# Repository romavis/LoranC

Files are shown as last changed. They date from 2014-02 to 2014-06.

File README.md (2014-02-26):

LORAN C (USSR "Chayka") receiver project
----

####Initial idea of project:
To build Loran-C navigational receiver with digital signal processing.  
Loran-C is (was?) a ground-based longwave navigational system working on frequency of 100 KHz, that was heavely used both by civilians and military prior to wide GPS adoption.

Receiver should also be able to lock onto signal of USSR "Chayka" system, similar to Loran-C, due to my location (nearest transmitter chain is "Chayka" GRI 8000)

####Licensed under:



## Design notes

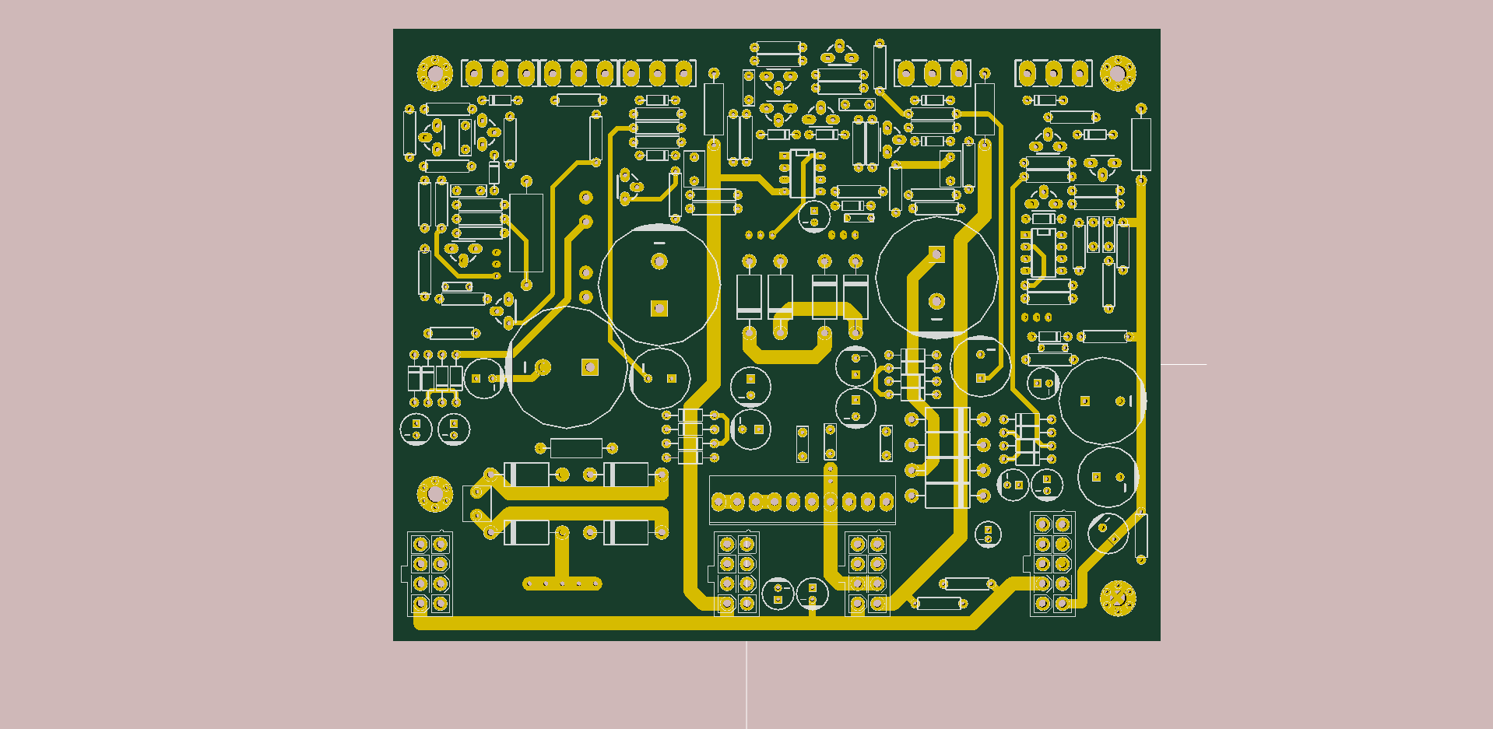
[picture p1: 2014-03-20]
hardware/power_supply/pcb_plots/power_supply_front.png

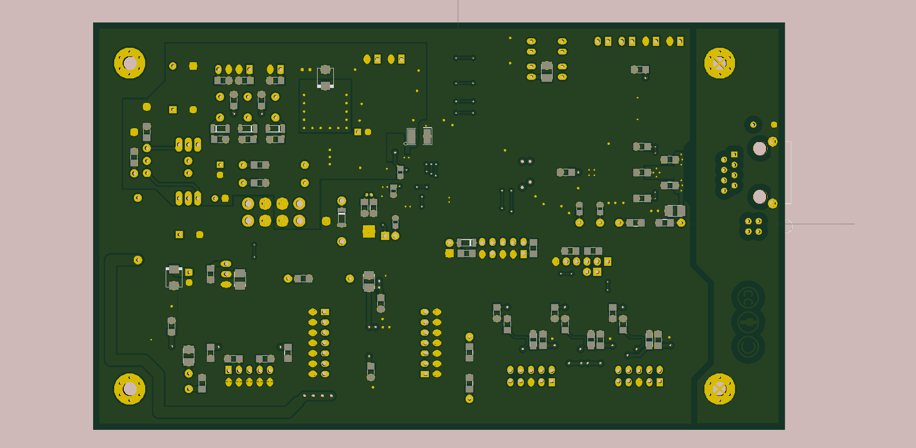
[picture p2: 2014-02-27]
hardware/proc_board/pcb_plots/loran_c_proc_board_back.png

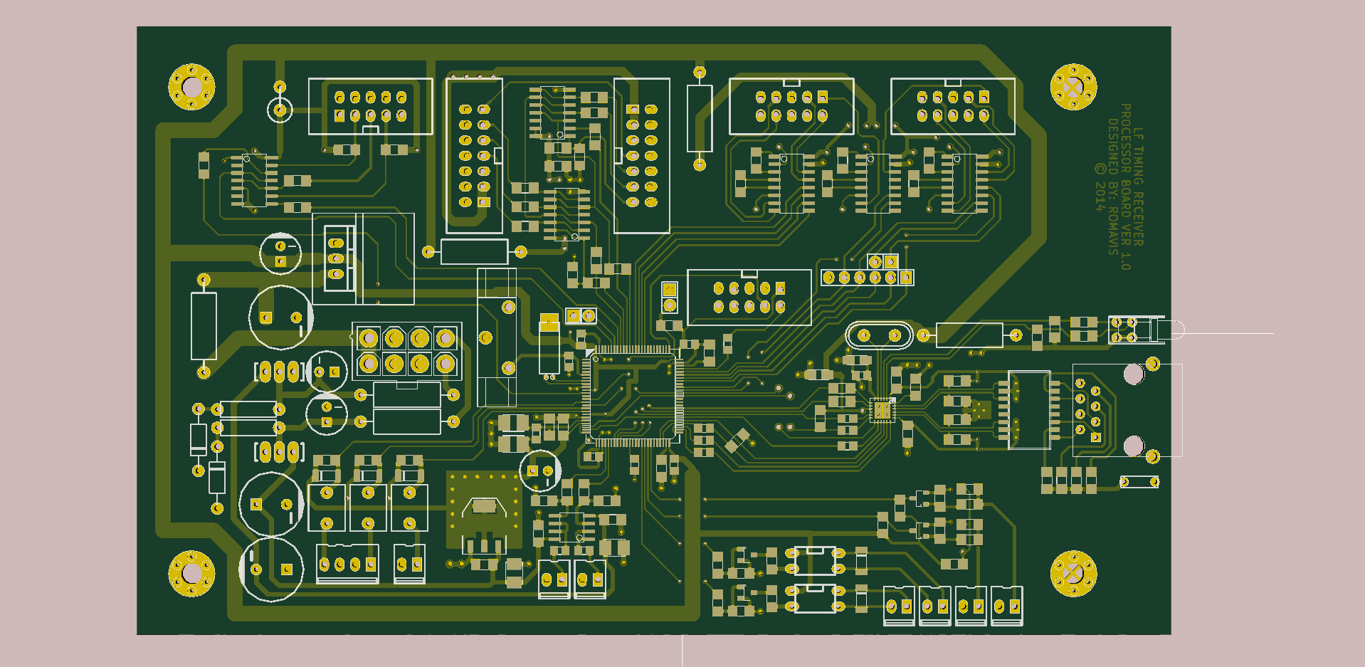
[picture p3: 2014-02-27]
hardware/proc_board/pcb_plots/loran_c_proc_board_front.png

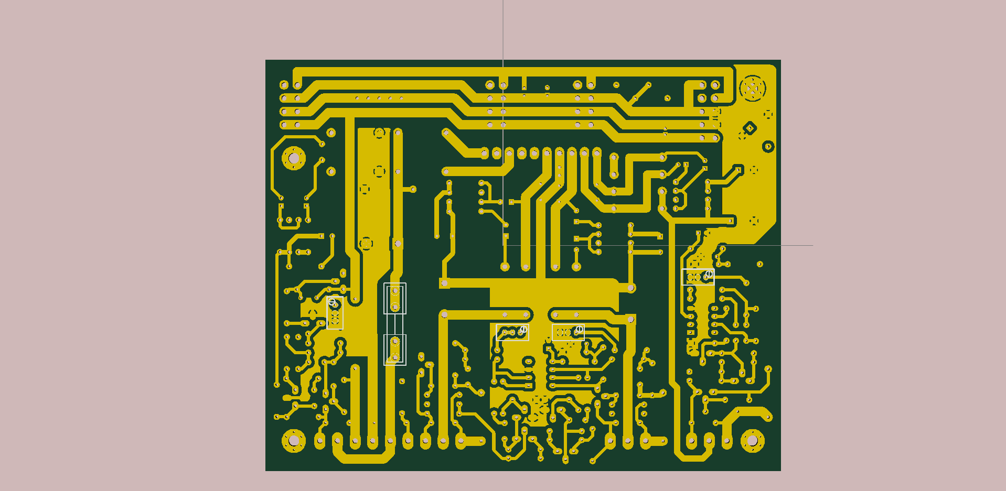
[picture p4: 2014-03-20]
hardware/power_supply/pcb_plots/power_supply_bottom.png

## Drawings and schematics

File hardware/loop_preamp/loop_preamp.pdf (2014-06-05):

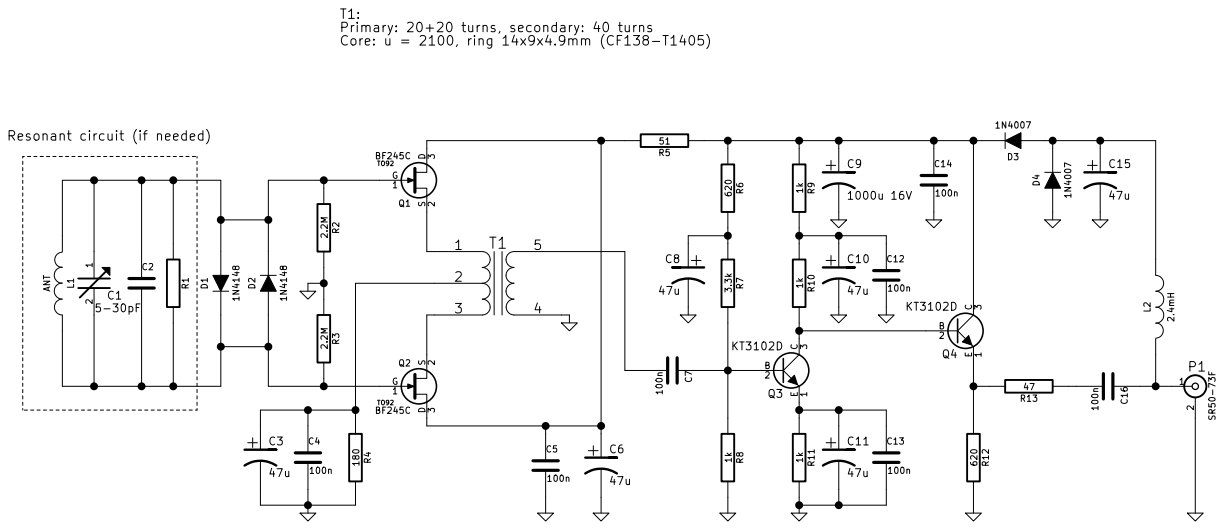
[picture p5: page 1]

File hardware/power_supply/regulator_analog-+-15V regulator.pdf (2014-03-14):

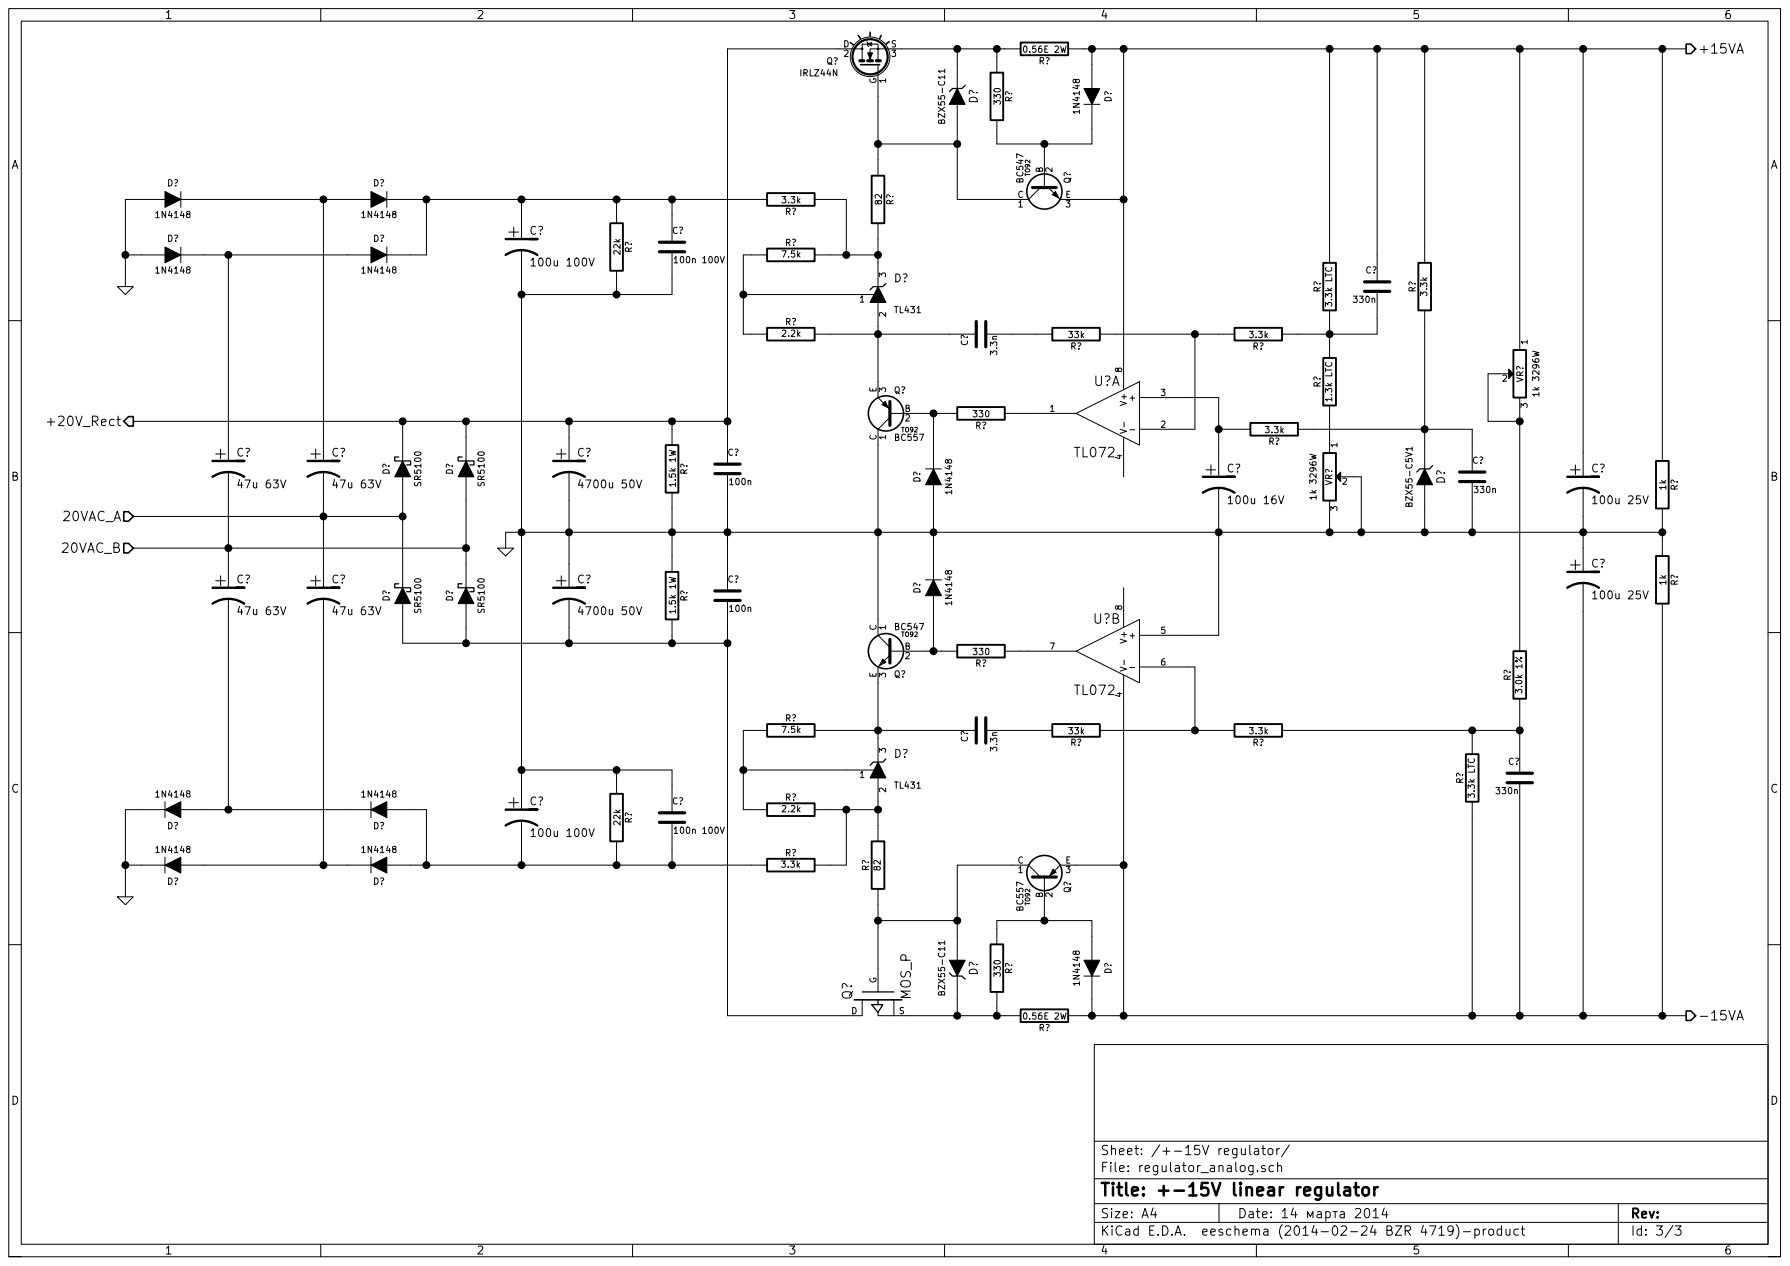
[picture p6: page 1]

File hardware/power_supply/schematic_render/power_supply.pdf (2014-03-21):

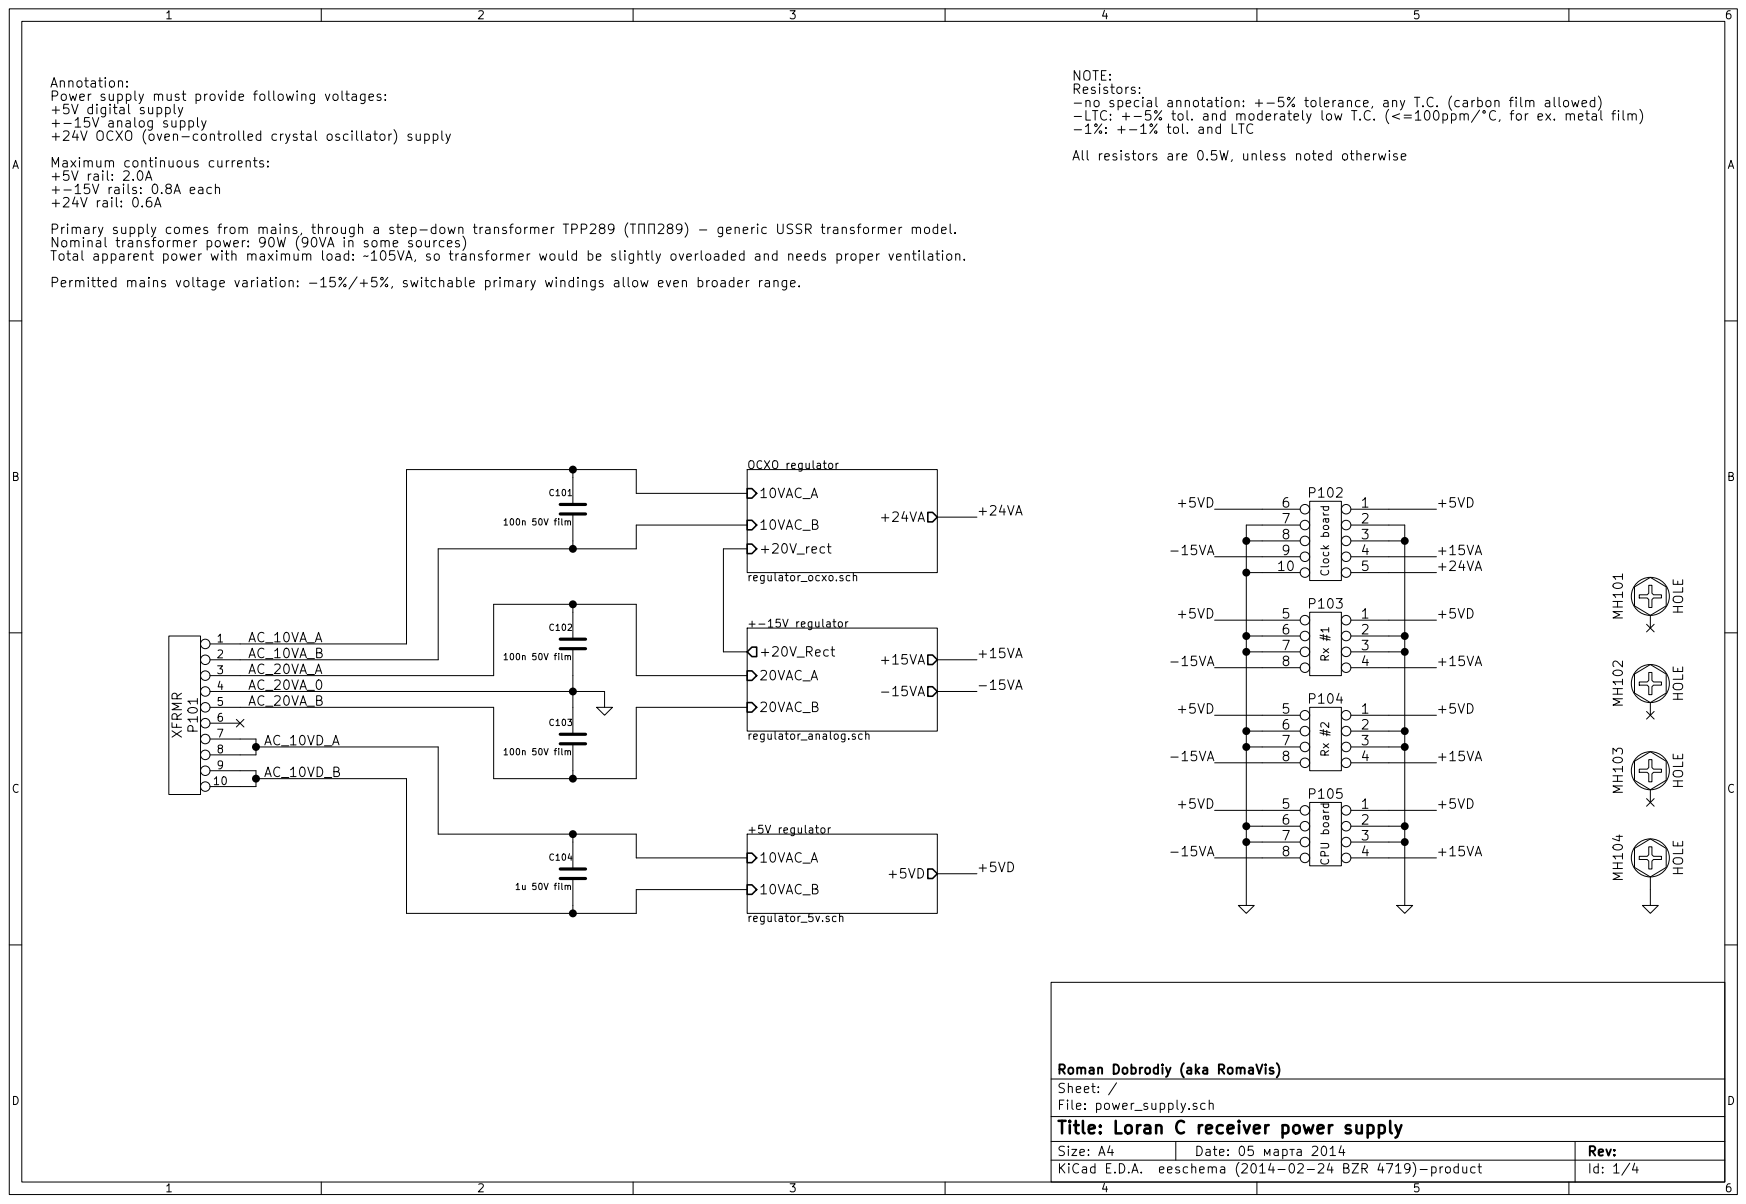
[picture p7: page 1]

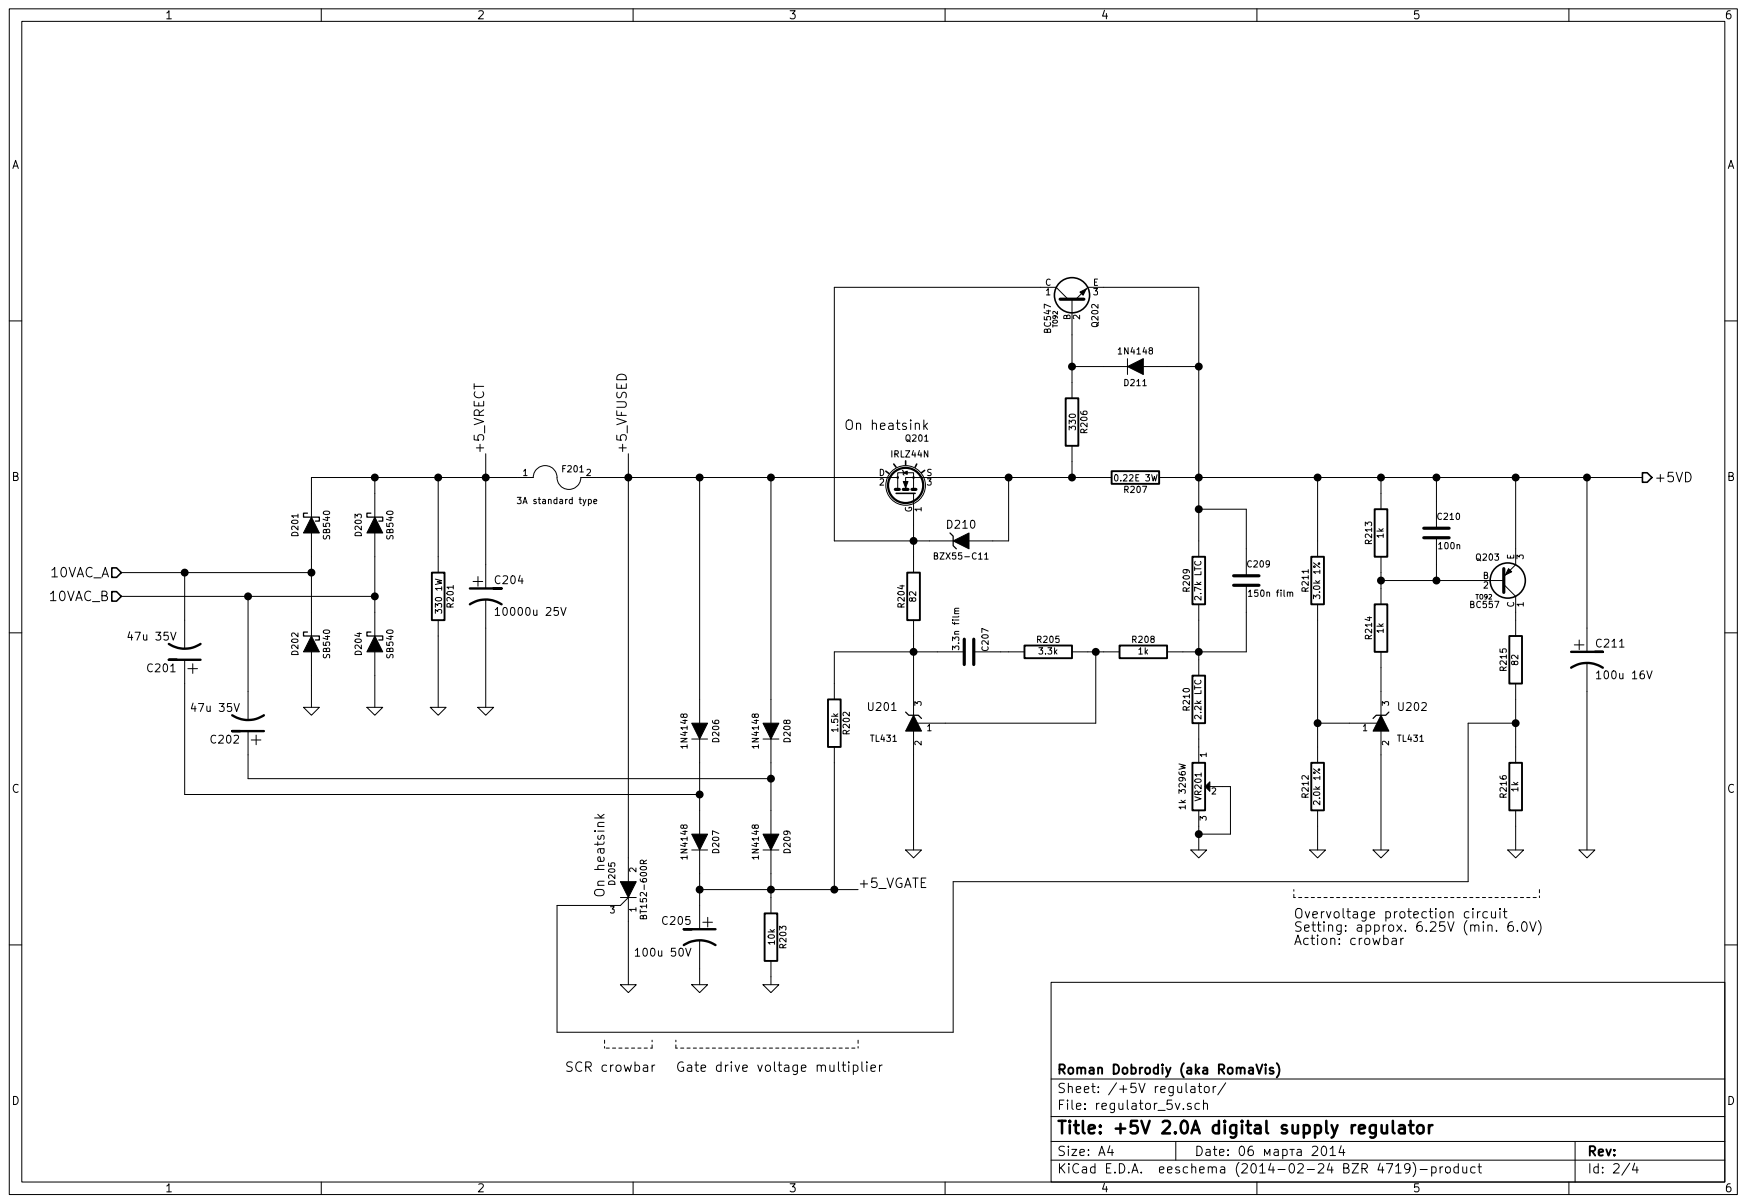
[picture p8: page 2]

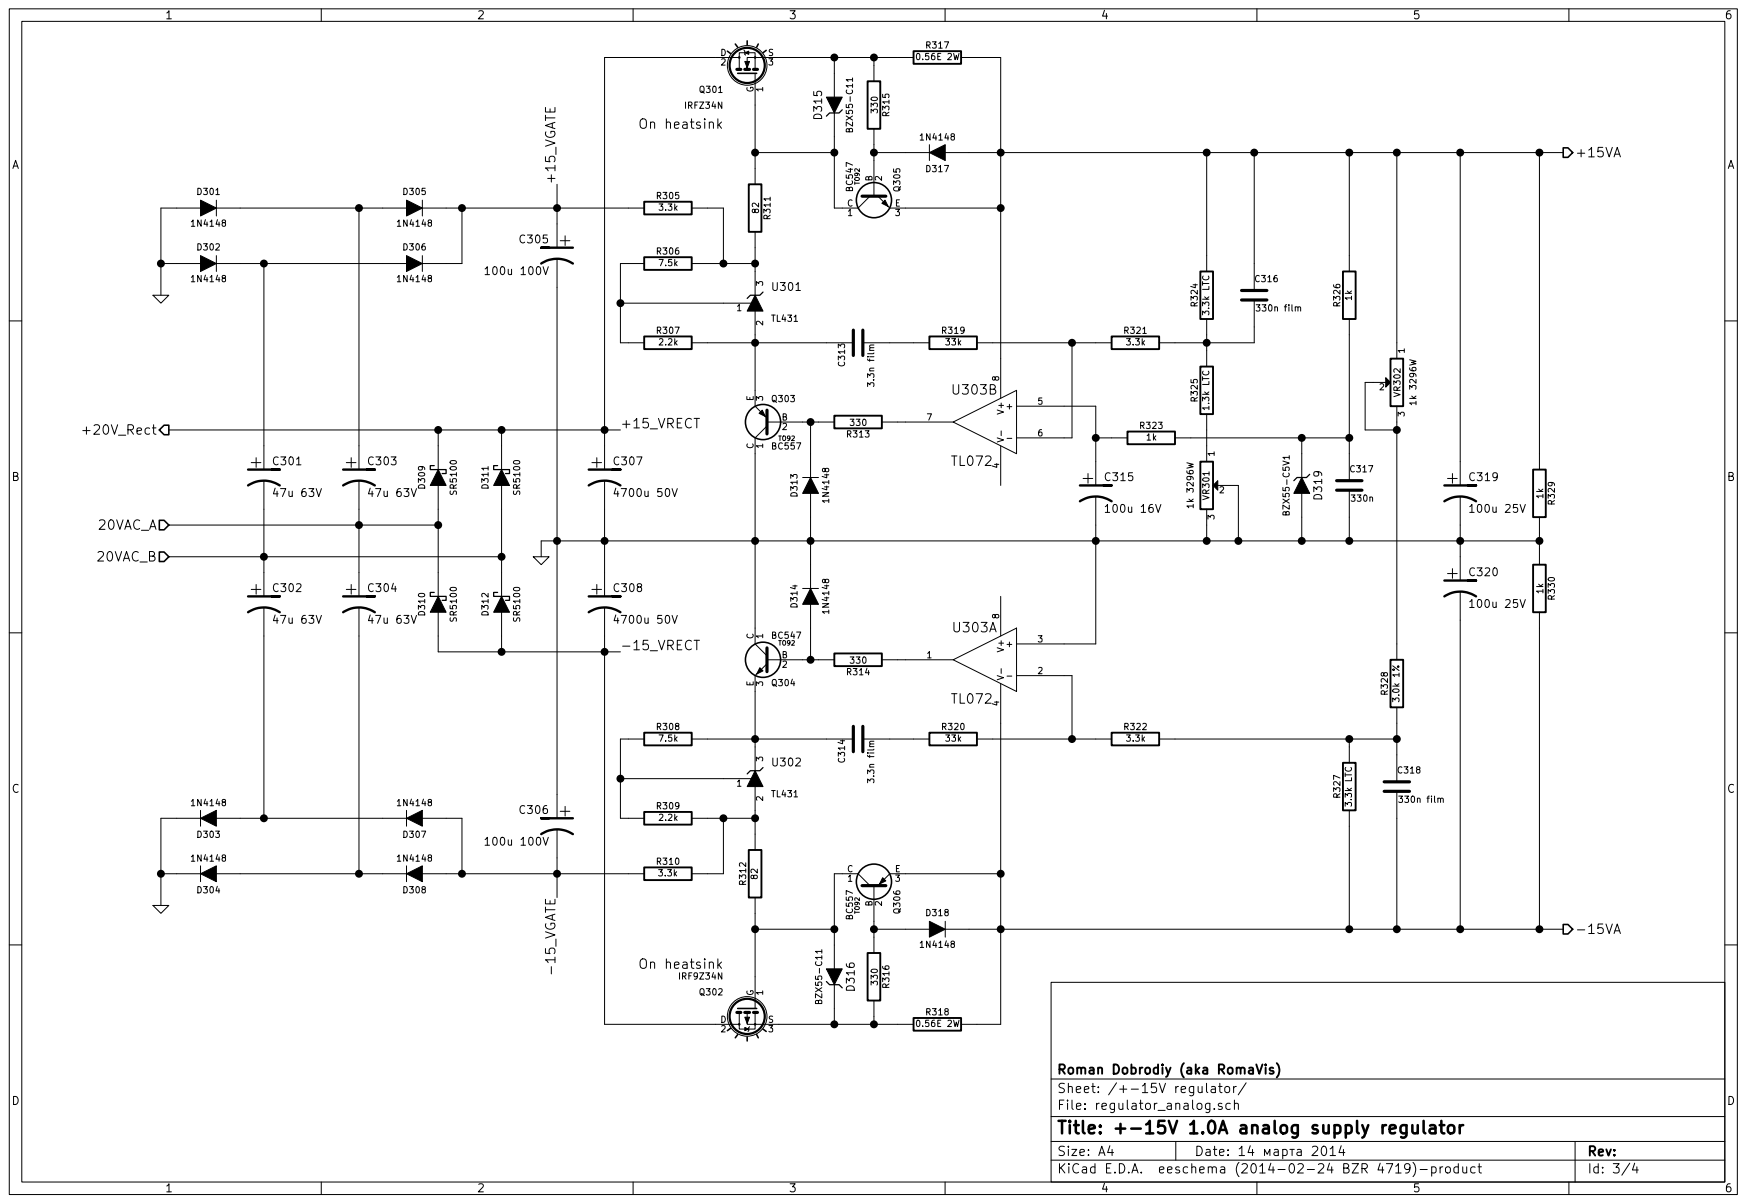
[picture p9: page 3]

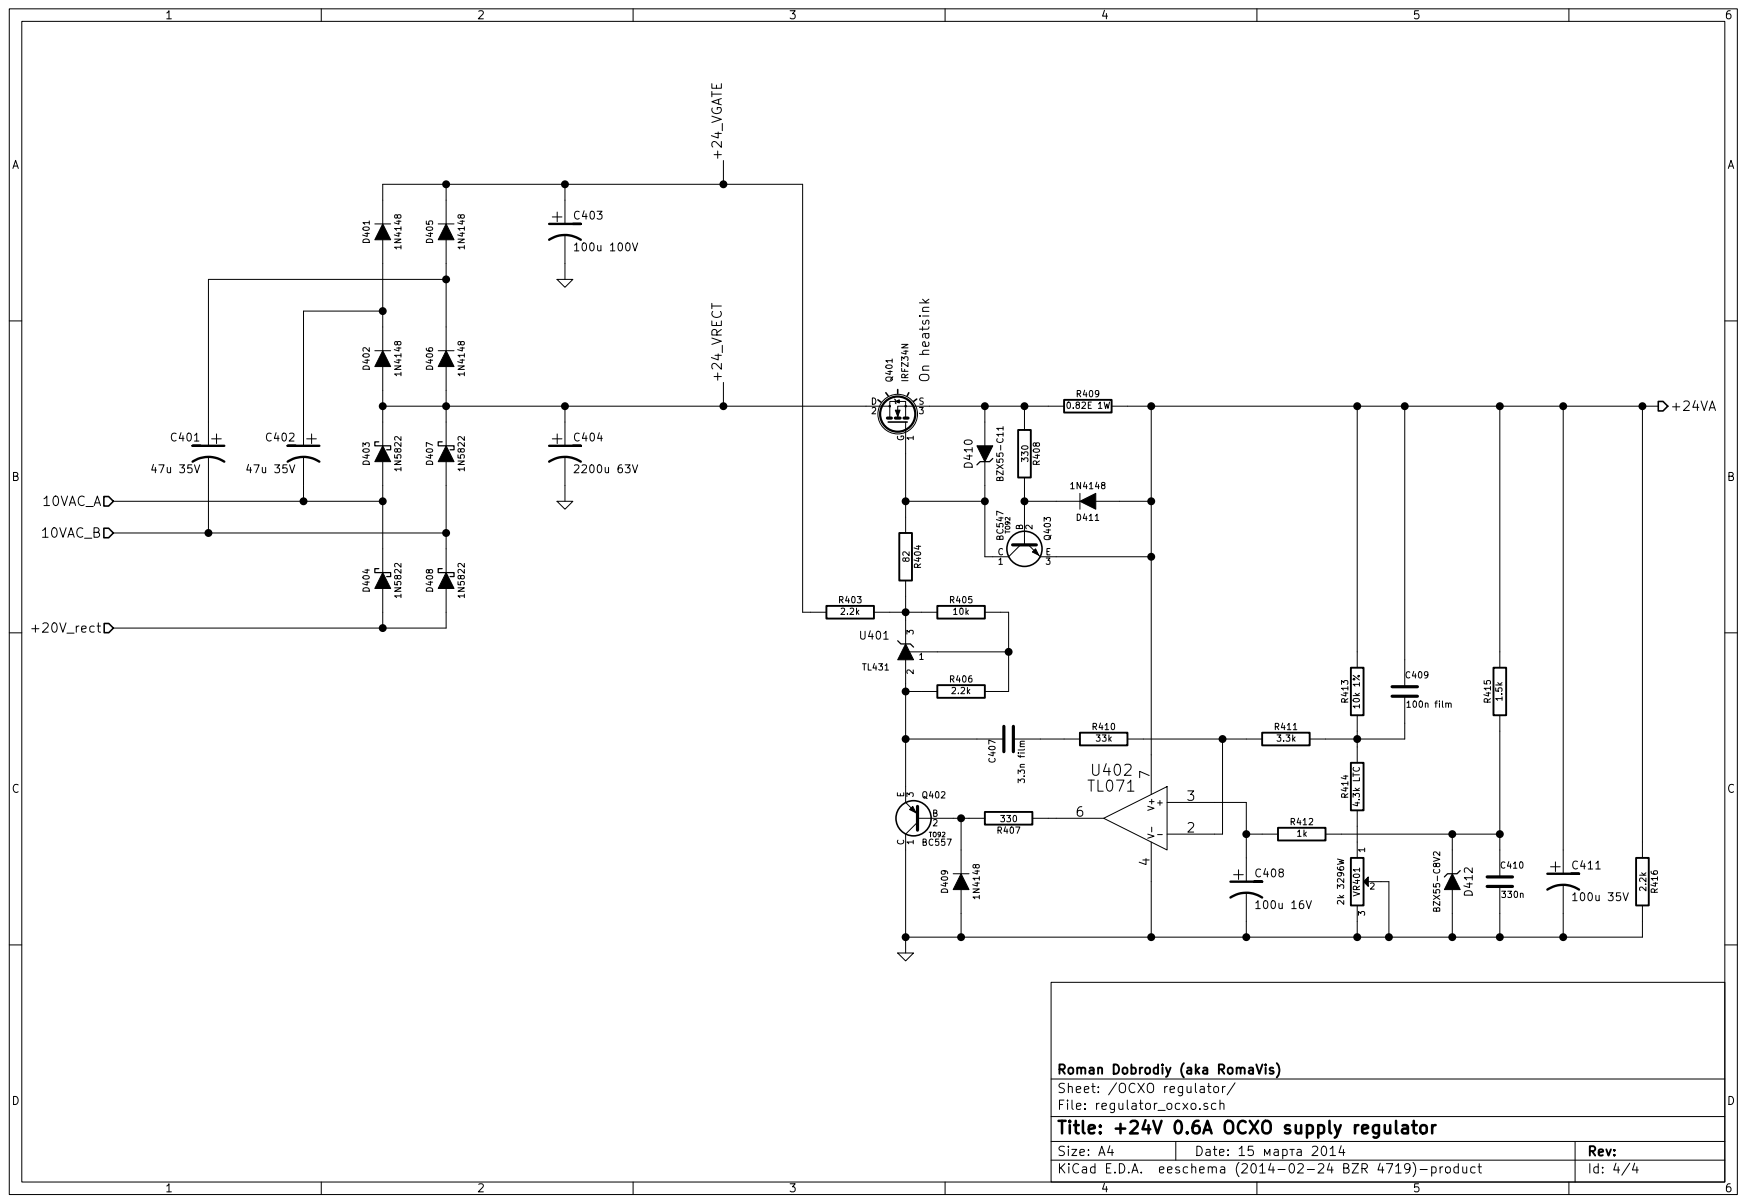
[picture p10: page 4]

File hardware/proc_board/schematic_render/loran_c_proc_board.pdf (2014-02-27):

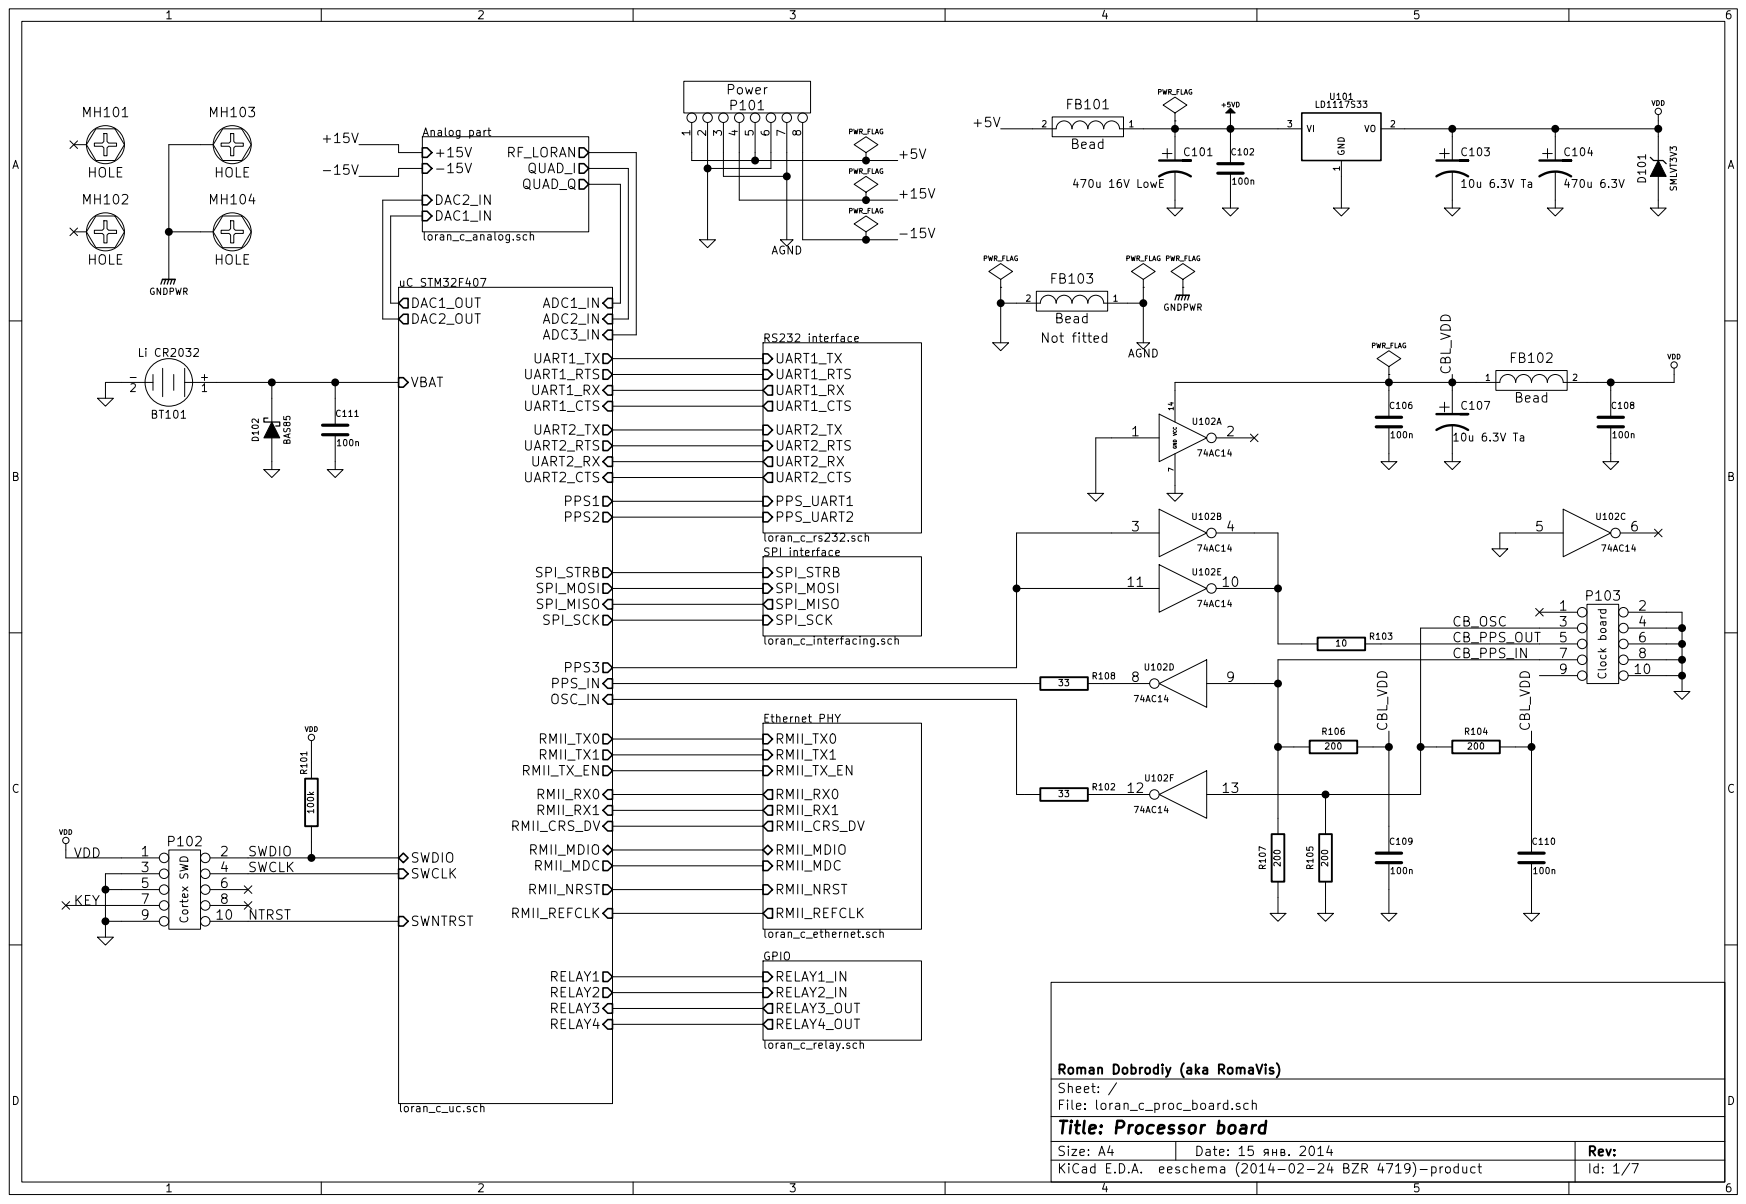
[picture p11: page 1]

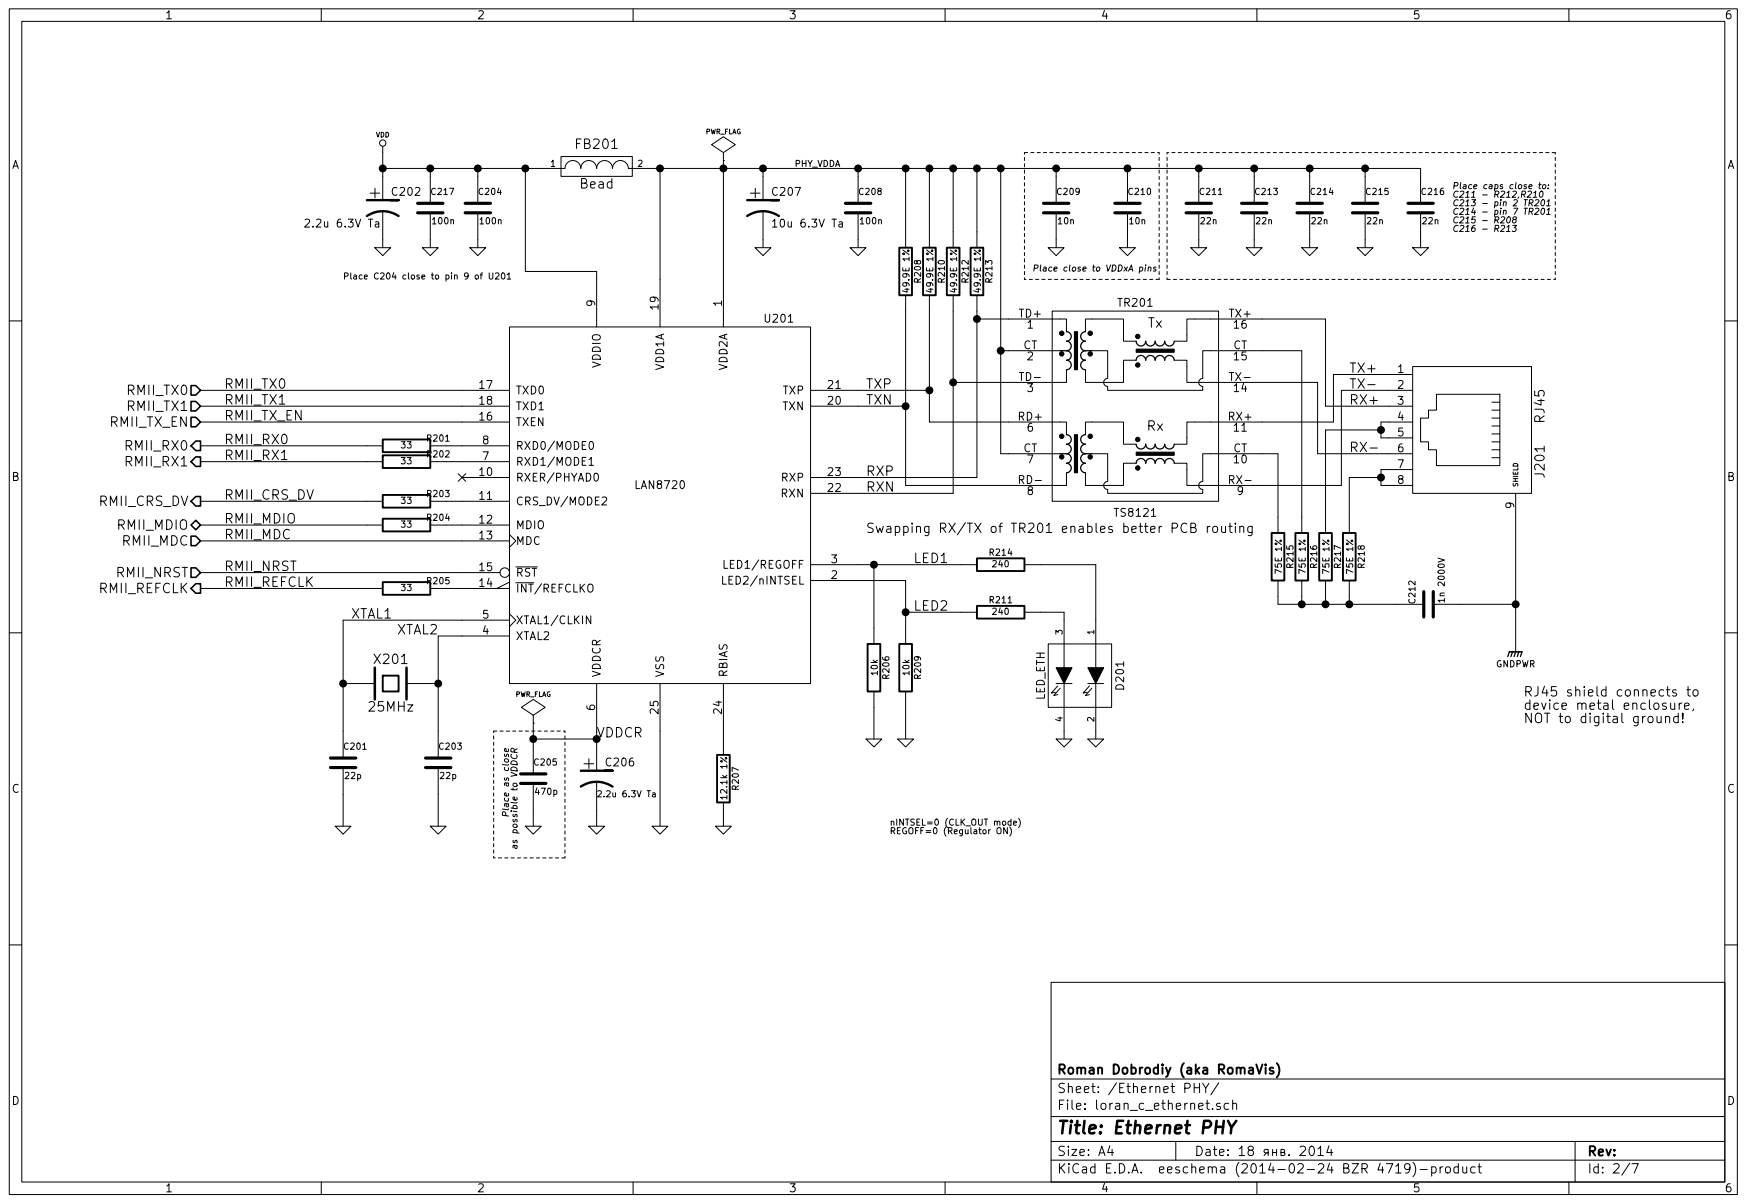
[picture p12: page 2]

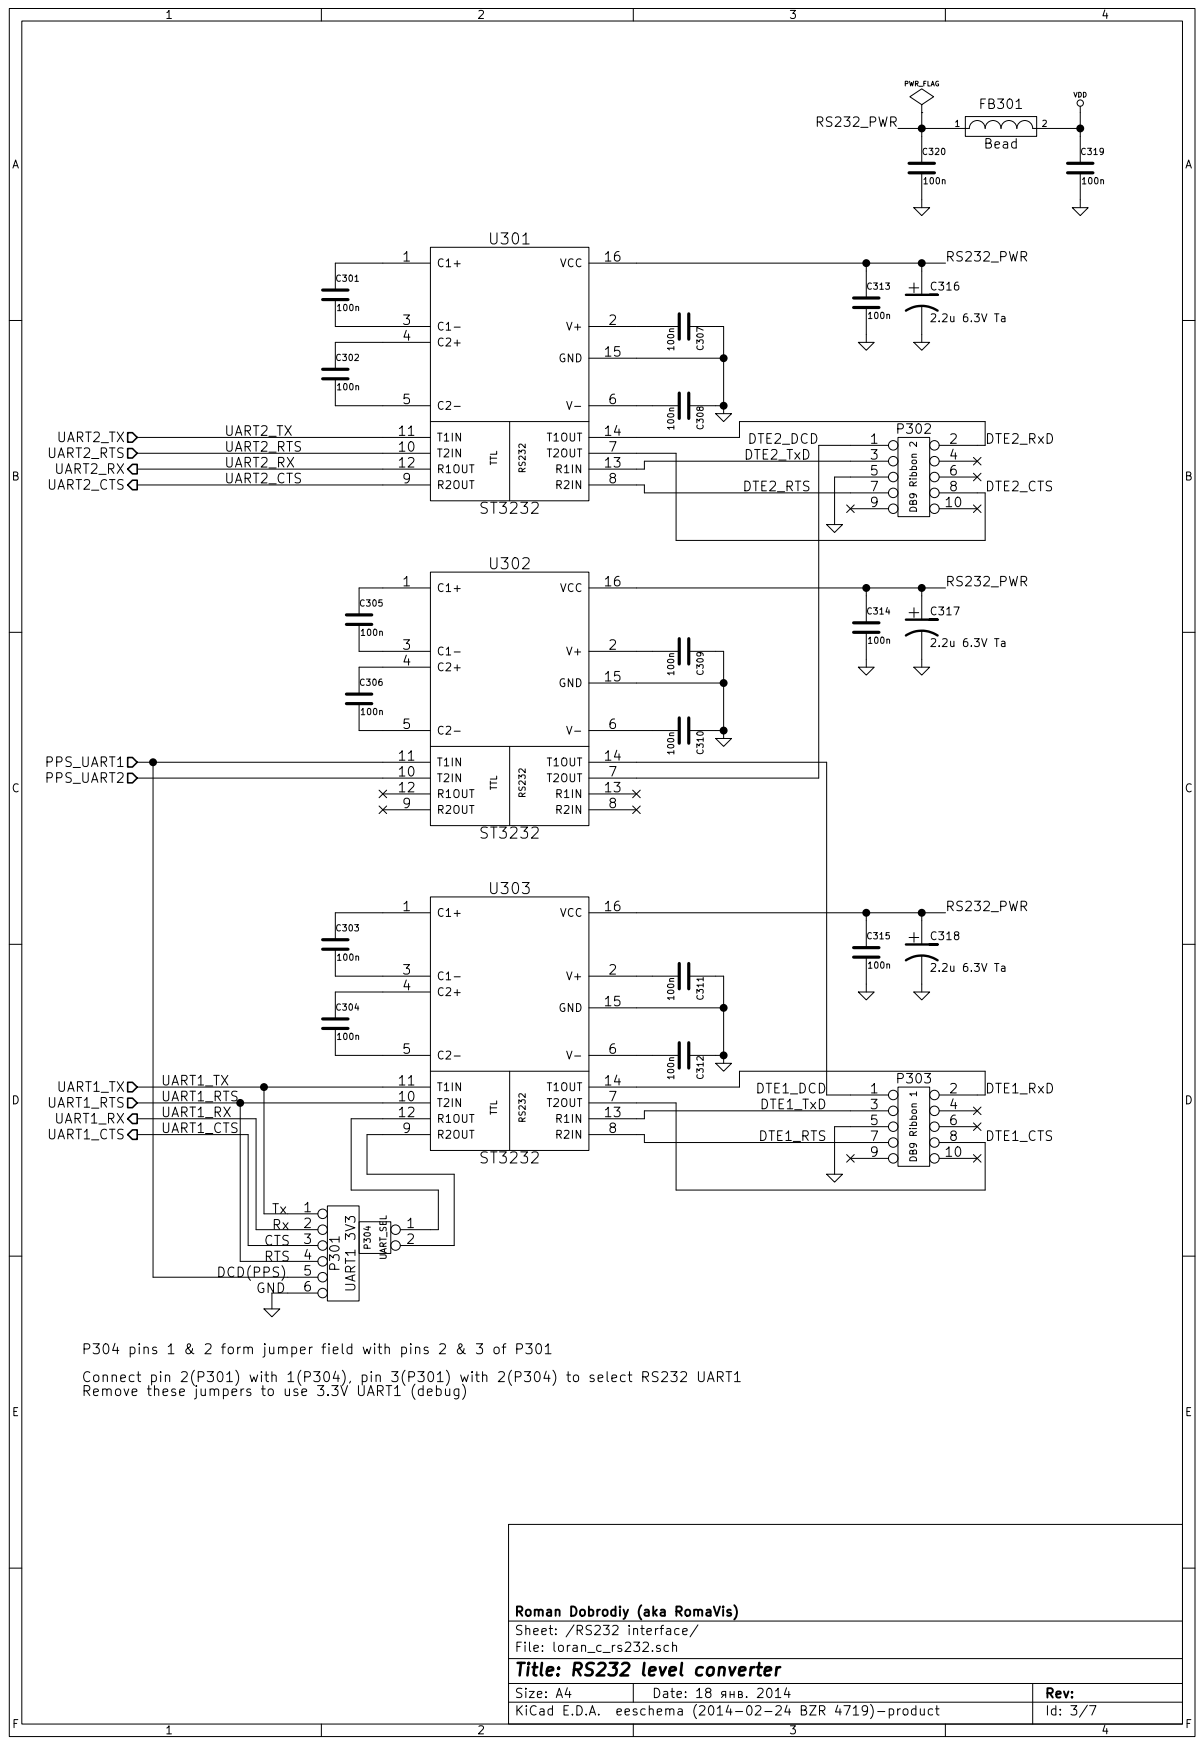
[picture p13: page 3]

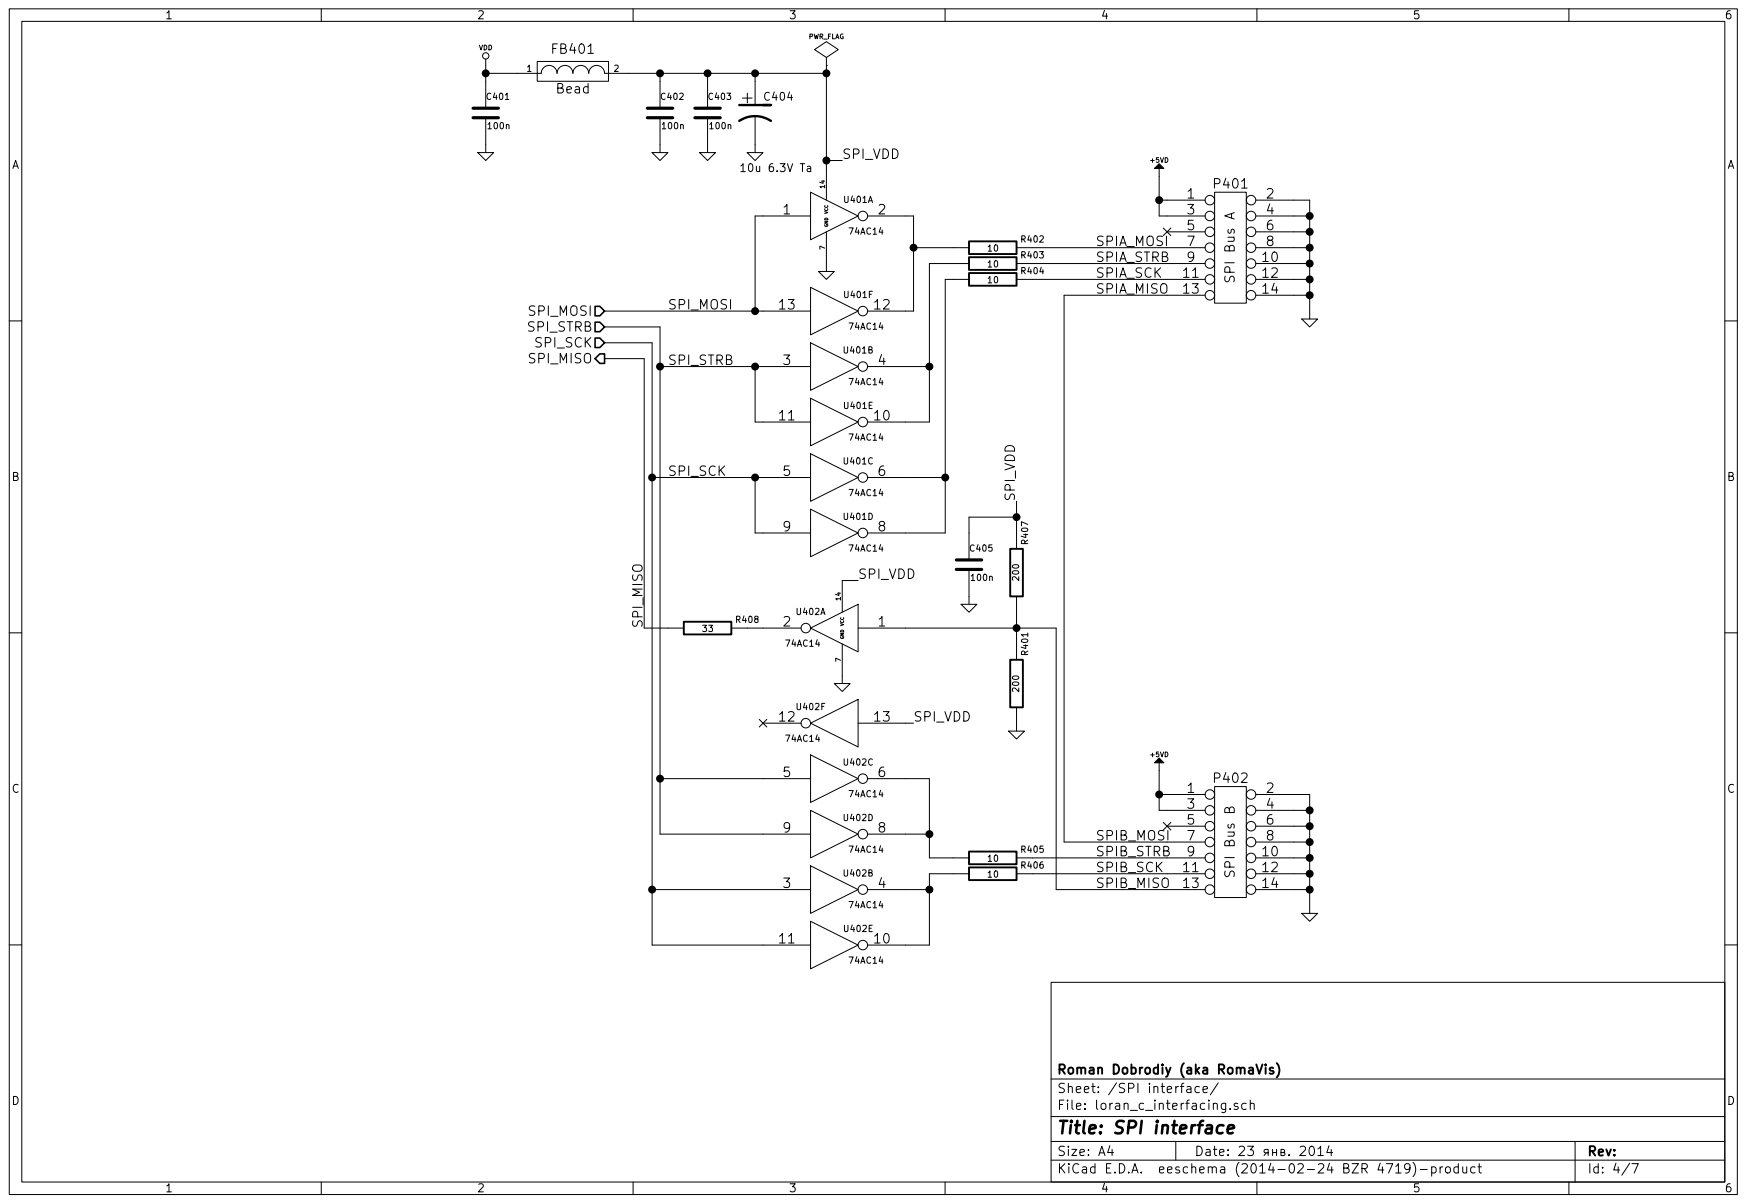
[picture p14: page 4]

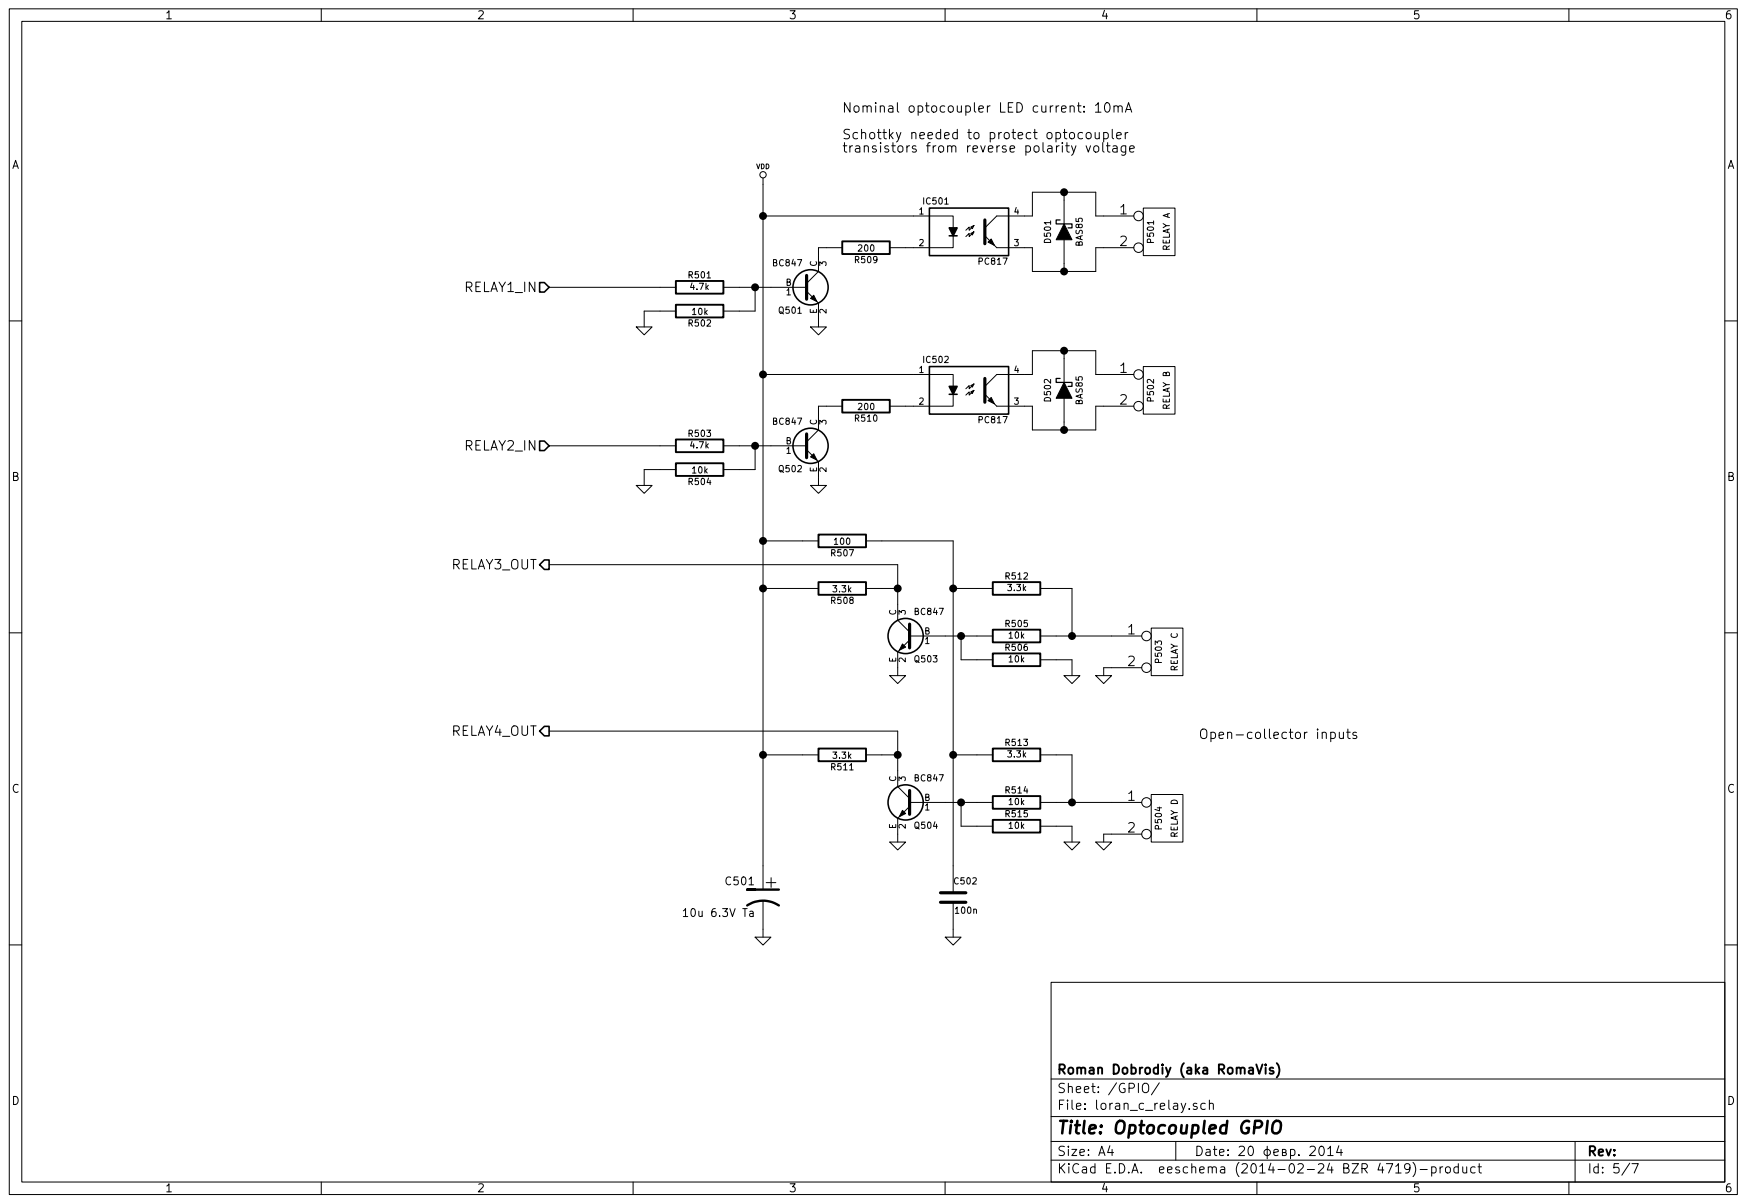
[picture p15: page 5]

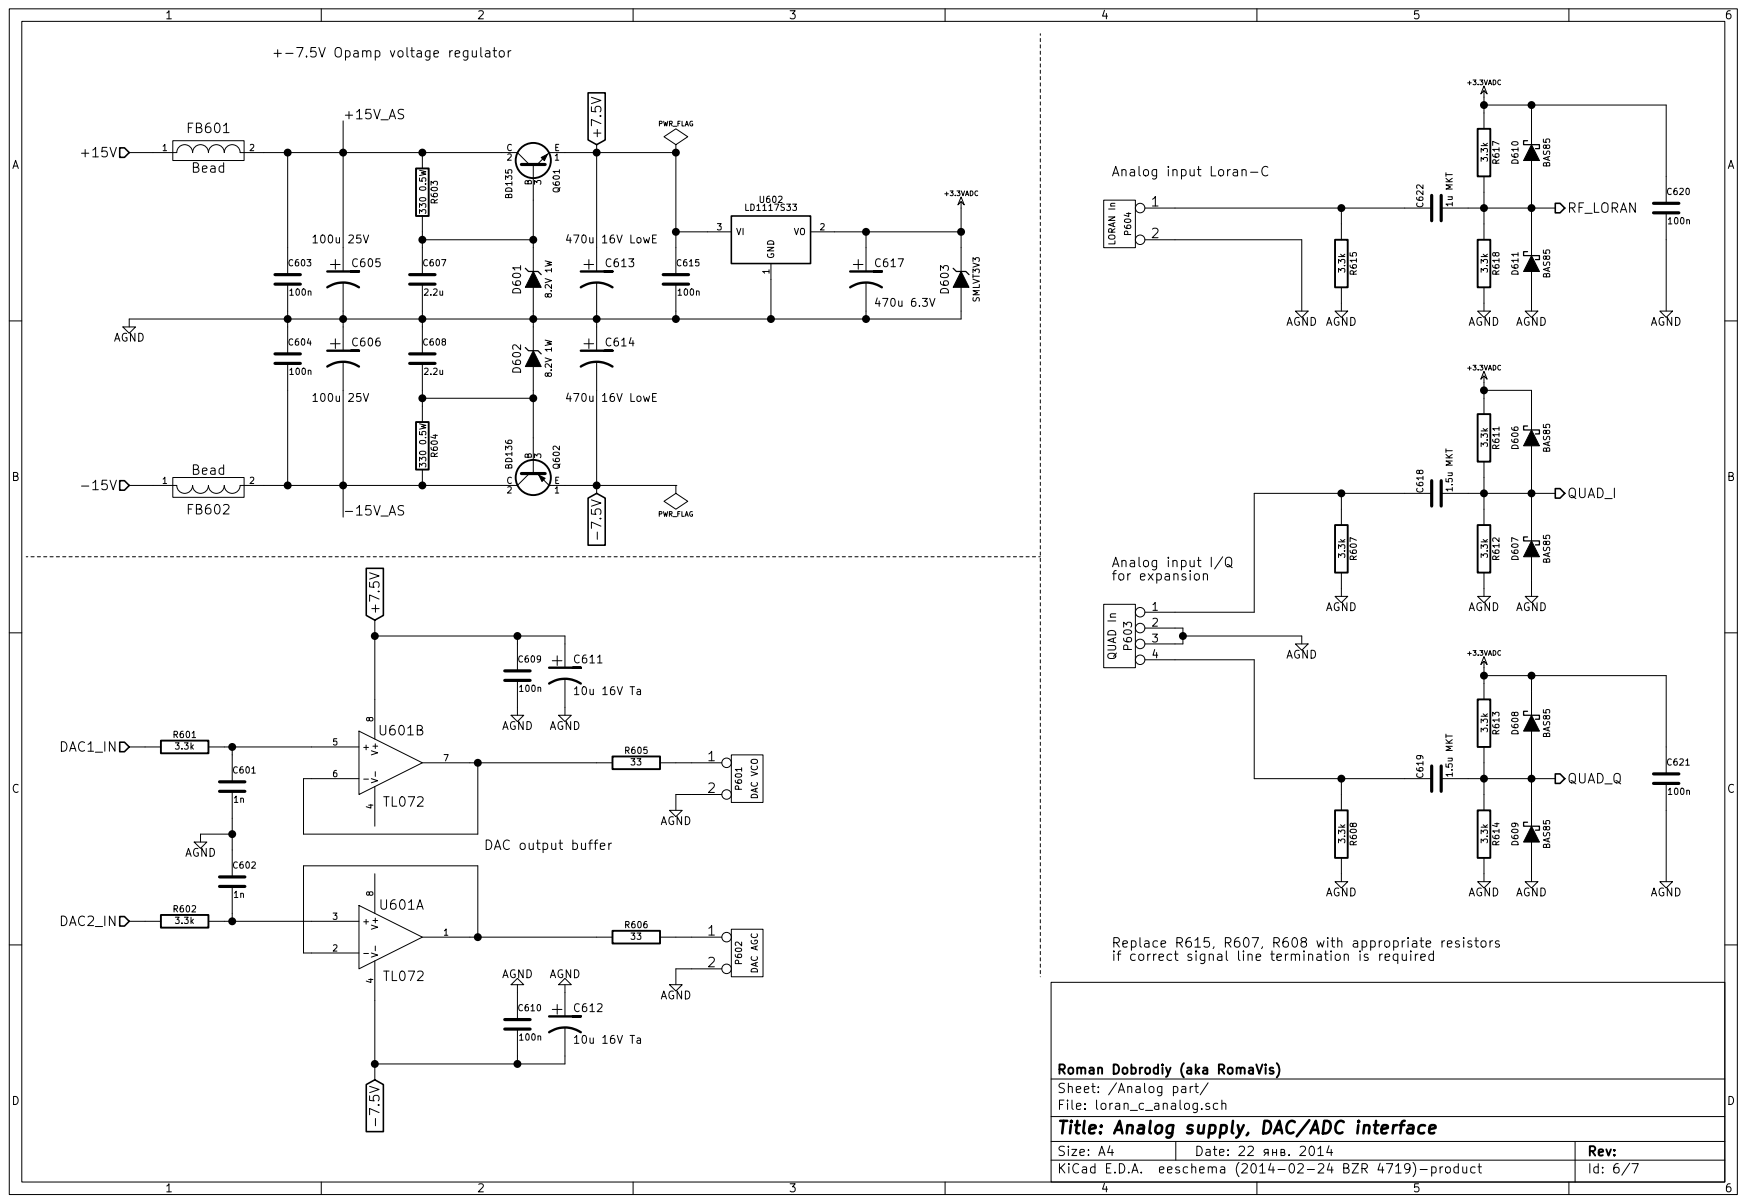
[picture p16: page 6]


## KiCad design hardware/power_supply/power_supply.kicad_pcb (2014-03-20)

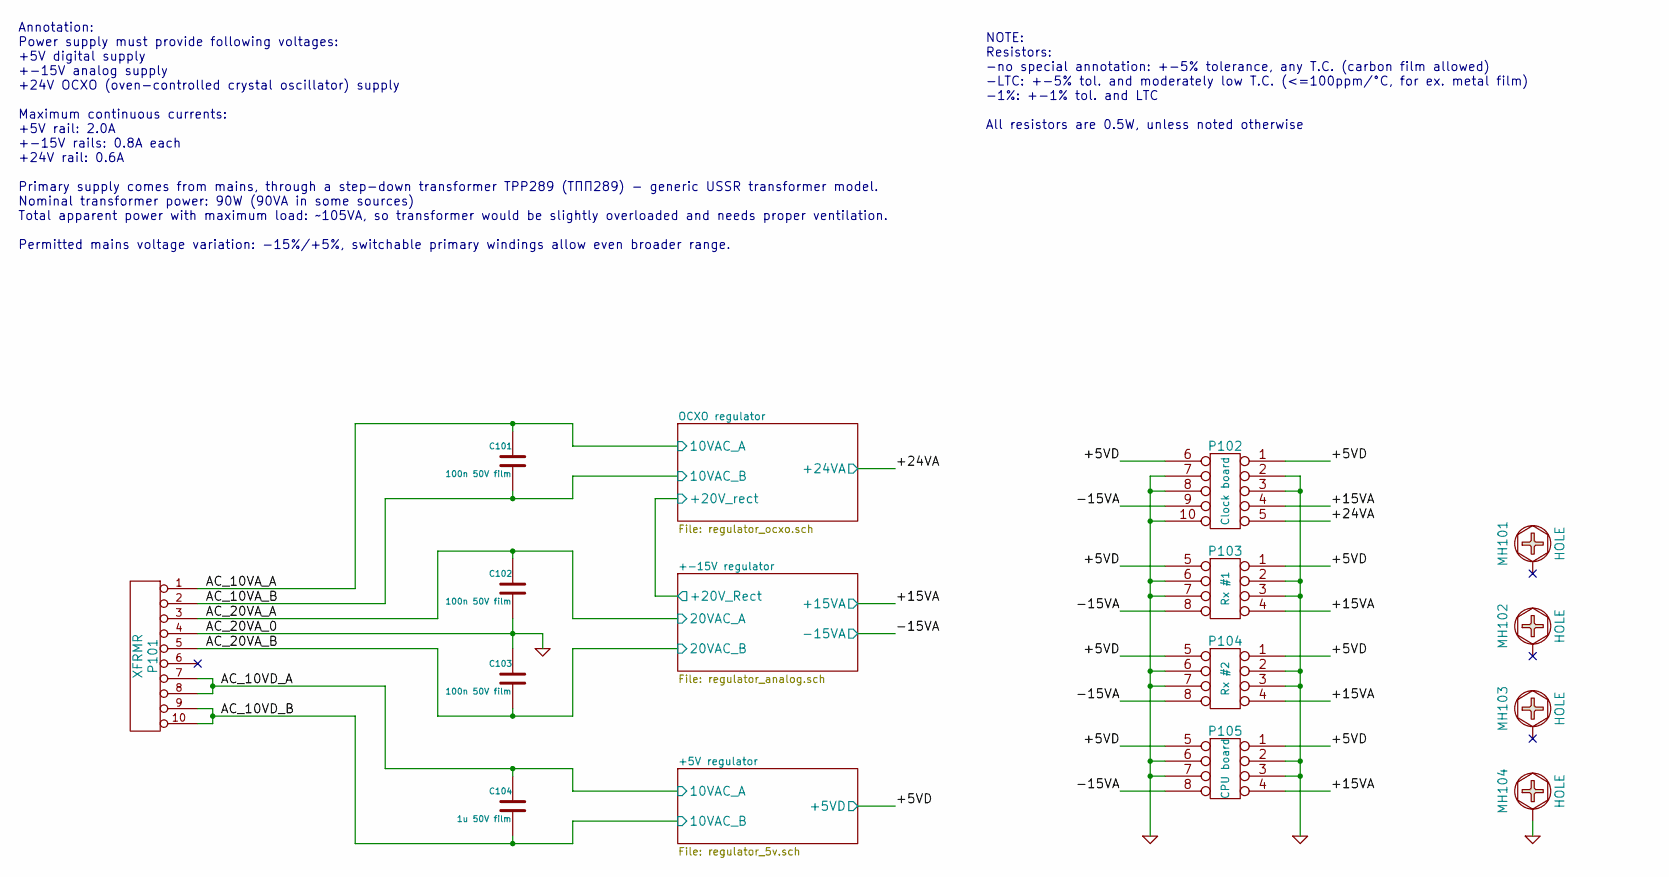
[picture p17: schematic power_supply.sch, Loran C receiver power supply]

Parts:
C101, C102, C103: 100n 50V film
C104: 1u 50V film
MH101, MH102, MH103, MH104: HOLE
P101: XFRMR
P102: Clock board
P103: Rx #1
P104: Rx #2
P105: CPU board

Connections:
/+5V regulator/10VAC_A: C104.1, P101.7, P101.8; also elsewhere on the board
/+5V regulator/10VAC_B: C104.2, P101.9, P101.10; also elsewhere on the board
/+5V regulator/+5VD: P102.1, P102.6, P103.1, P103.5, P104.1, P104.5, P105.1, P105.5; also elsewhere on the board
/+-15V regulator/20VAC_A: C102.1, P101.3; also elsewhere on the board
/+-15V regulator/20VAC_B: C103.2, P101.5; also elsewhere on the board
/+-15V regulator/+15VA: P102.4, P103.4, P104.4, P105.4; also elsewhere on the board
/+-15V regulator/-15VA: P102.9, P103.8, P104.8, P105.8; also elsewhere on the board
/OCXO regulator/10VAC_A: C101.1, P101.1; also elsewhere on the board
/OCXO regulator/10VAC_B: C101.2, P101.2; also elsewhere on the board
/OCXO regulator/+24VA: P102.5; also elsewhere on the board
GND: C102.2, C103.1, MH104.1, P101.4, P102.2, P102.3, P102.7, P102.8, P102.10, P103.2, P103.3, P103.6, P103.7, P104.2, P104.3, P104.6, P104.7, P105.2, P105.3, P105.6, P105.7; also elsewhere on the board

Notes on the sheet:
Annotation: Power supply must provide following voltages: +5V digital supply +-15V analog supply +24V OCXO (oven-controlled crystal oscillator) supply Maximum continuous currents: +5V rail: 2.0A +-15V rails: 0.8A each +24V rail: 0.6A Primary supply comes from mains, through a step-down transformer 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
NOTE: Resistors: -no special annotation: +-5% tolerance, any T.C. (carbon film allowed) -LTC: +-5% tol. and moderately low T.C. (<=100ppm/°C, for ex. metal film) -1%: +-1% tol. and LTC All resistors are 0.5W, unless noted otherwise

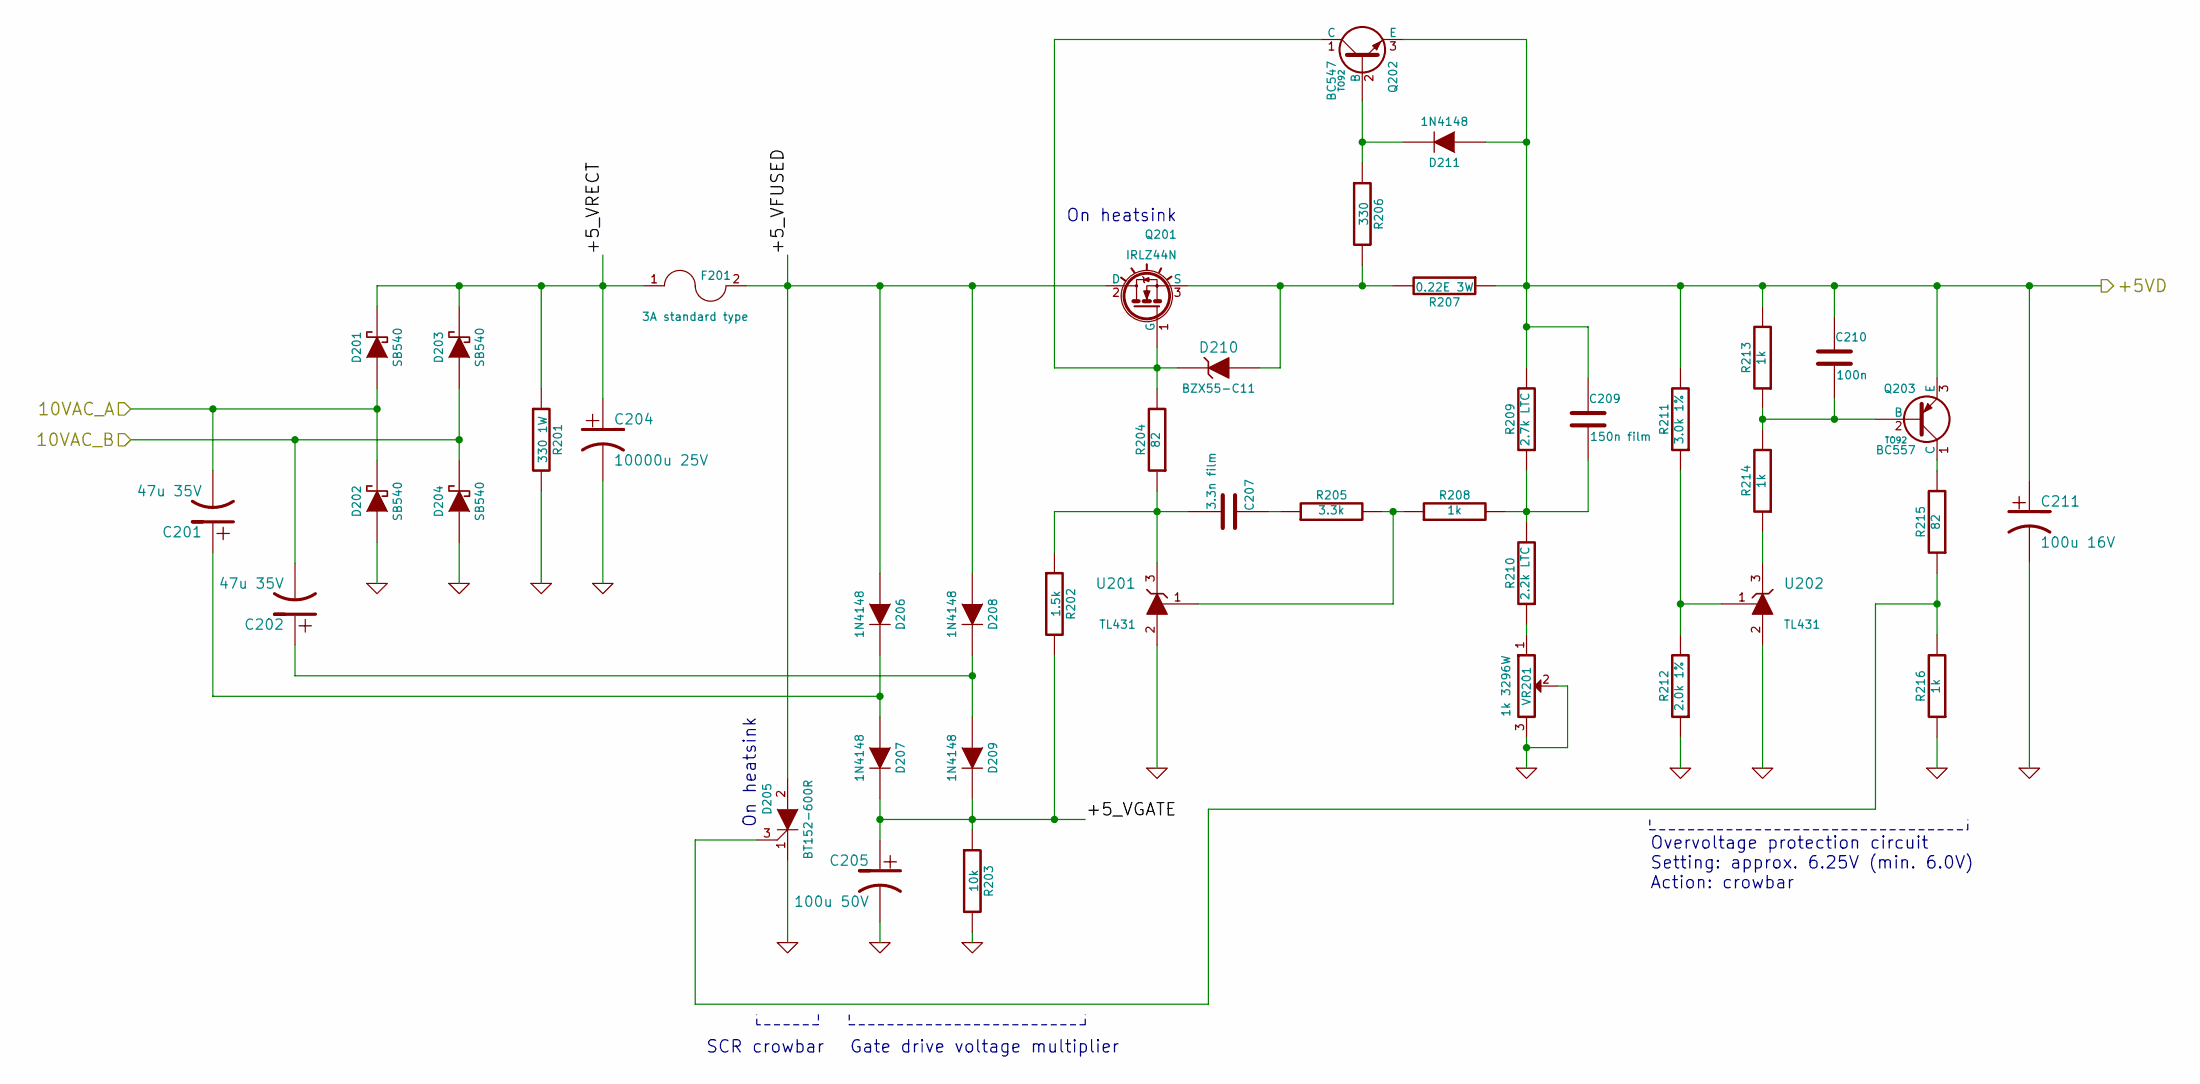
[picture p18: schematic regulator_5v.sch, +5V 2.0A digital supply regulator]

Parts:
C201, C202: 47u 35V
C204: 10000u 25V
C205: 100u 50V
C207: 3.3n film
C209: 150n film
C210: 100n
C211: 100u 16V
D201, D202, D203, D204: SB540
D205: BT152-600R
D206, D207, D208, D209, D211: 1N4148
D210: BZX55-C11
F201: 3A standard type
Q201: IRLZ44N
Q202: BC547; TO92
Q203: BC557; TO92
R201: 330 1W
R202: 1.5k
R203: 10k
R204, R215: 82
R205: 3.3k
R206: 330
R207: 0.22E 3W
R208, R213, R214, R216: 1k
R209: 2.7k LTC
R210: 2.2k LTC
R211: 3.0k 1%
R212: 2.0k 1%
U201, U202: TL431; TO92
VR201: 1k 3296W

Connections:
/+5V regulator/10VAC_A: C201.2, D201.1 (A), D202.2 (K); also elsewhere on the board
/+5V regulator/10VAC_B: C202.2, D203.1 (A), D204.2 (K); also elsewhere on the board
/+5V regulator/+5VD: C209.1, C210.1, C211.1, D211.1 (A), Q202.3 (E), Q203.3 (E), R207.1, R209.2, R211.2, R213.2; also elsewhere on the board
/+5V regulator/+5_VFUSED: D205.2 (A), D206.1 (A), D208.1 (A), F201.2, Q201.2 (D)
/+5V regulator/+5_VGATE: C205.1, D207.2 (K), D209.2 (K), R202.2, R203.1
/+5V regulator/+5_VRECT: C204.1, D201.2 (K), D203.2 (K), F201.1, R201.1
GND: C204.2, C205.2, C211.2, D202.1 (A), D204.1 (A), D205.1 (K), R201.2, R203.2, R212.1, R216.1, U201.2 (A), U202.2 (A), VR201.2, VR201.3; also elsewhere on the board
unnamed: C201.1, D206.2 (K), D207.1 (A)
unnamed: C202.1, D208.2 (K), D209.1 (A)
unnamed: C207.1, R205.1
unnamed: C207.2, R202.1, R204.1, U201.3 (K)
unnamed: C209.2, R208.2, R209.1, R210.2
unnamed: C210.2, Q203.2 (B), R213.1, R214.2
unnamed: D205.3 (G), R215.1, R216.2
unnamed: D210.1 (A), Q201.3 (S), R206.2, R207.2
unnamed: D210.2 (K), Q201.1 (G), Q202.1 (C), R204.2
unnamed: D211.2 (K), Q202.2 (B), R206.1
unnamed: Q203.1 (C), R215.2
unnamed: R205.2, R208.1, U201.1 (Ref)
unnamed: R210.1, VR201.1
unnamed: R211.1, R212.2, U202.1 (Ref)
unnamed: R214.1, U202.3 (K)

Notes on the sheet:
Overvoltage protection circuit Setting: approx. 6.25V (min. 6.0V) Action: crowbar
Gate drive voltage multiplier
SCR crowbar
On heatsink

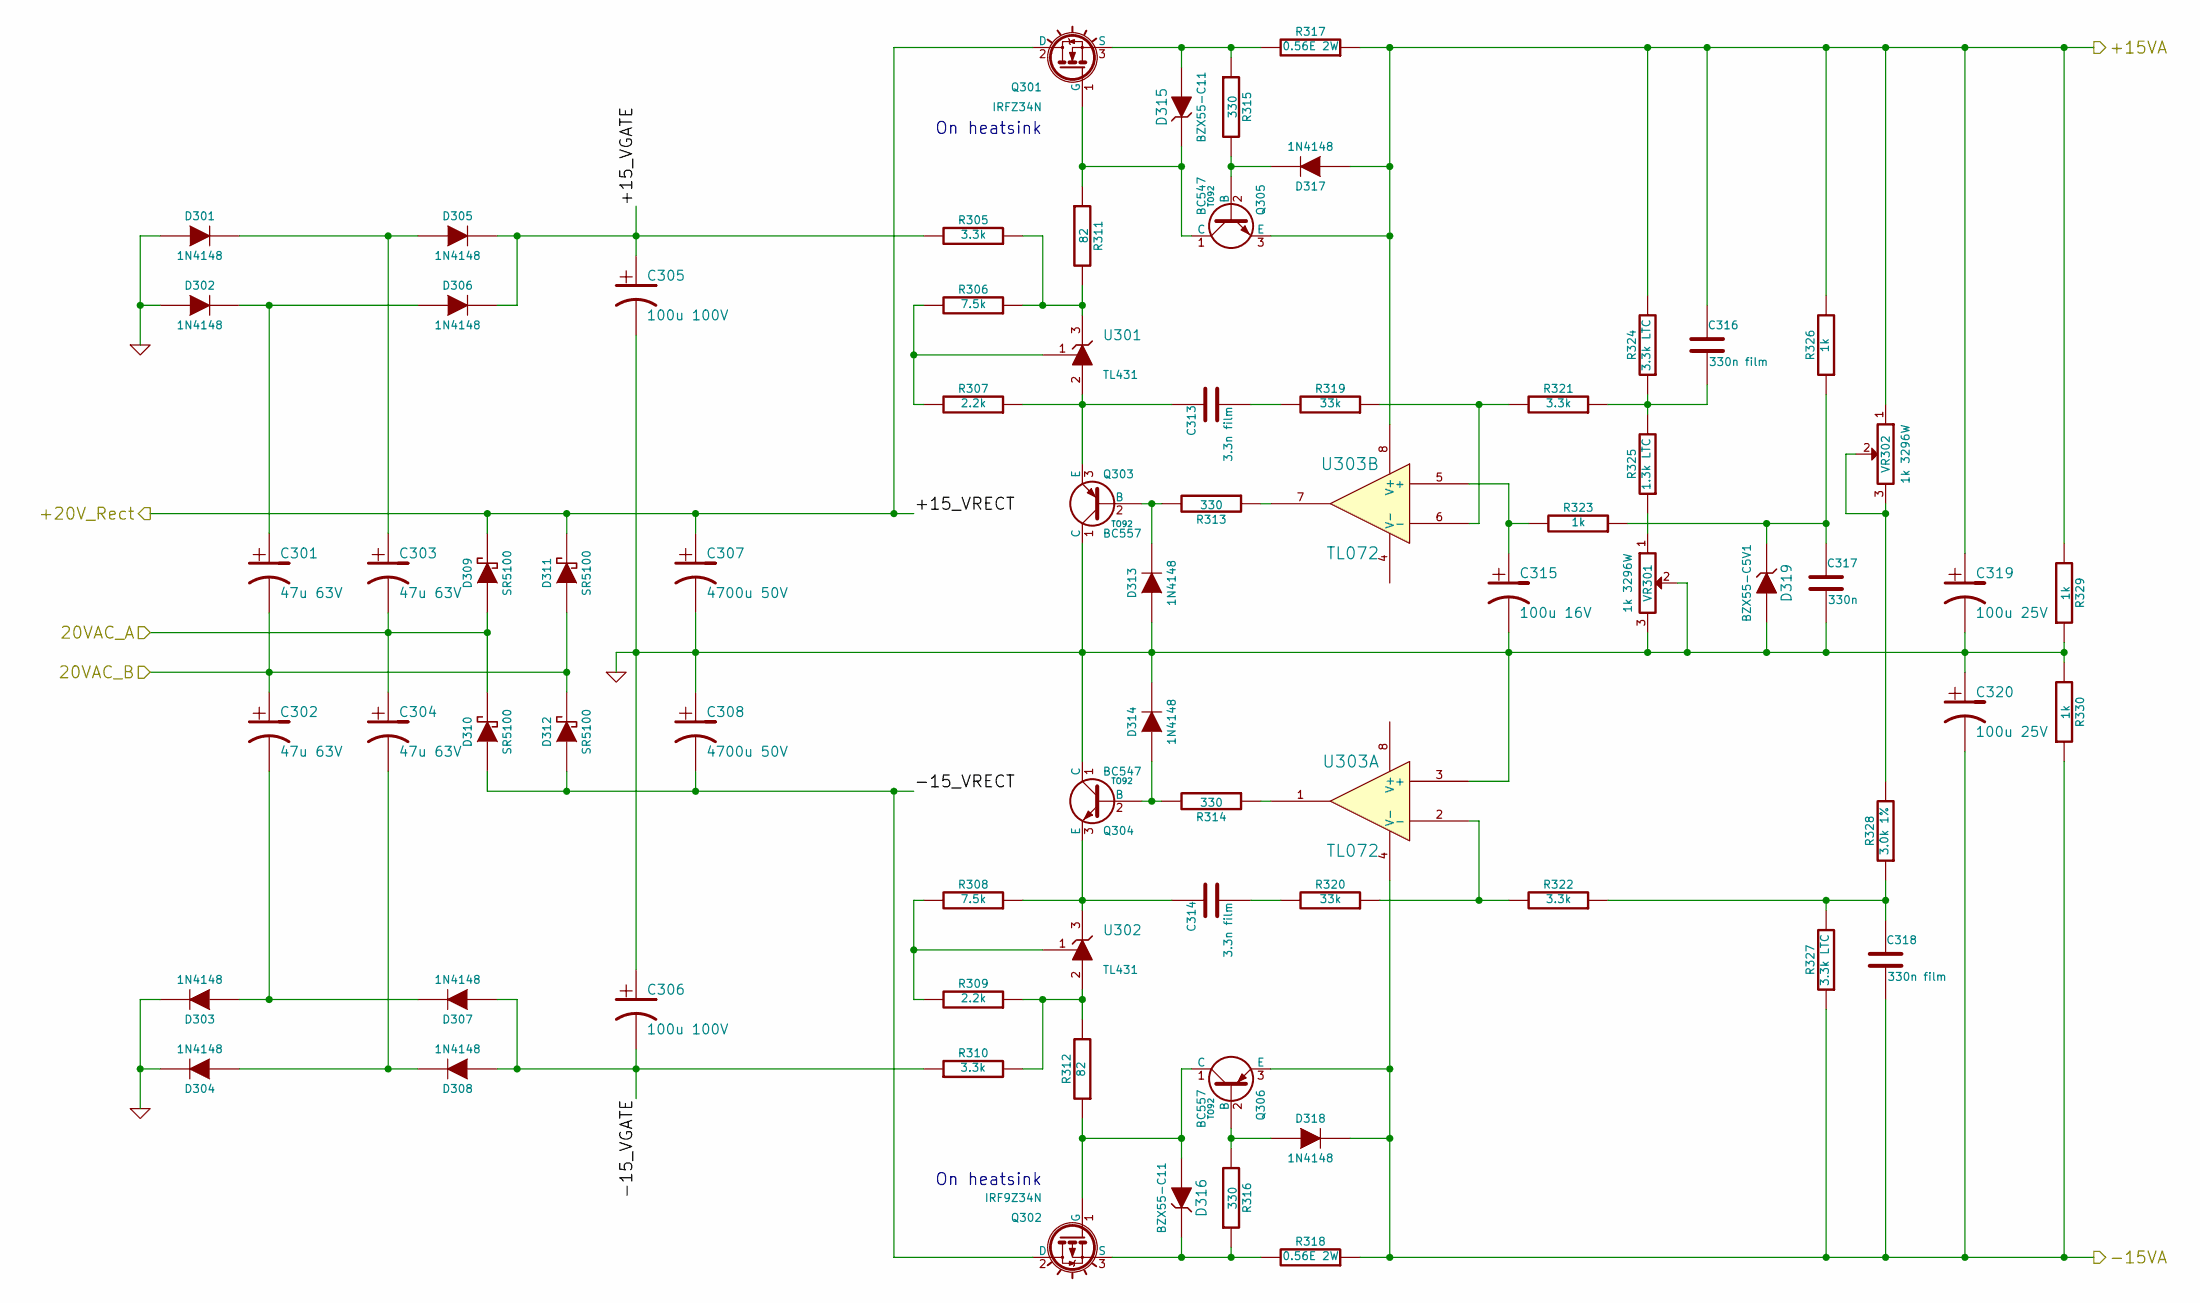
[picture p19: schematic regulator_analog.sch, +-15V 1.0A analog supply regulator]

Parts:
C301, C302, C303, C304: 47u 63V
C305, C306: 100u 100V
C307, C308: 4700u 50V
C313, C314: 3.3n film
C315: 100u 16V
C316, C318: 330n film
C317: 330n
C319, C320: 100u 25V
D301, D302, D303, D304, D305, D306, D307, D308, D313, D314, D317, D318: 1N4148
D309, D310, D311, D312: SR5100
D315, D316: BZX55-C11
D319: BZX55-C5V1
Q301: IRFZ34N
Q302: IRF9Z34N
Q303, Q306: BC557; TO92
Q304, Q305: BC547; TO92
R305, R310, R321, R322: 3.3k
R306, R308: 7.5k
R307, R309: 2.2k
R311, R312: 82
R313, R314, R315, R316: 330
R317, R318: 0.56E 2W
R319, R320: 33k
R323, R326, R329, R330: 1k
R324, R327: 3.3k LTC
R325: 1.3k LTC
R328: 3.0k 1%
U301, U302: TL431; TO92
U303: TL072
VR301, VR302: 1k 3296W

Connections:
/+-15V regulator/20VAC_A: C303.2, C304.1, D309.1 (A), D310.2 (K); also elsewhere on the board
/+-15V regulator/20VAC_B: C301.2, C302.1, D311.1 (A), D312.2 (K); also elsewhere on the board
/+-15V regulator/+15VA: C316.1, C319.1, D317.1 (A), Q305.3 (E), R317.1, R324.2, R326.2, R329.2, U303.8 (V+), VR302.1; also elsewhere on the board
/+-15V regulator/+15_VGATE: C305.1, D305.2 (K), D306.2 (K), R305.2
/+-15V regulator/+20V_Rect: C307.1, D309.2 (K), D311.2 (K), Q301.2 (D); also elsewhere on the board
/+-15V regulator/-15VA: C318.2, C320.2, D318.2 (K), Q306.3 (E), R318.1, R327.1, R330.1, U303.4 (V-); also elsewhere on the board
/+-15V regulator/-15_VGATE: C306.2, D307.1 (A), D308.1 (A), R310.1
/+-15V regulator/-15_VRECT: C308.2, D310.1 (A), D312.1 (A), Q302.2 (D)
GND: C305.2, C306.1, C307.2, C308.1, C315.2, C317.2, C319.2, C320.1, D301.1 (A), D302.1 (A), D303.2 (K), D304.2 (K), D313.1 (A), D314.2 (K), D319.1 (A), Q303.1 (C), Q304.1 (C), R329.1, R330.2, U303.3 (+), VR301.2, VR301.3; also elsewhere on the board
unnamed: C301.1, D302.2 (K), D306.1 (A)
unnamed: C302.2, D303.1 (A), D307.2 (K)
unnamed: C303.1, D301.2 (K), D305.1 (A)
unnamed: C304.2, D304.1 (A), D308.2 (K)
unnamed: C313.1, Q303.3 (E), R307.1, U301.2 (A)
unnamed: C313.2, R319.2
unnamed: C314.1, Q304.3 (E), R308.1, U302.3 (K)
unnamed: C314.2, R320.2
unnamed: C315.1, R323.2, U303.5 (+)
unnamed: C316.2, R321.1, R324.1, R325.2
unnamed: C317.1, D319.2 (K), R323.1, R326.1
unnamed: C318.1, R322.1, R327.2, R328.1
unnamed: D313.2 (K), Q303.2 (B), R313.2
unnamed: D314.1 (A), Q304.2 (B), R314.2
unnamed: D315.1 (A), Q301.3 (S), R315.1, R317.2
unnamed: D315.2 (K), Q301.1 (G), Q305.1 (C), R311.1
unnamed: D316.1 (A), Q302.1 (G), Q306.1 (C), R312.1
unnamed: D316.2 (K), Q302.3 (S), R316.1, R318.2
unnamed: D317.2 (K), Q305.2 (B), R315.2
unnamed: D318.1 (A), Q306.2 (B), R316.2
unnamed: R305.1, R306.1, R311.2, U301.3 (K)
unnamed: R306.2, R307.2, U301.1 (Ref)
unnamed: R308.2, R309.2, U302.1 (Ref)
unnamed: R309.1, R310.2, R312.2, U302.2 (A)
unnamed: R313.1, U303.7
unnamed: R314.1, U303.1
unnamed: R319.1, R321.2, U303.6 (-)
unnamed: R320.1, R322.2, U303.2 (-)
unnamed: R325.1, VR301.1
unnamed: R328.2, VR302.2, VR302.3

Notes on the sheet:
On heatsink

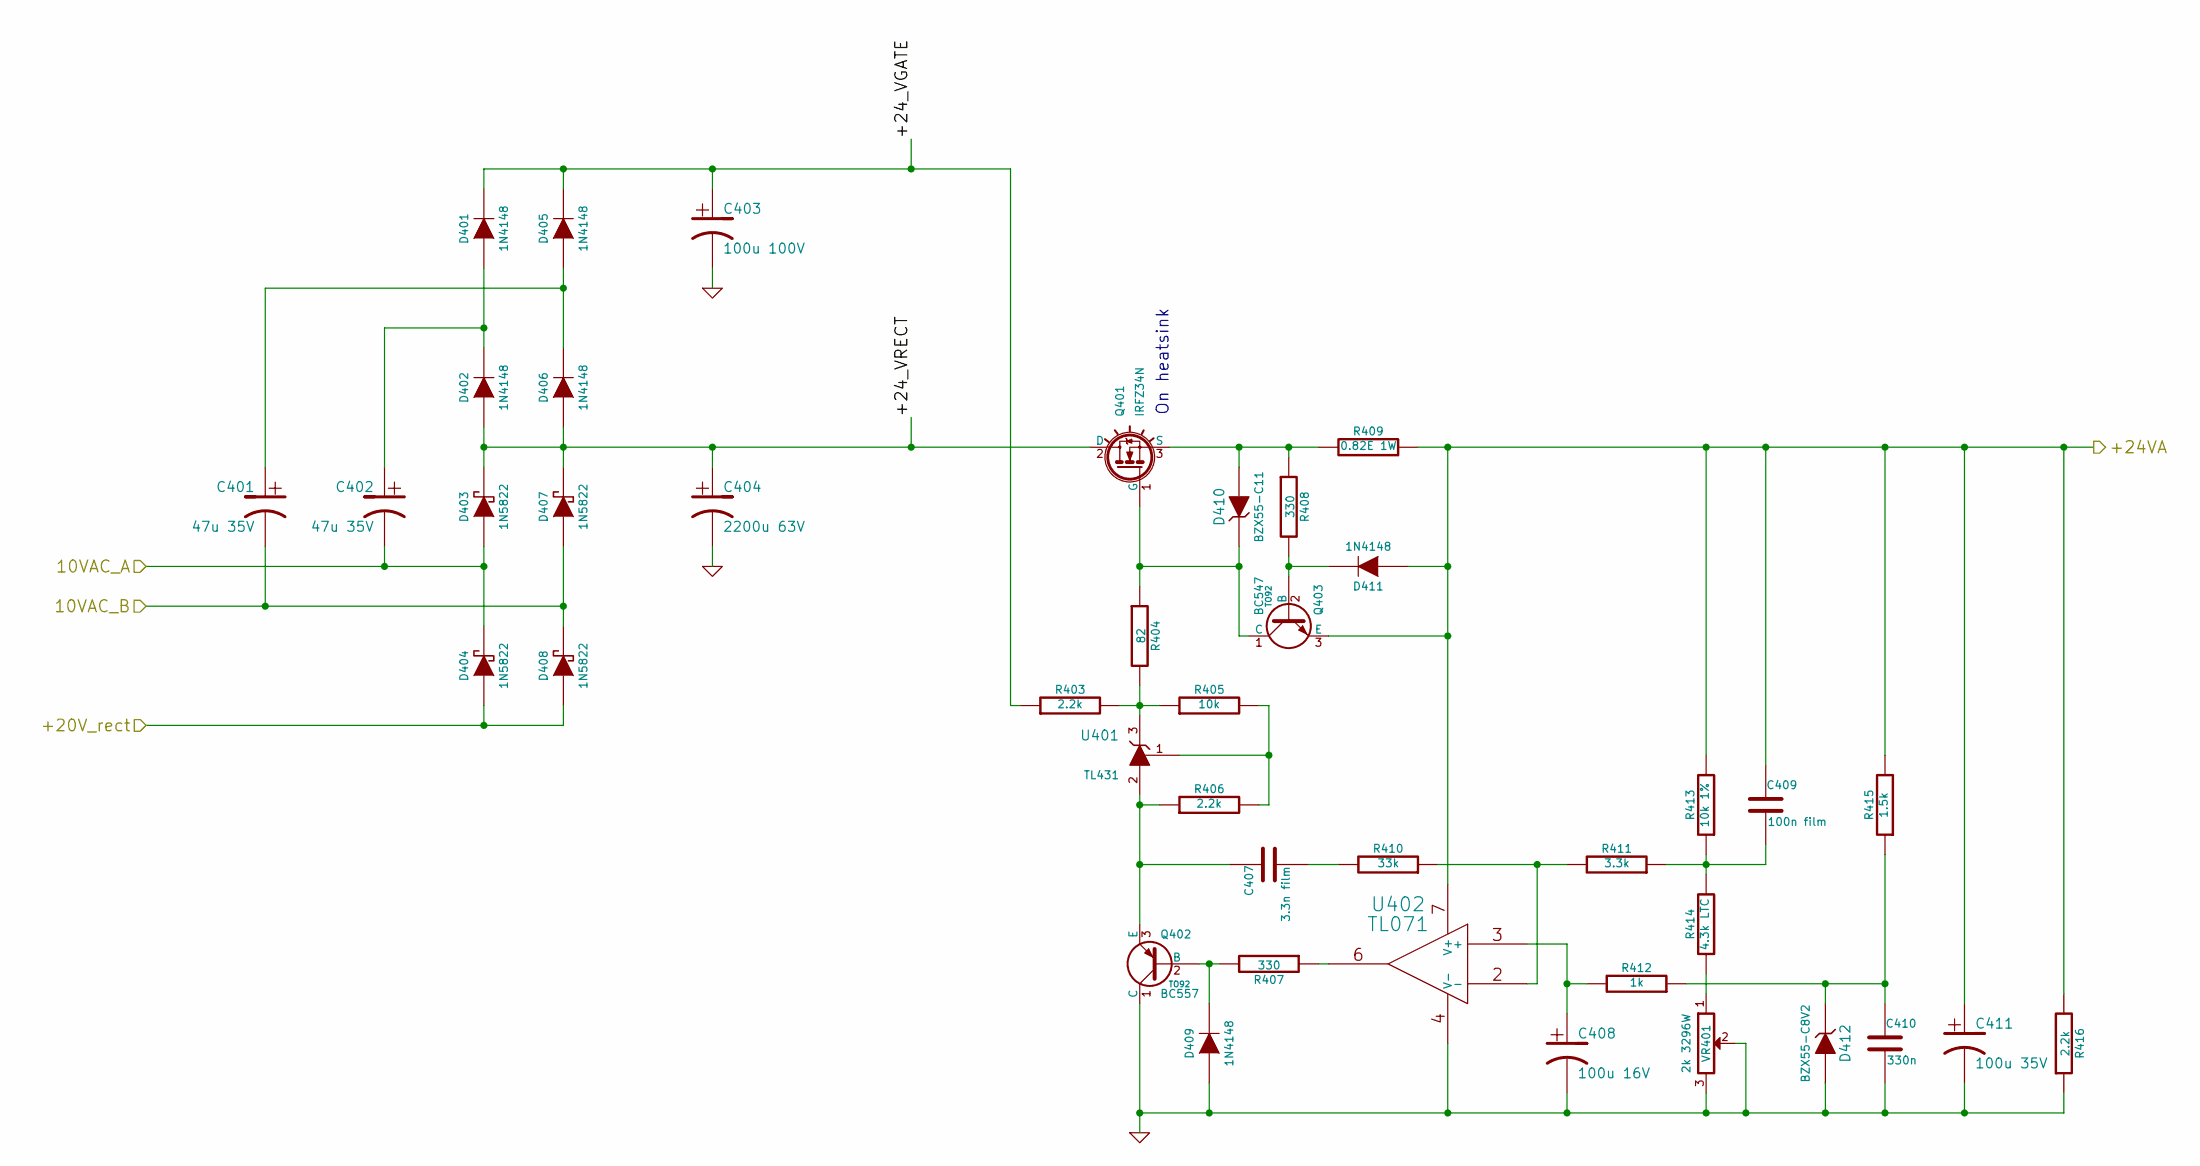
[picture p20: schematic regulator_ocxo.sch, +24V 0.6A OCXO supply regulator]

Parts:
C401, C402: 47u 35V
C403: 100u 100V
C404: 2200u 63V
C407: 3.3n film
C408: 100u 16V
C409: 100n film
C410: 330n
C411: 100u 35V
D401, D402, D405, D406, D409, D411: 1N4148
D403, D404, D407, D408: 1N5822
D410: BZX55-C11
D412: BZX55-C8V2
Q401: IRFZ34N
Q402: BC557; TO92
Q403: BC547; TO92
R403, R406, R416: 2.2k
R404: 82
R405: 10k
R407, R408: 330
R409: 0.82E 1W
R410: 33k
R411: 3.3k
R412: 1k
R413: 10k 1%
R414: 4.3k LTC
R415: 1.5k
U401: TL431; TO92
U402: TL071
VR401: 2k 3296W

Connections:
/+-15V regulator/+20V_Rect: D404.1 (A), D408.1 (A); also elsewhere on the board
/OCXO regulator/10VAC_A: C402.2, D403.1 (A), D404.2 (K); also elsewhere on the board
/OCXO regulator/10VAC_B: C401.2, D407.1 (A), D408.2 (K); also elsewhere on the board
/OCXO regulator/+24VA: C409.1, C411.1, D411.1 (A), Q403.3 (E), R409.1, R413.2, R415.2, R416.2, U402.7 (V+); also elsewhere on the board
/OCXO regulator/+24_VGATE: C403.1, D401.2 (K), D405.2 (K), R403.1
/OCXO regulator/+24_VRECT: C404.1, D402.1 (A), D403.2 (K), D406.1 (A), D407.2 (K), Q401.2 (D)
GND: C403.2, C404.2, C408.2, C410.2, C411.2, D409.1 (A), D412.1 (A), Q402.1 (C), R416.1, U402.4 (V-), VR401.2, VR401.3; also elsewhere on the board
unnamed: C401.1, D405.1 (A), D406.2 (K)
unnamed: C402.1, D401.1 (A), D402.2 (K)
unnamed: C407.1, Q402.3 (E), R406.1, U401.2 (A)
unnamed: C407.2, R410.2
unnamed: C408.1, R412.2, U402.3 (+)
unnamed: C409.2, R411.1, R413.1, R414.2
unnamed: C410.1, D412.2 (K), R412.1, R415.1
unnamed: D409.2 (K), Q402.2 (B), R407.2
unnamed: D410.1 (A), Q401.3 (S), R408.1, R409.2
unnamed: D410.2 (K), Q401.1 (G), Q403.1 (C), R404.1
unnamed: D411.2 (K), Q403.2 (B), R408.2
unnamed: R403.2, R404.2, R405.1, U401.3 (K)
unnamed: R405.2, R406.2, U401.1 (Ref)
unnamed: R407.1, U402.6
unnamed: R410.1, R411.2, U402.2 (-)
unnamed: R414.1, VR401.1

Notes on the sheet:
On heatsink

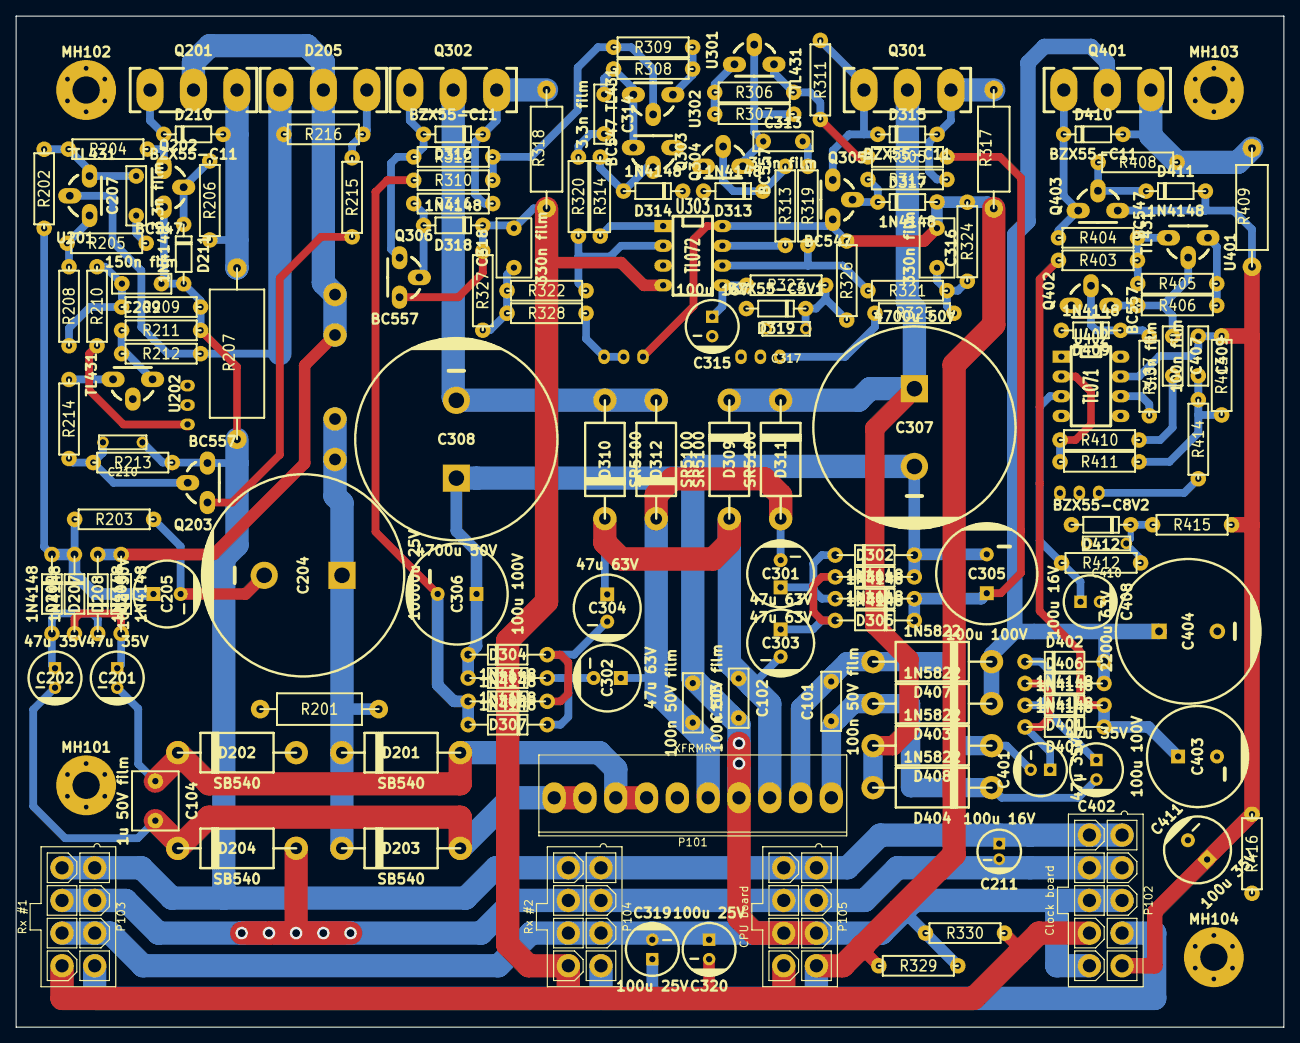
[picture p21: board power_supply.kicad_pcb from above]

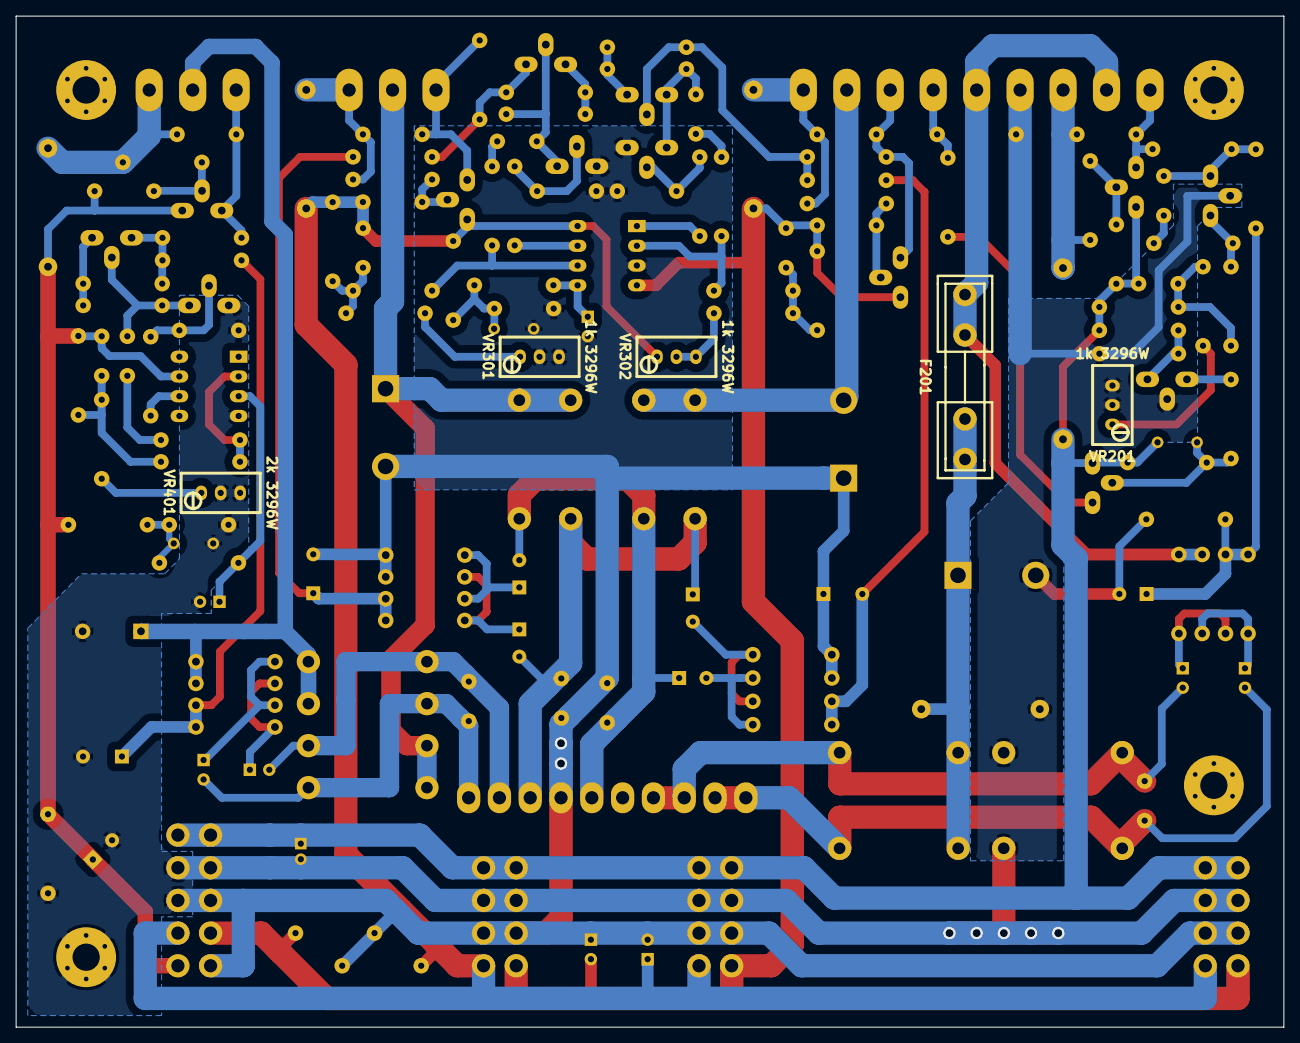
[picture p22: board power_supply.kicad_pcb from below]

Board: 2 copper layers, 163.0 x 130.0 mm, 168 parts (5 on the bottom side), 81 nets.

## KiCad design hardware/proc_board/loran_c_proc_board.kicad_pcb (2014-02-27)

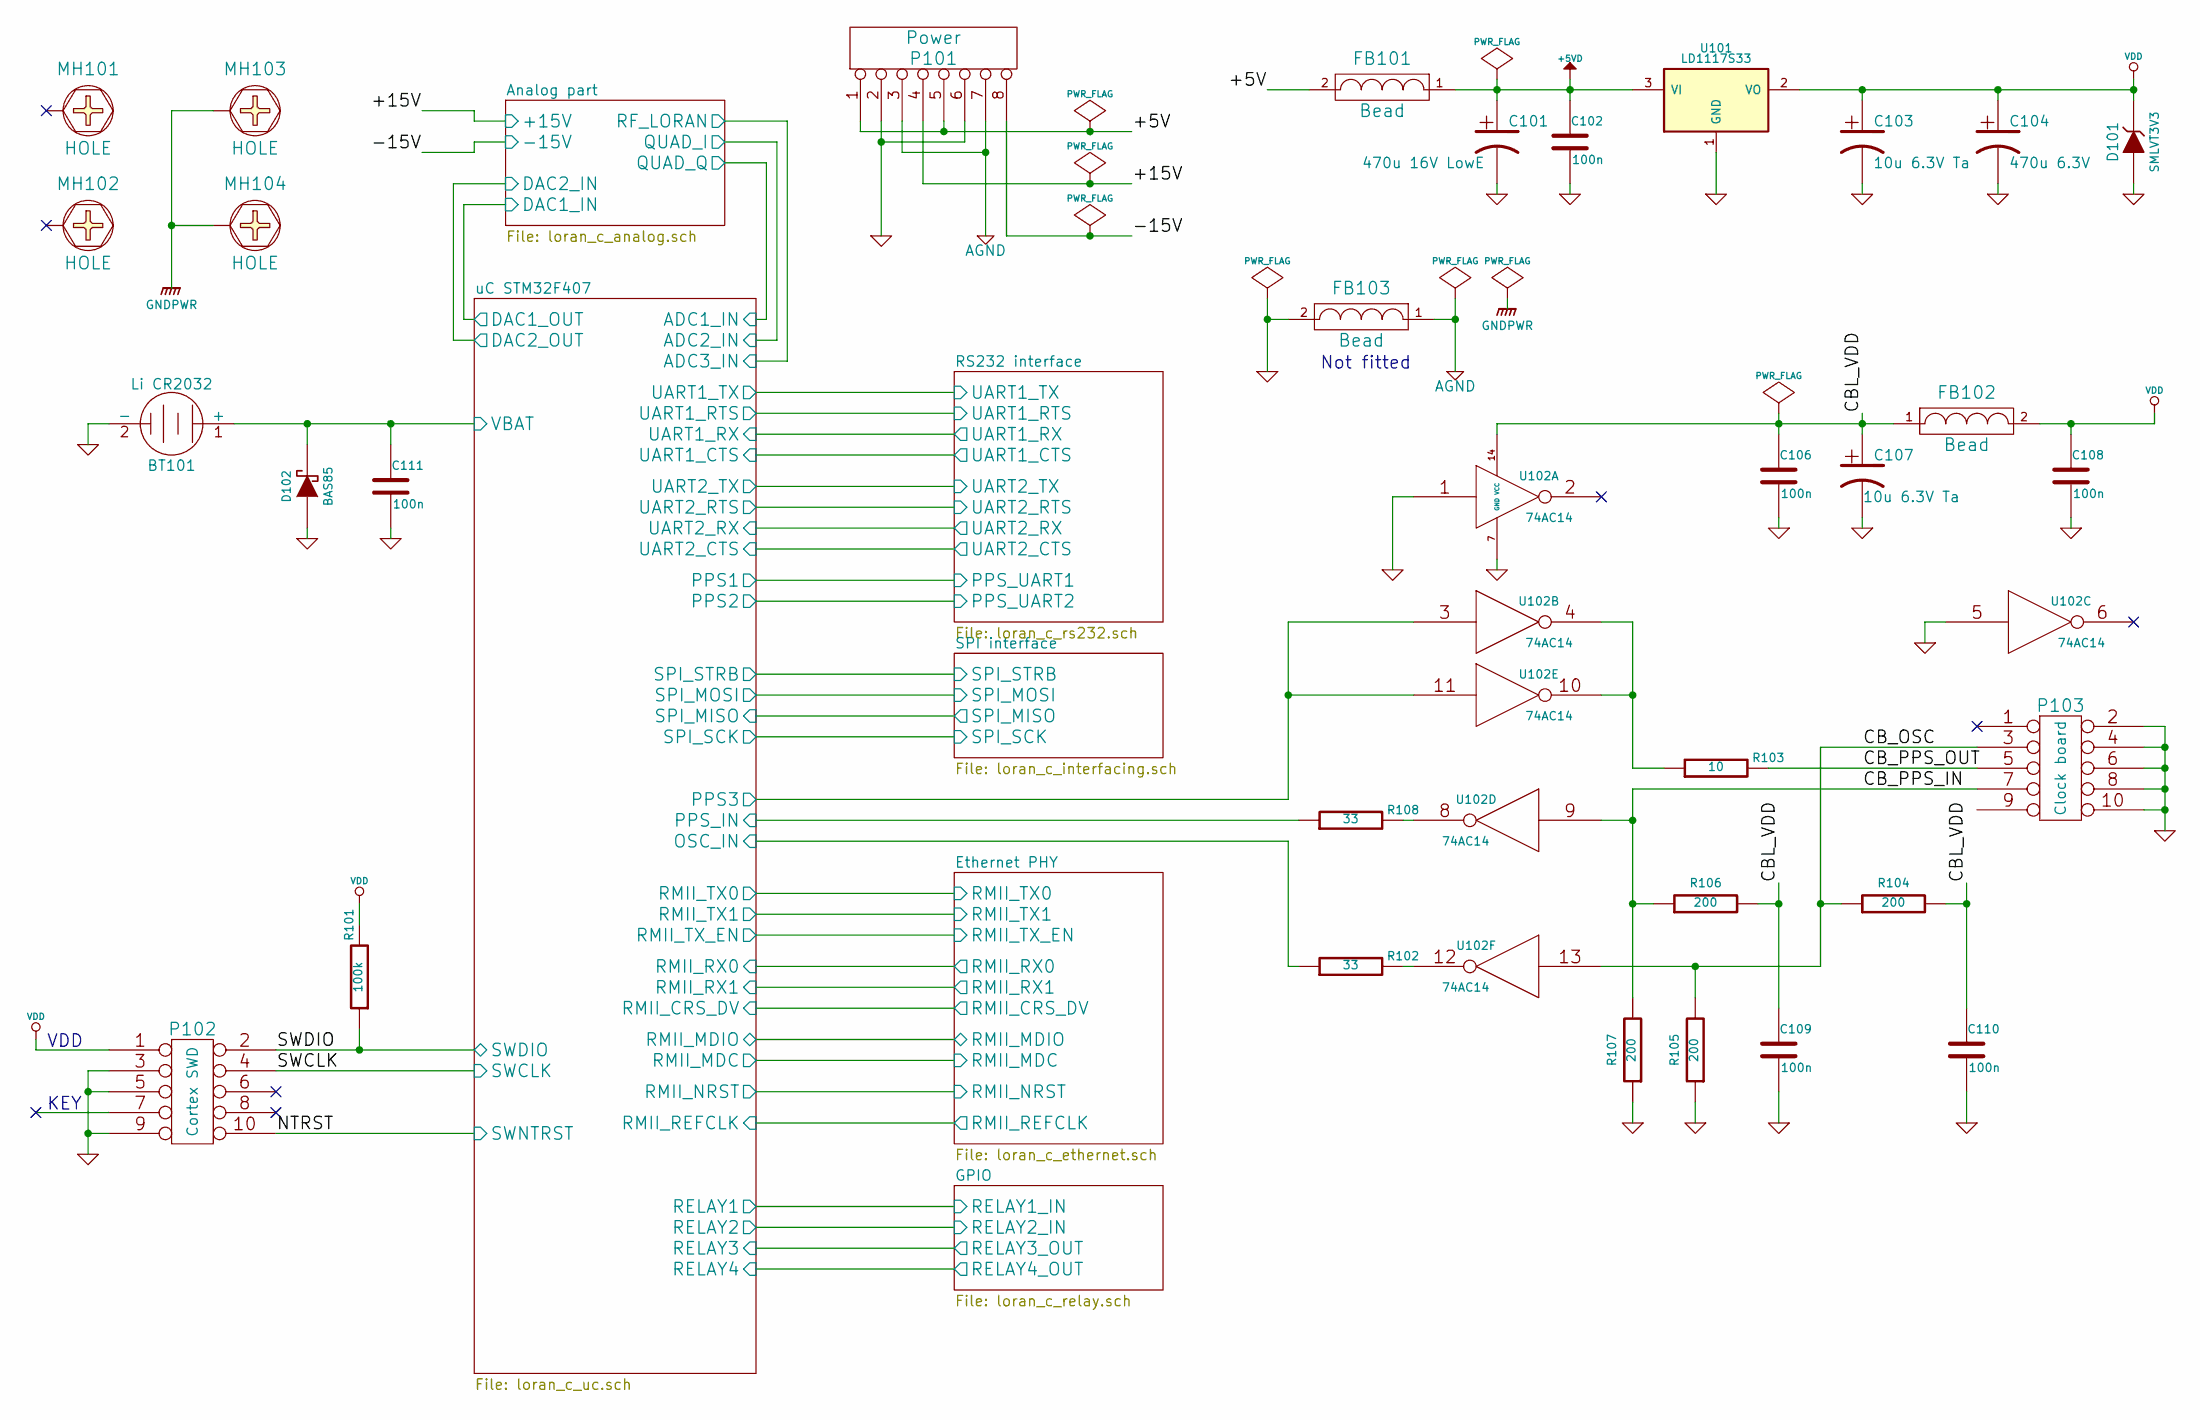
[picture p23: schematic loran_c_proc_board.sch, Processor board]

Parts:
BT101: Li CR2032; bh840
C101: 470u 16V LowE; CP_10x12.5mm
C102, C106, C108, C109, C110: 100n; c_1206
C103, C107: 10u 6.3V Ta; c_tant_B
C104: 470u 6.3V; CP_6.3x11mm
C111: 100n; c_0805
D101: SMLVT3V3; do214aa
D102: BAS85; sod80c
FB101: Bead; RC07
FB102: Bead; rc07_vert
FB103: Bead; SM1812E
MH101, MH102, MH103, MH104: HOLE; Hole_3-5mm
P101: Power; minifit-8
P102: Cortex SWD; vasch_strip_5x2
P103: Clock board; vasch_strip_5x2
R101: 100k; r_1206
R102, R108: 33; r_1206
R103: 10; r_1206
R104, R105, R106, R107: 200; r_1206
U101: LD1117S33; TO-220_Neutral123_Vertical
U102: 74AC14; so-14

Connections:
+5VD: C101.1, C102.1, FB101.1, U101.3 (VI); also elsewhere on the board
/+5V: FB101.2, P101.1, P101.5
/Analog part/+15V: P101.4; also elsewhere on the board
/Analog part/-15V: P101.8; also elsewhere on the board
/CBL_VDD: C106.1, C107.1, C109.1, C110.1, FB102.1, R104.2, R106.2, U102.14 (VCC)
/CB_OSC: P103.3, R104.1, R105.2, U102.13
/CB_PPS_IN: P103.7, R106.1, R107.2, U102.9
/CB_PPS_OUT: P103.5, R103.2
/uC STM32F407/OSC_IN: R102.1; also elsewhere on the board
/uC STM32F407/PPS3: U102.3, U102.11; also elsewhere on the board
/uC STM32F407/PPS_IN: R108.1; also elsewhere on the board
/uC STM32F407/SWCLK: P102.4; also elsewhere on the board
/uC STM32F407/SWDIO: P102.2, R101.1; also elsewhere on the board
/uC STM32F407/SWNTRST: P102.10; also elsewhere on the board
/uC STM32F407/VBAT: BT101.1 (+), C111.1, D102.2 (K); also elsewhere on the board
AGND: FB103.1, P101.3, P101.7; also elsewhere on the board
GND: BT101.2 (-), C101.2, C102.2, C103.2, C104.2, C106.2, C107.2, C108.2, C109.2, C110.2, C111.2, D101.1 (A), D102.1 (A), FB103.2, P101.2, P101.6, P102.3, P102.5, P102.9, P103.2, P103.4, P103.6, P103.8, P103.10, R105.1, R107.1, U101.1 (GND), U102.1, U102.5, U102.7 (GND); also elsewhere on the board
GNDPWR: MH103.1, MH104.1; also elsewhere on the board
unnamed: R102.2, U102.12
unnamed: R103.1, U102.4, U102.10
unnamed: R108.2, U102.8
VDD: C103.1, C104.1, C108.1, D101.2 (K), FB102.2, P102.1, R101.2, U101.2 (VO); also elsewhere on the board

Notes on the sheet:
KEY
VDD
Not fitted

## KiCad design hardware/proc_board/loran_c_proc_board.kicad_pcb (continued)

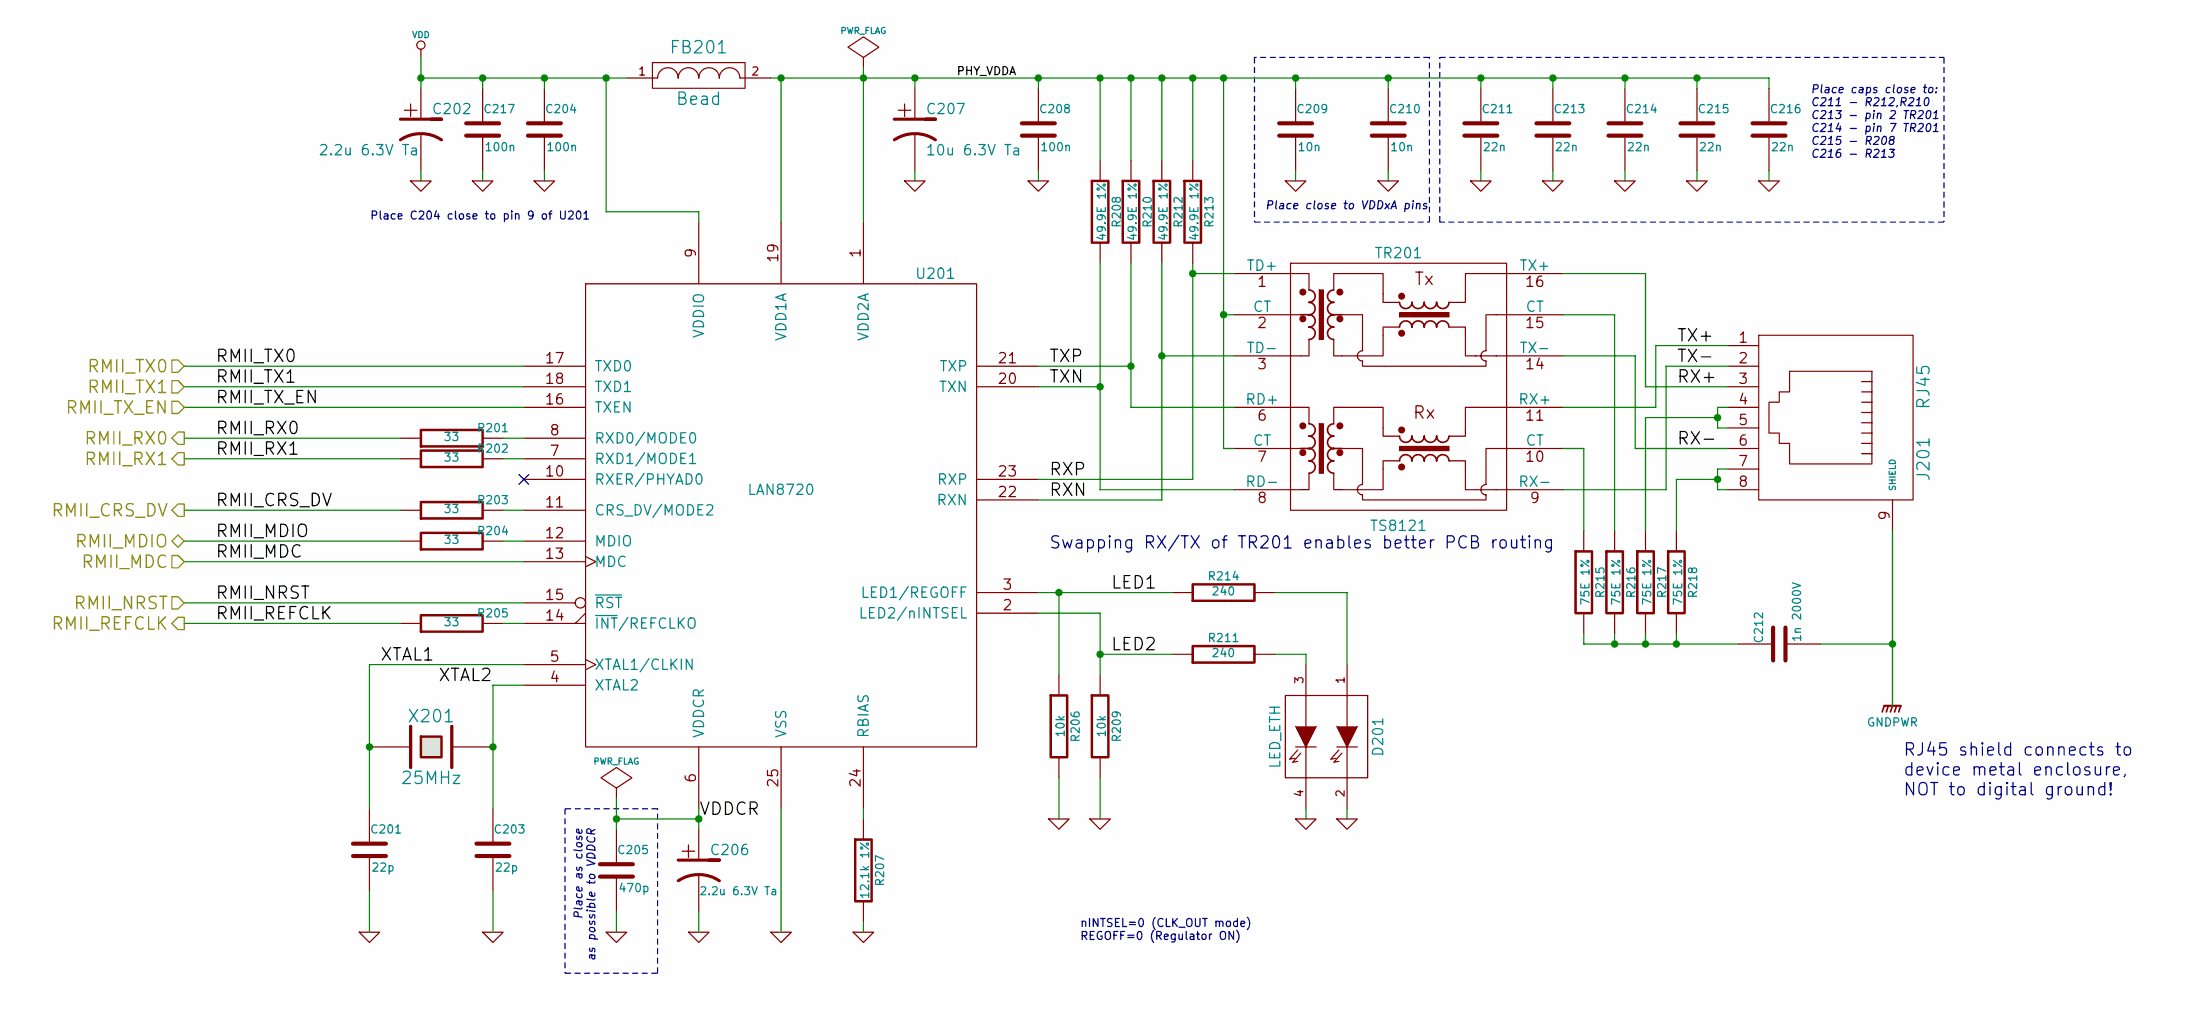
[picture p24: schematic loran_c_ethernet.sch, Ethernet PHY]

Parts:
C201, C203: 22p; r_0805
C202, C206: 2.2u 6.3V Ta; c_tant_A
C204, C208, C217: 100n; c_1206
C205: 470p; r_0805
C207: 10u 6.3V Ta; c_tant_B
C209, C210: 10n; c_1206
C211, C213, C214, C215, C216: 22n; c_1206
C212: 1n 2000V; cnp_6mm_disc
D201: LED_ETH
FB201: Bead; RC07
J201: RJ45; RJ45_8
R201, R202: 33; r_1206
R203, R204, R205: 33; r_0805
R206, R209: 10k; r_1206
R207: 12.1k 1%; r_1206
R208, R210, R212, R213: 49.9E 1%; r_1206
R211, R214: 240; r_1206
R215, R216, R217, R218: 75E 1%; r_1206
TR201: TS8121
U201: LAN8720; qfn-24
X201: 25MHz; crystal_hc-49u

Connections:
/Ethernet PHY/LED1: R206.1, R214.1, U201.3 (LED1/REGOFF)
/Ethernet PHY/LED2: R209.1, R211.1, U201.2 (LED2/nINTSEL)
/Ethernet PHY/PHY_VDDA: C207.1, C208.1, C209.1, C210.1, C211.1, C213.1, C214.1, C215.1, C216.1, FB201.2, R208.1, R210.1, R212.1, R213.1, TR201.2 (CT), TR201.7 (CT), U201.1 (VDD2A), U201.19 (VDD1A)
/Ethernet PHY/RMII_CRS_DV: R203.1; also elsewhere on the board
/Ethernet PHY/RMII_MDC: U201.13 (MDC); also elsewhere on the board
/Ethernet PHY/RMII_MDIO: R204.1; also elsewhere on the board
/Ethernet PHY/RMII_NRST: U201.15 (~RST); also elsewhere on the board
/Ethernet PHY/RMII_REFCLK: R205.1; also elsewhere on the board
/Ethernet PHY/RMII_RX0: R201.1; also elsewhere on the board
/Ethernet PHY/RMII_RX1: R202.1; also elsewhere on the board
/Ethernet PHY/RMII_TX0: U201.17 (TXD0); also elsewhere on the board
/Ethernet PHY/RMII_TX1: U201.18 (TXD1); also elsewhere on the board
/Ethernet PHY/RMII_TX_EN: U201.16 (TXEN); also elsewhere on the board
/Ethernet PHY/RX+: J201.3, TR201.16 (TX+)
/Ethernet PHY/RX-: J201.6, TR201.14 (TX-)
/Ethernet PHY/RXN: R212.2, TR201.3 (TD-), U201.22 (RXN)
/Ethernet PHY/RXP: R213.2, TR201.1 (TD+), U201.23 (RXP)
/Ethernet PHY/TX+: J201.1, TR201.11 (RX+)
/Ethernet PHY/TX-: J201.2, TR201.9 (RX-)
/Ethernet PHY/TXN: R208.2, TR201.8 (RD-), U201.20 (TXN)
/Ethernet PHY/TXP: R210.2, TR201.6 (RD+), U201.21 (TXP)
/Ethernet PHY/VDDCR: C205.1, C206.1, U201.6 (VDDCR)
/Ethernet PHY/XTAL1: C201.1, U201.5 (XTAL1/CLKIN), X201.1
/Ethernet PHY/XTAL2: C203.1, U201.4 (XTAL2), X201.2
GND: C201.2, C202.2, C203.2, C204.2, C205.2, C206.2, C207.2, C208.2, C209.2, C210.2, C211.2, C213.2, C214.2, C215.2, C216.2, C217.2, D201.2 (K1), D201.4 (K2), R206.2, R207.2, R209.2, U201.25 (VSS); also elsewhere on the board
GNDPWR: C212.2, J201.9 (SHIELD); also elsewhere on the board
unnamed: C212.1, R215.2, R216.2, R217.2, R218.2
unnamed: D201.1 (A1), R214.2
unnamed: D201.3 (A2), R211.2
unnamed: J201.4, J201.5, R217.1
unnamed: J201.7, J201.8, R218.1
unnamed: R201.2, U201.8 (RXD0/MODE0)
unnamed: R202.2, U201.7 (RXD1/MODE1)
unnamed: R203.2, U201.11 (CRS_DV/MODE2)
unnamed: R204.2, U201.12 (MDIO)
unnamed: R205.2, U201.14 (~INT~/REFCLKO)
unnamed: R207.1, U201.24 (RBIAS)
unnamed: R215.1, TR201.10 (CT)
unnamed: R216.1, TR201.15 (CT)
VDD: C202.1, C204.1, C217.1, FB201.1, U201.9 (VDDIO); also elsewhere on the board

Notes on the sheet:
nINTSEL=0 (CLK_OUT mode) REGOFF=0 (Regulator ON)
Place caps close to: C211 - R212,R210 C213 - pin 2 TR201 C214 - pin 7 TR201 C215 - R208 C216 - R213
Place as close as possible to VDDCR
Place close to VDDxA pins
RJ45 shield connects to device metal enclosure, NOT to digital ground!
Swapping RX/TX of TR201 enables better PCB routing
Place C204 close to pin 9 of U201

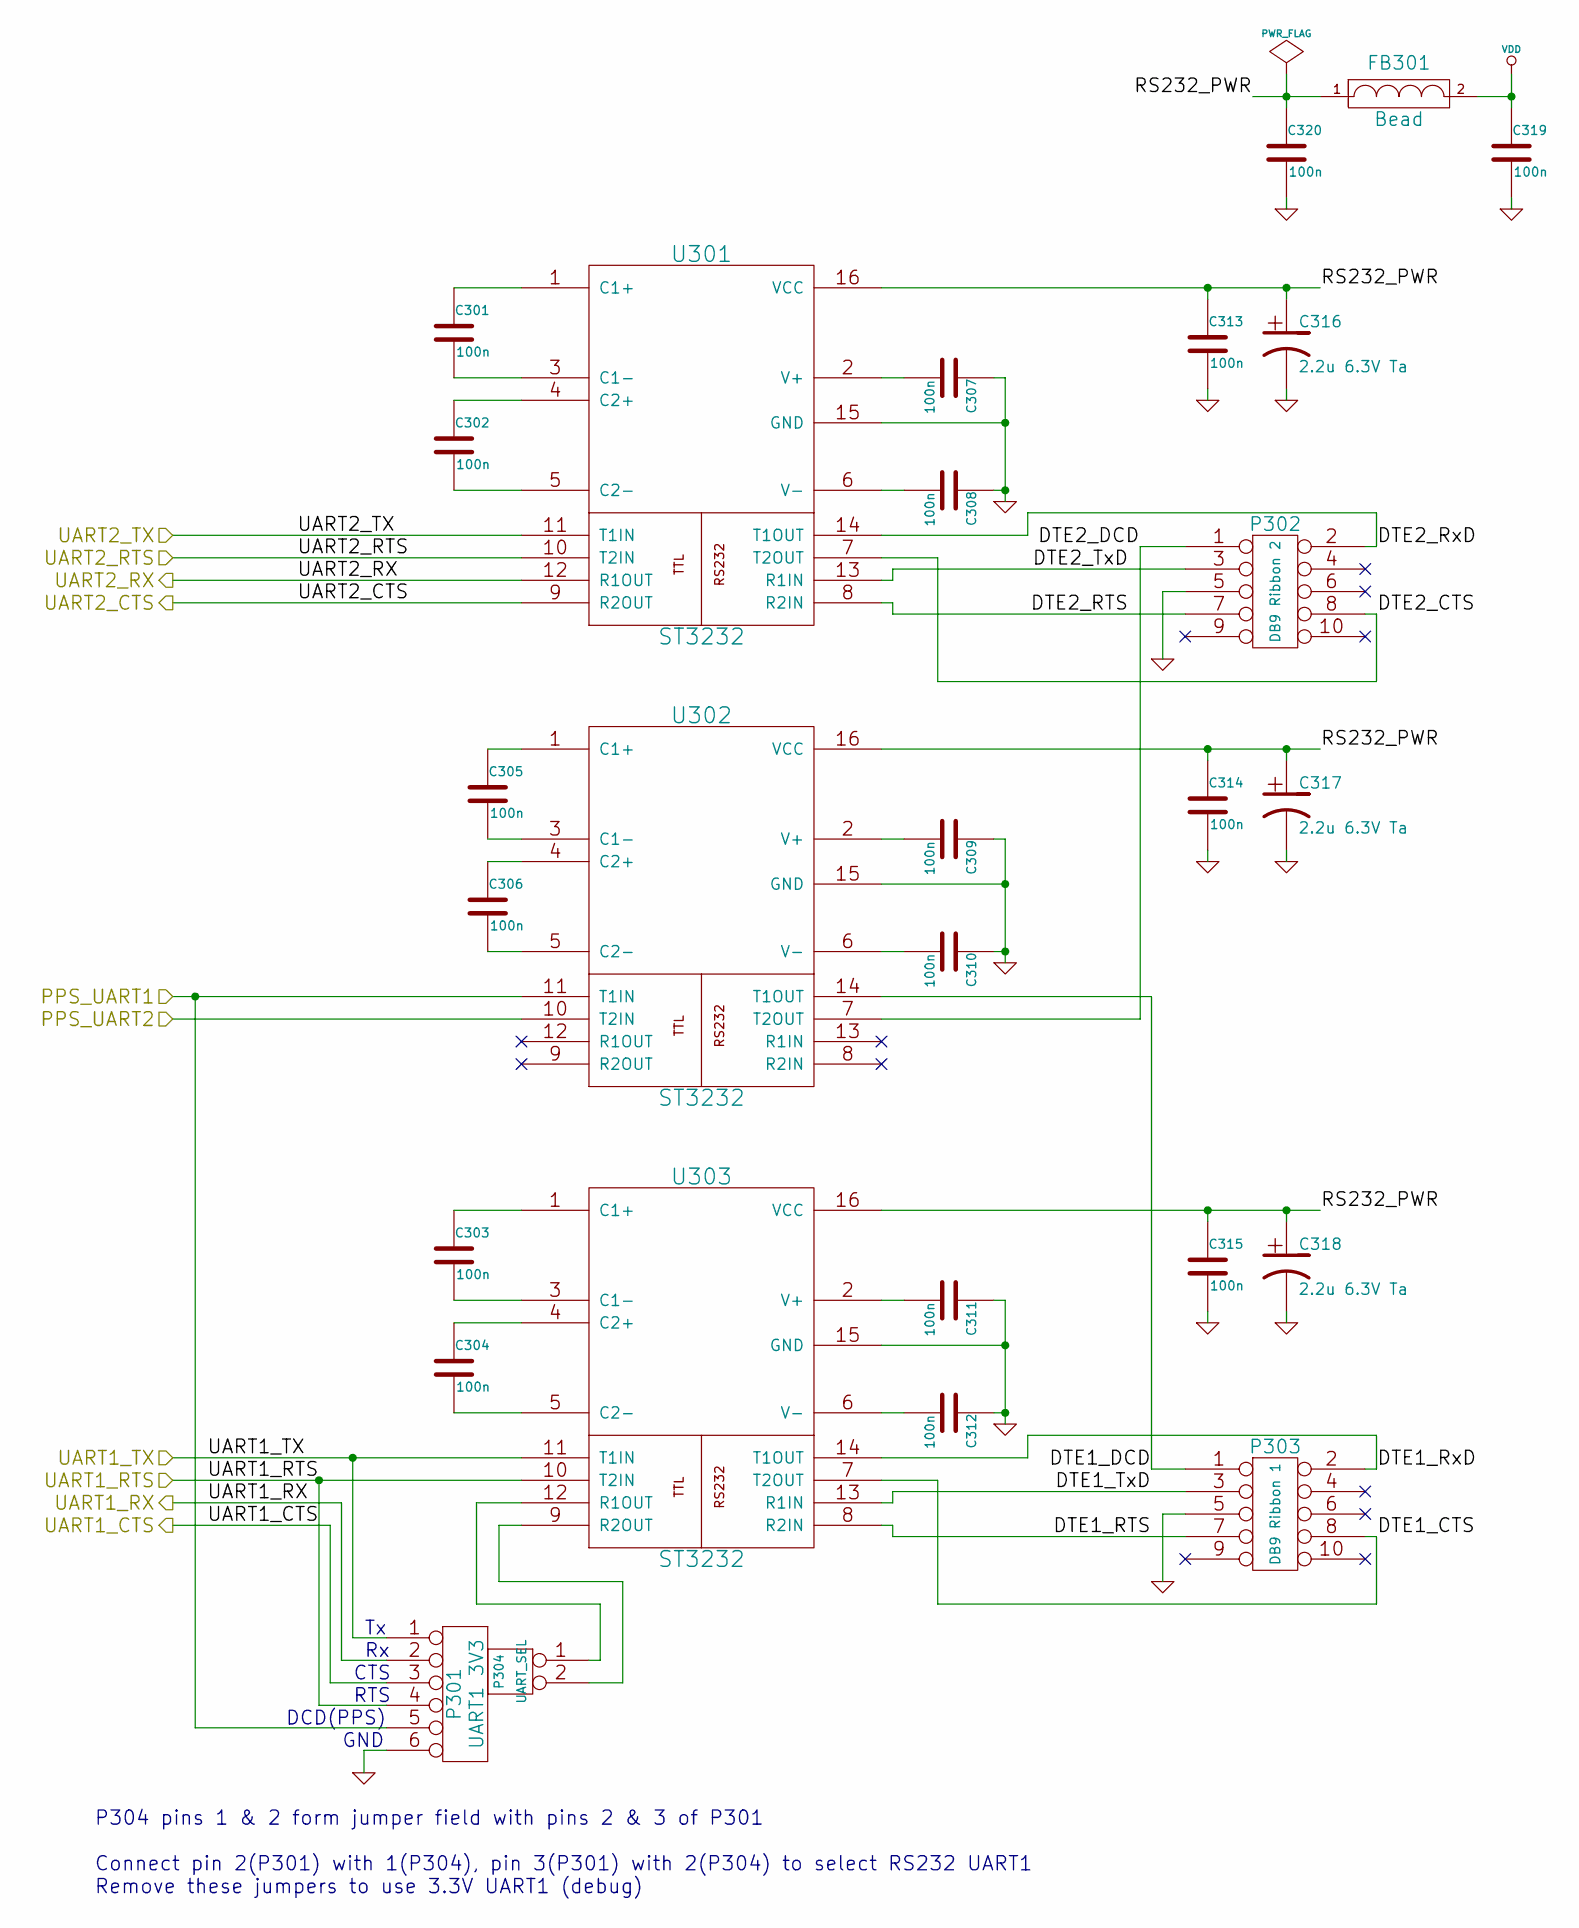
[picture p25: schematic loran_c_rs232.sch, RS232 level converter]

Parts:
C301, C302, C303, C304, C305, C306, C307, C308, C309, C310, C311, C312, C313, C314, C315, C319, C320: 100n; c_1206
C316, C317, C318: 2.2u 6.3V Ta; c_tant_A
FB301: Bead; RC07
P301: UART1 3V3; Pin_Header_Straight_1x06
P302: DB9 Ribbon 2; vasch_strip_5x2
P303: DB9 Ribbon 1; vasch_strip_5x2
P304: UART_SEL; Pin_Header_Straight_1x02
U301, U302, U303: ST3232; so-16

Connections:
/RS232 interface/DTE1_CTS: P303.8, U303.7 (T2OUT)
/RS232 interface/DTE1_DCD: P303.1, U302.14 (T1OUT)
/RS232 interface/DTE1_RTS: P303.7, U303.8 (R2IN)
/RS232 interface/DTE1_RxD: P303.2, U303.14 (T1OUT)
/RS232 interface/DTE1_TxD: P303.3, U303.13 (R1IN)
/RS232 interface/DTE2_CTS: P302.8, U301.7 (T2OUT)
/RS232 interface/DTE2_DCD: P302.1, U302.7 (T2OUT)
/RS232 interface/DTE2_RTS: P302.7, U301.8 (R2IN)
/RS232 interface/DTE2_RxD: P302.2, U301.14 (T1OUT)
/RS232 interface/DTE2_TxD: P302.3, U301.13 (R1IN)
/RS232 interface/RS232_PWR: C313.1, C314.1, C315.1, C316.1, C317.1, C318.1, C320.1, FB301.1, U301.16 (VCC), U302.16 (VCC), U303.16 (VCC)
/RS232 interface/UART1_CTS: P301.3; also elsewhere on the board
/RS232 interface/UART1_RTS: P301.4, U303.10 (T2IN); also elsewhere on the board
/RS232 interface/UART1_RX: P301.2; also elsewhere on the board
/RS232 interface/UART1_TX: P301.1, U303.11 (T1IN); also elsewhere on the board
/RS232 interface/UART2_CTS: U301.9 (R2OUT); also elsewhere on the board
/RS232 interface/UART2_RTS: U301.10 (T2IN); also elsewhere on the board
/RS232 interface/UART2_RX: U301.12 (R1OUT); also elsewhere on the board
/RS232 interface/UART2_TX: U301.11 (T1IN); also elsewhere on the board
/uC STM32F407/PPS1: P301.5, U302.11 (T1IN); also elsewhere on the board
/uC STM32F407/PPS2: U302.10 (T2IN); also elsewhere on the board
GND: C307.1, C308.1, C309.1, C310.1, C311.1, C312.1, C313.2, C314.2, C315.2, C316.2, C317.2, C318.2, C319.2, C320.2, P301.6, P302.5, P303.5, U301.15 (GND), U302.15 (GND), U303.15 (GND); also elsewhere on the board
unnamed: C301.1, U301.1 (C1+)
unnamed: C301.2, U301.3 (C1-)
unnamed: C302.1, U301.4 (C2+)
unnamed: C302.2, U301.5 (C2-)
unnamed: C303.1, U303.1 (C1+)
unnamed: C303.2, U303.3 (C1-)
unnamed: C304.1, U303.4 (C2+)
unnamed: C304.2, U303.5 (C2-)
unnamed: C305.1, U302.1 (C1+)
unnamed: C305.2, U302.3 (C1-)
unnamed: C306.1, U302.4 (C2+)
unnamed: C306.2, U302.5 (C2-)
unnamed: C307.2, U301.2 (V+)
unnamed: C308.2, U301.6 (V-)
unnamed: C309.2, U302.2 (V+)
unnamed: C310.2, U302.6 (V-)
unnamed: C311.2, U303.2 (V+)
unnamed: C312.2, U303.6 (V-)
unnamed: P304.1, U303.12 (R1OUT)
unnamed: P304.2 (PM), U303.9 (R2OUT)
VDD: C319.1, FB301.2; also elsewhere on the board

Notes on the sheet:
RTS
CTS
DCD(PPS)
GND
P304 pins 1 & 2 form jumper field with pins 2 & 3 of P301 Connect pin 2(P301) with 1(P304), pin 3(P301) with 2(P304) to select RS232 UART1 Remove these jumpers to use 3.3V UART1 (debug)

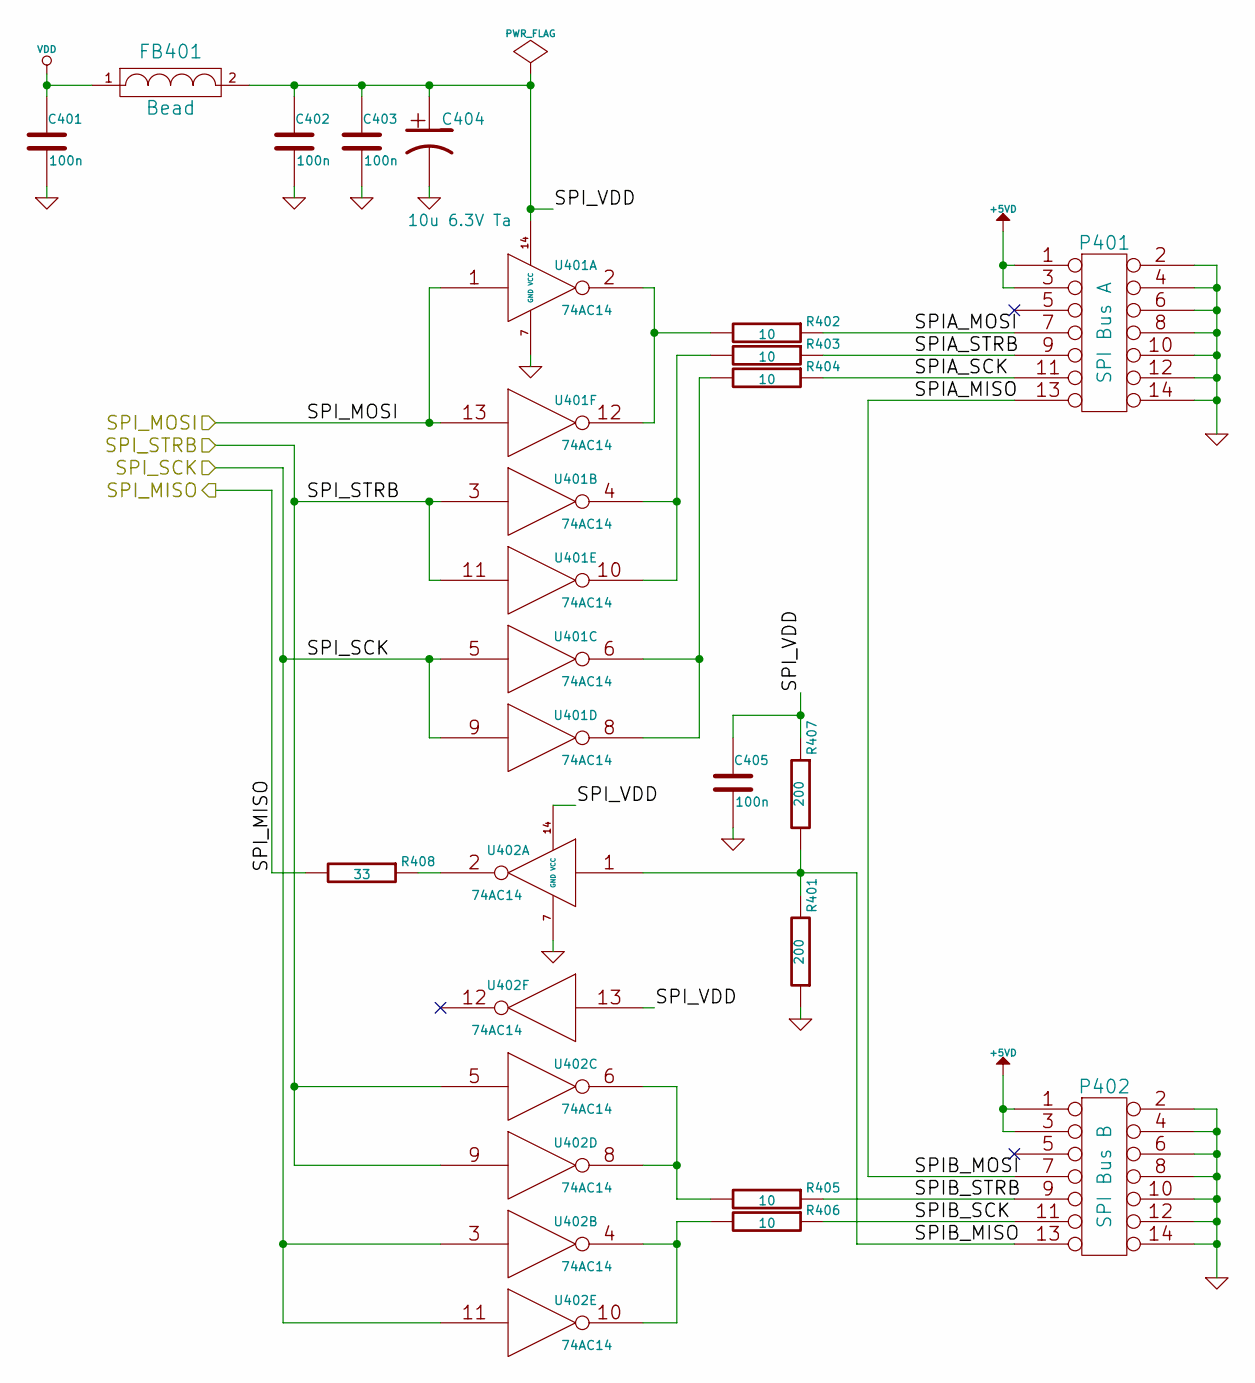
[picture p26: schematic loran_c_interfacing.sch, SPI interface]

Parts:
C401, C402, C403, C405: 100n; c_1206
C404: 10u 6.3V Ta; c_tant_B
FB401: Bead; RC07
P401: SPI Bus A; vasch_strip_7x2
P402: SPI Bus B; vasch_strip_7x2
R401, R407: 200; r_1206
R402, R403, R404, R405, R406: 10; r_1206
R408: 33; r_1206
U401, U402: 74AC14; so-14

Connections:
+5VD: P401.1, P401.3, P402.1, P402.3; also elsewhere on the board
/SPI interface/SPIA_MISO: P401.13, P402.7
/SPI interface/SPIA_MOSI: P401.7, R402.1
/SPI interface/SPIA_SCK: P401.11, R404.1
/SPI interface/SPIA_STRB: P401.9, R403.1
/SPI interface/SPIB_MISO: P402.13, R401.2, R407.2, U402.1
/SPI interface/SPIB_SCK: P402.11, R406.1
/SPI interface/SPIB_STRB: P402.9, R405.1
/SPI interface/SPI_MISO: R408.2; also elsewhere on the board
/SPI interface/SPI_MOSI: U401.1, U401.13; also elsewhere on the board
/SPI interface/SPI_SCK: U401.5, U401.9, U402.3, U402.11; also elsewhere on the board
/SPI interface/SPI_STRB: U401.3, U401.11, U402.5, U402.9; also elsewhere on the board
/SPI interface/SPI_VDD: C402.1, C403.1, C404.1, C405.1, FB401.2, R407.1, U401.14 (VCC), U402.13, U402.14 (VCC)
GND: C401.2, C402.2, C403.2, C404.2, C405.2, P401.2, P401.4, P401.6, P401.8, P401.10, P401.12, P401.14, P402.2, P402.4, P402.6, P402.8, P402.10, P402.12, P402.14, R401.1, U401.7 (GND), U402.7 (GND); also elsewhere on the board
unnamed: R402.2, U401.2, U401.12
unnamed: R403.2, U401.4, U401.10
unnamed: R404.2, U401.6, U401.8
unnamed: R405.2, U402.6, U402.8
unnamed: R406.2, U402.4, U402.10
unnamed: R408.1, U402.2
VDD: C401.1, FB401.1; also elsewhere on the board

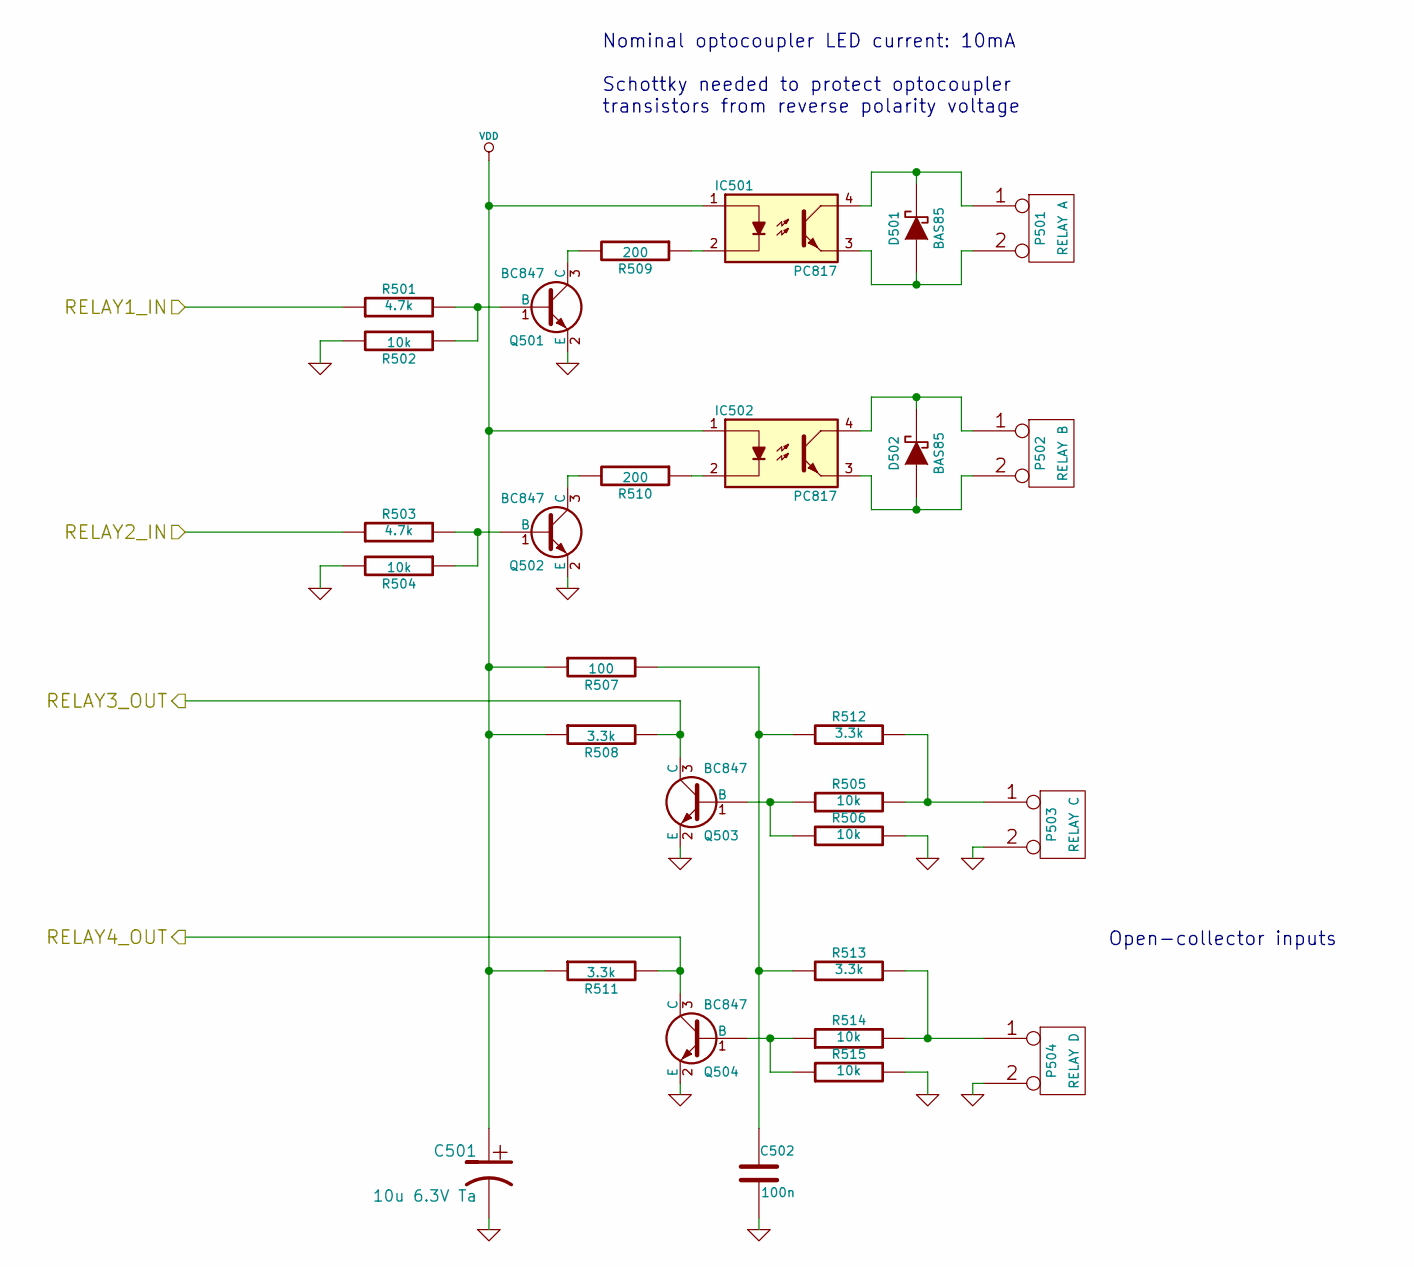
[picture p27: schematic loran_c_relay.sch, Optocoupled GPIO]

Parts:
C501: 10u 6.3V Ta; c_tant_B
C502: 100n; c_1206
D501, D502: BAS85; sod80c
IC501, IC502: PC817; dil_4-300
P501: RELAY A; kk100_22-23-2021
P502: RELAY B; kk100_22-23-2021
P503: RELAY C; kk100_22-23-2021
P504: RELAY D; kk100_22-23-2021
Q501, Q502, Q503, Q504: BC847; SOT23
R501, R503: 4.7k; r_1206
R502, R504, R505, R506, R514, R515: 10k; r_1206
R507: 100; r_1206
R508, R511, R512, R513: 3.3k; r_1206
R509, R510: 200; r_1206

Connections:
/uC STM32F407/RELAY1: R501.1; also elsewhere on the board
/uC STM32F407/RELAY2: R503.1; also elsewhere on the board
/uC STM32F407/RELAY3: Q503.3 (C), R508.2; also elsewhere on the board
/uC STM32F407/RELAY4: Q504.3 (C), R511.2; also elsewhere on the board
GND: C501.2, C502.2, P503.2 (PM), P504.2 (PM), Q501.2 (E), Q502.2 (E), Q503.2 (E), Q504.2 (E), R502.2, R504.2, R506.2, R515.2; also elsewhere on the board
unnamed: C502.1, R507.2, R512.2, R513.2
unnamed: D501.1 (A), IC501.3, P501.2 (PM)
unnamed: D501.2 (K), IC501.4, P501.1
unnamed: D502.1 (A), IC502.3, P502.2 (PM)
unnamed: D502.2 (K), IC502.4, P502.1
unnamed: IC501.2, R509.1
unnamed: IC502.2, R510.1
unnamed: P503.1, R505.2, R512.1
unnamed: P504.1, R513.1, R514.2
unnamed: Q501.1 (B), R501.2, R502.1
unnamed: Q501.3 (C), R509.2
unnamed: Q502.1 (B), R503.2, R504.1
unnamed: Q502.3 (C), R510.2
unnamed: Q503.1 (B), R505.1, R506.1
unnamed: Q504.1 (B), R514.1, R515.1
VDD: C501.1, IC501.1, IC502.1, R507.1, R508.1, R511.1; also elsewhere on the board

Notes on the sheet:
Nominal optocoupler LED current: 10mA Schottky needed to protect optocoupler transistors from reverse polarity voltage
Open-collector inputs

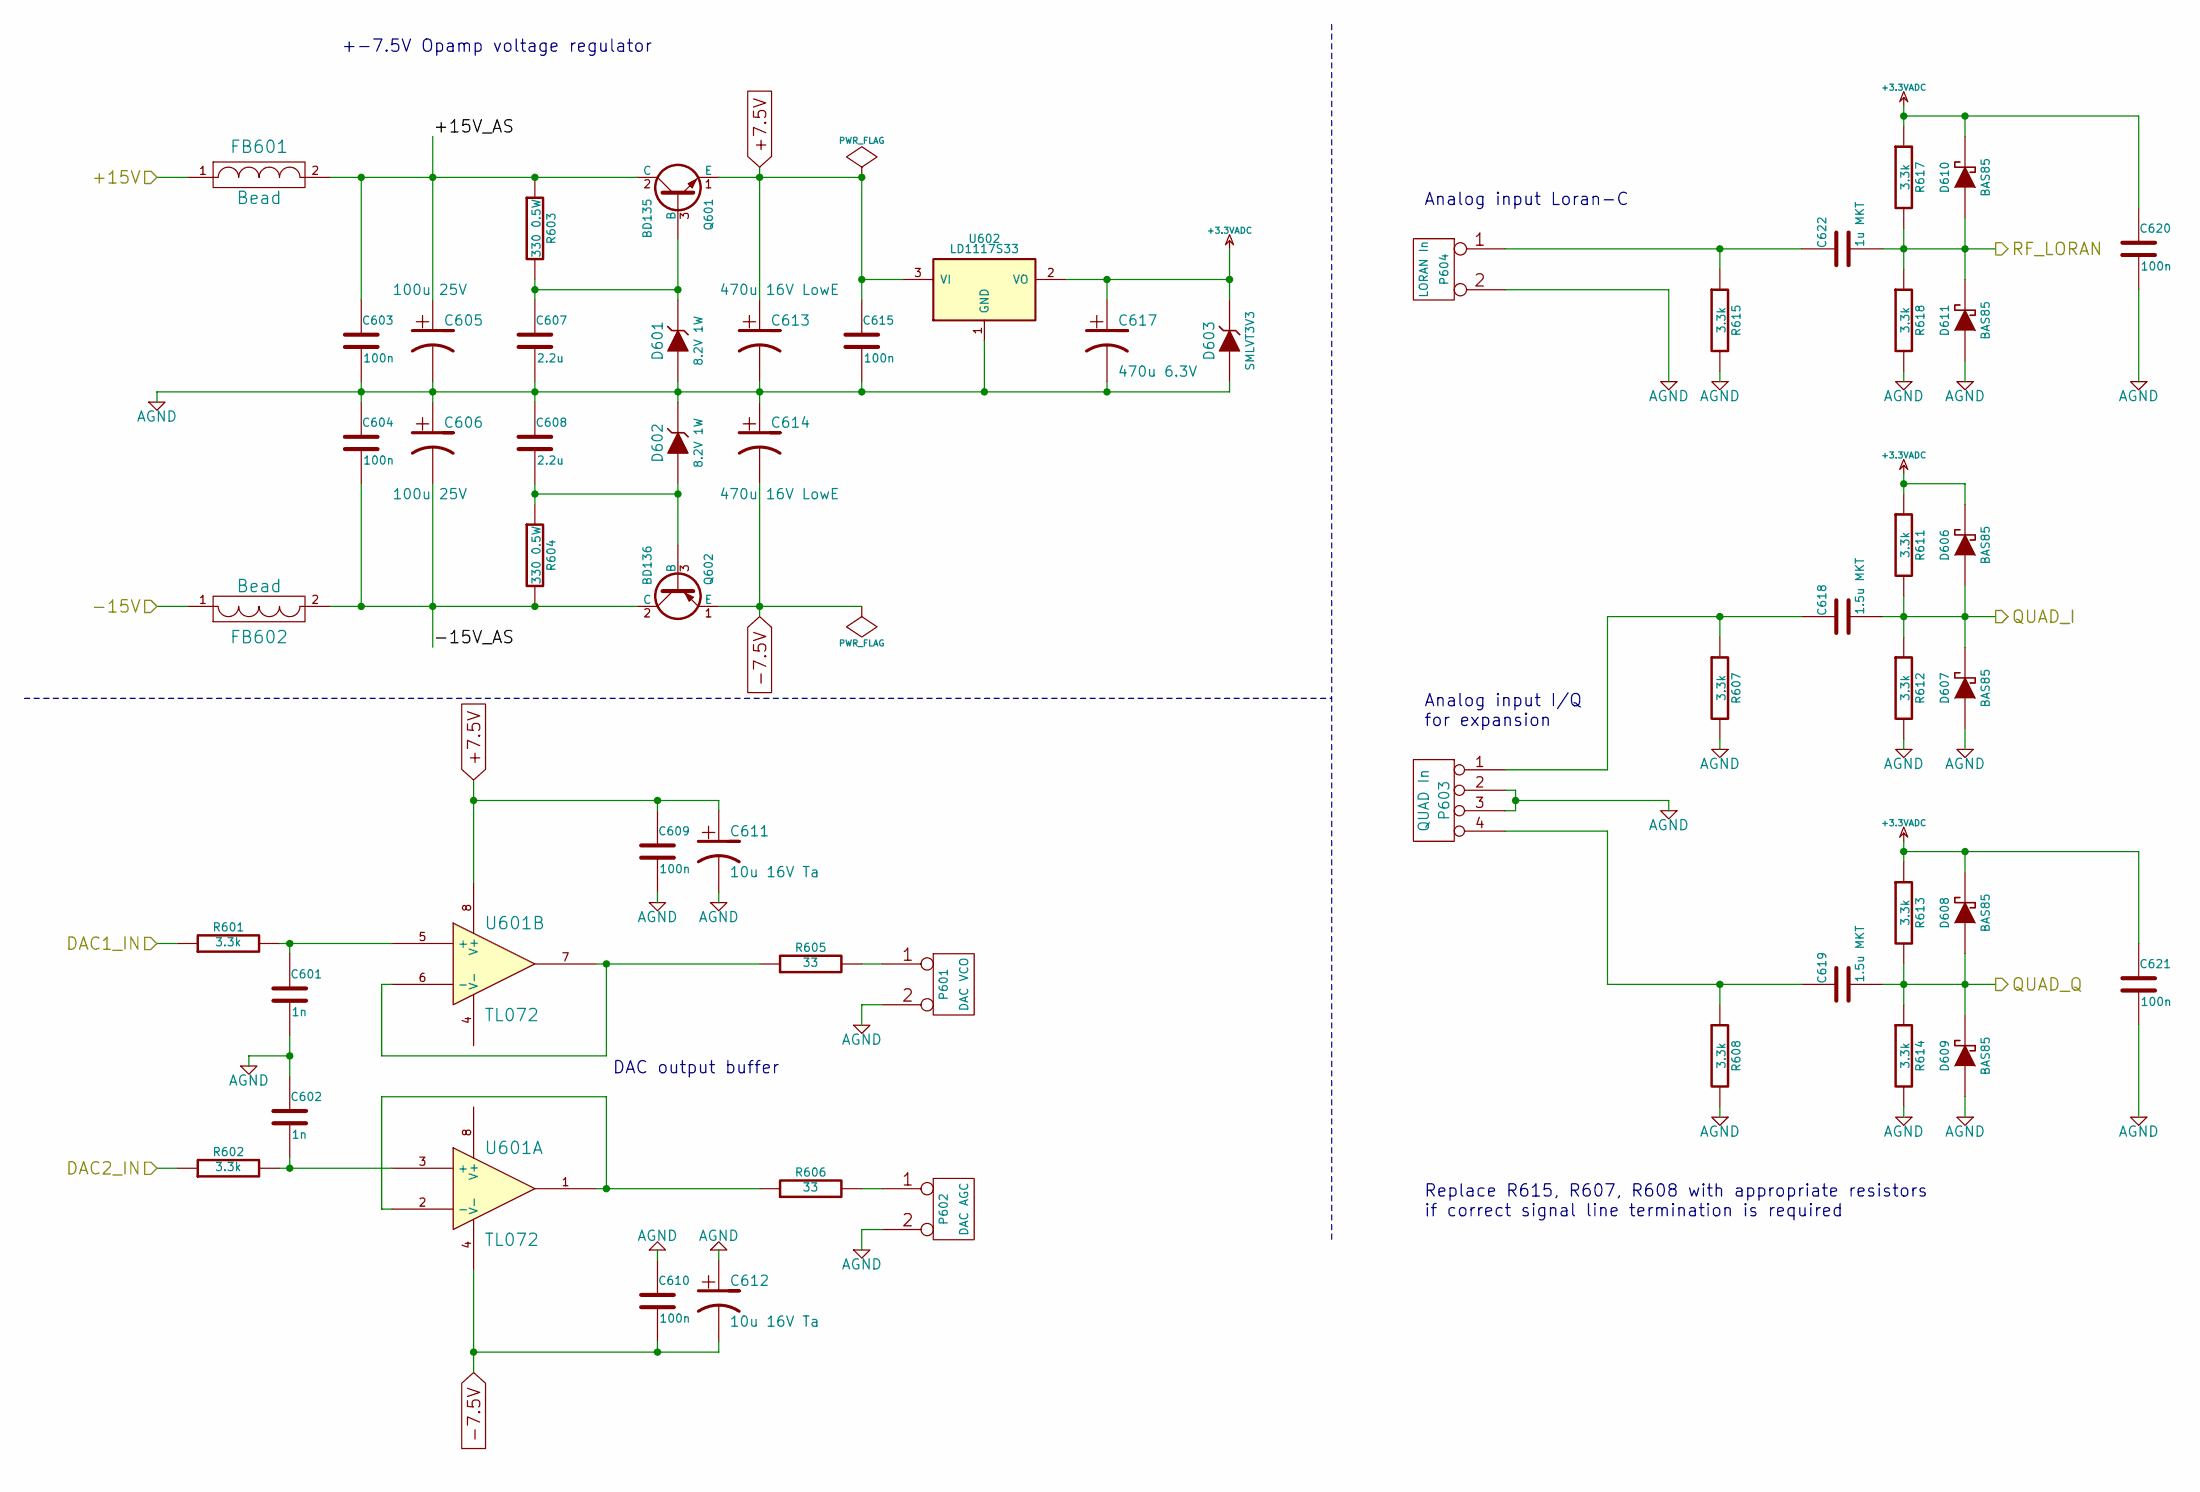
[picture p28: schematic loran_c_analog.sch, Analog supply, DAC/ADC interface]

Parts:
C601, C602: 1n; c_1206
C603, C604, C609, C610, C615, C620, C621: 100n; c_1206
C605, C606: 100u 25V; CP_6.3x11mm
C607, C608: 2.2u; c_1206
C611, C612: 10u 16V Ta; c_tant_B
C613, C614: 470u 16V LowE; CP_10x12.5mm
C617: 470u 6.3V; CP_6.3x11mm
C618, C619: 1.5u MKT; cnp_7x6mm
C622: 1u MKT; cnp_7x6mm
D601, D602: 8.2V 1W; diode_do41
D603: SMLVT3V3; do214aa
D606, D607, D608, D609, D610, D611: BAS85; sod80c
FB601, FB602: Bead; RC07
P601: DAC VCO; kk100_22-23-2021
P602: DAC AGC; kk100_22-23-2021
P603: QUAD In; kk100_22-23-2041
P604: LORAN In; kk100_22-23-2021
Q601: BD135; SOT126_SOT32_Housing_Vertical_BigPads
Q602: BD136; SOT126_SOT32_Housing_Vertical_BigPads
R601, R602, R607, R608, R611, R612, R613, R614, R615, R617, R618: 3.3k; r_1206
R603, R604: 330 0.5W; RC05
R605, R606: 33; r_0805
U601: TL072; so-8
U602: LD1117S33; SOT223

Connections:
+3.3VADC: C617.1, C620.1, C621.1, D603.2 (K), D606.2 (K), D608.2 (K), D610.2 (K), R611.1, R613.1, R617.1, U602.2 (VO); also elsewhere on the board
+7.5V: C609.1, C611.1, C613.1, C615.1, Q601.1 (E), U601.8 (V+), U602.3 (VI)
-7.5V: C610.2, C612.2, C614.2, Q602.1 (E), U601.4 (V-)
/Analog part/+15V: FB601.1; also elsewhere on the board
/Analog part/+15V_AS: C603.1, C605.1, FB601.2, Q601.2 (C), R603.1
/Analog part/-15V: FB602.1; also elsewhere on the board
/Analog part/-15V_AS: C604.2, C606.2, FB602.2, Q602.2 (C), R604.2
/Analog part/DAC1_IN: R601.1; also elsewhere on the board
/Analog part/DAC2_IN: R602.1; also elsewhere on the board
/uC STM32F407/ADC1_IN: C619.2, D608.1 (A), D609.2 (K), R613.2, R614.1; also elsewhere on the board
/uC STM32F407/ADC2_IN: C618.2, D606.1 (A), D607.2 (K), R611.2, R612.1; also elsewhere on the board
/uC STM32F407/ADC3_IN: C622.2, D610.1 (A), D611.2 (K), R617.2, R618.1; also elsewhere on the board
AGND: C601.2, C602.1, C603.2, C604.1, C605.2, C606.1, C607.2, C608.1, C609.2, C610.1, C611.2, C612.1, C613.2, C614.1, C615.2, C617.2, C620.2, C621.2, D601.1 (A), D602.2 (K), D603.1 (A), D607.1 (A), D609.1 (A), D611.1 (A), P601.2 (PM), P602.2 (PM), P603.2, P603.3, P604.2 (PM), R607.2, R608.2, R612.2, R614.2, R615.2, R618.2, U602.1 (GND); also elsewhere on the board
unnamed: C601.1, R601.2, U601.5 (+)
unnamed: C602.2, R602.2, U601.3 (+)
unnamed: C607.1, D601.2 (K), Q601.3 (B), R603.2
unnamed: C608.2, D602.1 (A), Q602.3 (B), R604.1
unnamed: C618.1, P603.1, R607.1
unnamed: C619.1, P603.4, R608.1
unnamed: C622.1, P604.1, R615.1
unnamed: P601.1, R605.2
unnamed: P602.1, R606.2
unnamed: R605.1, U601.6 (-), U601.7
unnamed: R606.1, U601.1, U601.2 (-)

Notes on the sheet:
DAC output buffer
+-7.5V Opamp voltage regulator
Analog input I/Q for expansion
Analog input Loran-C
Replace R615, R607, R608 with appropriate resistors if correct signal line termination is required

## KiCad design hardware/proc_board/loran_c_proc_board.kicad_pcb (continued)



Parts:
C701: 10n; c_1206
C702, C703: 100n; c_1206
C704, C705: 10u 6.3V Ta; c_tant_B
C706, C707, C708, C709, C710, C716: 100n; c_0805
C712, C713: 2.2u 10V CER; c_1206
C714, C715: 15p; c_1206
D701: BAS85; sod80c
JP701: BOOT_SEL; Pin_Header_Straight_1x02
JP702: RESET; Pin_Header_Straight_1x02
R701, R702, R705, R711, R712: 3.3k; r_1206
R703, R704: 3.3k; r_0805
R706, R707, R708, R715: 33; r_0805
R713: 100; r_0805
R716, R717, R718: 33; r_1206
R720: 1.5k; r_1206
U701: STM32F407VG; TQFP-100
X701: 32.768KHz; crystal_tc-38_horiz

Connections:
+3.3VADC: C702.1, C704.1, R713.2, U701.22 (VDDA); also elsewhere on the board
/Analog part/DAC1_IN: U701.29 (PA4/SPI1_NSS/SPI3_NSS/USART2_CK/DCMI_HS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); also elsewhere on the board
/Analog part/DAC2_IN: U701.30 (PA5/SPI1_SCK/OTG_HS_ULPI_CK/TIM2_CH1_ET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); also elsewhere on the board
/Ethernet PHY/RMII_CRS_DV: U701.32 (PA7/SPI1_MOSI/TIM8_CH1N/TIM14_CH1/TIM3_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); also elsewhere on the board
/Ethernet PHY/RMII_MDC: U701.16 (PC1/ETH_MDC/_EVENTOUT); also elsewhere on the board
/Ethernet PHY/RMII_MDIO: R720.1, U701.25 (PA2/USART2_TX/TIM5_CH3/TIM9_CH1/TIM2_CH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); also elsewhere on the board
/Ethernet PHY/RMII_NRST: U701.47 (PB10/SPI2_SCK/I2S2_CK/I2C2_SCL/USART3_T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); also elsewhere on the board
/Ethernet PHY/RMII_REFCLK: U701.24 (PA1/USART2_RTS/UART4_RX/ETH_RMII_REF_CL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); also elsewhere on the board
/Ethernet PHY/RMII_RX0: U701.33 (PC4/ETH_RMII_RX_D0/ETH_MII_RX_D0/EVENTO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); also elsewhere on the board
/Ethernet PHY/RMII_RX1: U701.34 (PC5/ETH_RMII_RX_D1/ETH_MII_RX_D1/EVENTO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); also elsewhere on the board
/Ethernet PHY/RMII_TX0: R707.1; also elsewhere on the board
/Ethernet PHY/RMII_TX1: R708.1; also elsewhere on the board
/Ethernet PHY/RMII_TX_EN: R706.1, R711.1; also elsewhere on the board
/RS232 interface/UART1_CTS: R701.1, U701.70 (PA11/USART1_CTS/CAN1_RX/TIM1_CH4_/OTG_F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); also elsewhere on the board
/RS232 interface/UART1_RTS: R702.1, U701.71 (PA12/USART1_RTS/CAN1_TX/TIM1_ETR/OTG_FS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); also elsewhere on the board
/RS232 interface/UART1_RX: U701.69 (PA10/USART1_RX/TIM1_CH3/OTG_FS_ID/DCMI_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); also elsewhere on the board
/RS232 interface/UART1_TX: U701.68 (PA9/USART1_TX/TIM1_CH2/I2C3_SMBA/DCMI_D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); also elsewhere on the board
/RS232 interface/UART2_CTS: U701.84 (PD3/FSMC_CLK/USART2_CTS/EVENTOUT); also elsewhere on the board
/RS232 interface/UART2_RTS: U701.85 (PD4/FSMC_NOE/USART2_RTS/EVENTOUT); also elsewhere on the board
/RS232 interface/UART2_RX: U701.87 (PD6/FSMC_NWAIT/USART2_RX/EVENTOUT); also elsewhere on the board
/RS232 interface/UART2_TX: U701.86 (PD5/FSMC_NWE/USART2_TX/EVENTOUT); also elsewhere on the board
/SPI interface/SPI_MISO: U701.90 (PB4/NJTRST/SPI3_MISO/TIM3_CH1/SPI1_MISO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); also elsewhere on the board
/SPI interface/SPI_MOSI: R712.1, R718.1; also elsewhere on the board
/SPI interface/SPI_SCK: R717.1; also elsewhere on the board
/SPI interface/SPI_STRB: R716.1; also elsewhere on the board
/uC STM32F407/ADC1_IN: U701.15 (PC0/OTG_HS_ULPI_STP/EVENTOUT); also elsewhere on the board
/uC STM32F407/ADC2_IN: U701.17 (PC2/SPI2_MISO/OTG_HS_ULPI_DIR/ETH_MII_T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); also elsewhere on the board
/uC STM32F407/ADC3_IN: U701.18 (PC3/SPI2_MOSI/I2S2_SD/OTG_HS_ULPI_NXT/E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); also elsewhere on the board
/uC STM32F407/BOOT0: JP701.2, R704.2, U701.94 (BOOT0)
/uC STM32F407/BOOT1: R703.1, U701.37 (PB2/BOOT1/EVENTOUT)
/uC STM32F407/LSE_IN: C714.1, U701.8 (PC14/OSC32_IN/EVENTOUT), X701.1
/uC STM32F407/LSE_OUT: C715.1, U701.9 (PC15/OSC32_OUT/EVENTOUT), X701.2
/uC STM32F407/OSC_IN: U701.12 (PH0/OSC_IN/EVENTOUT); also elsewhere on the board
/uC STM32F407/PPS1: U701.66 (PC9/I2S_CKIN/MCO2/TIM8_CH4/SDIO_D1/I2C3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); also elsewhere on the board
/uC STM32F407/PPS2: U701.65 (PC8/TIM8_CH3/SDIO_D0/TIM3_CH3/USART6_CK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); also elsewhere on the board
/uC STM32F407/PPS3: U701.95 (PB8/TIM4_CH3/SDIO_D4/TIM10_CH1/DCMI_D6/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); also elsewhere on the board
/uC STM32F407/PPS_IN: U701.93 (PB7/I2C1_SDA/FSMC_NL/DCMI_VSYNC/USART1_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); also elsewhere on the board
/uC STM32F407/RELAY1: U701.41 (PE10/FSMC_D7/TIM1_CH2N/EVENTOUT); also elsewhere on the board
/uC STM32F407/RELAY2: U701.42 (PE11/FSMC_D8/TIM1_CH2/EVENTOUT); also elsewhere on the board
/uC STM32F407/RELAY3: U701.43 (PE12/FSMC_D9/TIM1_CH3N/EVENTOUT); also elsewhere on the board
/uC STM32F407/RELAY4: U701.44 (PE13/FSMC_D10/TIM1_CH3/EVENTOUT); also elsewhere on the board
/uC STM32F407/SWCLK: U701.76 (PA14/JTCK/SWCLK/EVENTOUT); also elsewhere on the board
/uC STM32F407/SWDIO: R715.1; also elsewhere on the board
/uC STM32F407/SWNTRST: D701.2 (K); also elsewhere on the board
/uC STM32F407/VBAT: U701.6 (VBAT); also elsewhere on the board
AGND: C702.2, C703.2, C704.2, C705.2, U701.20 (VSSA); also elsewhere on the board
GND: C701.2, C706.2, C707.2, C708.2, C709.2, C710.2, C712.2, C713.2, C714.2, C715.2, C716.2, JP702.1, R701.2, R702.2, R703.2, R704.1, R711.2, R712.2, U701.10 (VSS), U701.27 (VSS), U701.74 (VSS), U701.99 (VSS), X701.3; also elsewhere on the board
unnamed: C701.1, D701.1 (A), JP702.2, R705.1, U701.14 (NRST)
unnamed: C703.1, C705.1, R713.1, U701.21 (VREF+)
unnamed: C712.1, U701.49 (VCAP_1)
unnamed: C713.1, U701.73 (VCAP_2)
unnamed: R706.2, U701.48 (PB11/I2C2_SDA/USART3_RX/OTG_HS_ULPI_D4/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)
unnamed: R707.2, U701.51 (PB12/SPI2_NSS/I2S2_WS/I2C2_SMBA/USART3_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)
unnamed: R708.2, U701.52 (PB13/SPI2_SCK/I2S2_CK/USART3_CTS/TIM1_C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)
unnamed: R715.2, U701.72 (PA13/JTMS/SWDIO/EVENTOUT)
unnamed: R716.2, U701.92 (PB6/I2C1_SCL/TIM4_CH1/CAN2_TX/DCMI_D5/U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)
unnamed: R717.2, U701.89 (PB3/JTDO/TRACESWO/SPI3_SCK/I2S3_CK/TIM2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)
unnamed: R718.2, U701.91 (PB5/I2C1_SMBA/CAN2_RX/OTG_HS_ULPI_D7/ET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)
VDD: C706.1, C707.1, C708.1, C709.1, C710.1, C716.1, JP701.1, R705.2, R720.2, U701.11 (VDD), U701.19 (VDD), U701.28 (VDD), U701.50 (VDD), U701.75 (VDD), U701.100 (VDD); also elsewhere on the board

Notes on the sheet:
GPIO-generated
RMII MDIO/MDC lines: no termination resistors (on uC side), because interface (SMI) is deliberately down-clocked, slew rate controllably decreased via GPIOx_OSPEEDR to reduce ringing



Board: 4 copper layers, 170.0 x 100.0 mm, 243 parts (72 on the bottom side), 173 nets.

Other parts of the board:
LIC1: CC; Symbol_CreativeCommons_CopperTop_Type2_Small
LIC2: BY; Symbol_CC-Attribution_CopperTop_Small
LIC3: SA; Symbol_CC-ShareAlike_CopperTop_Small

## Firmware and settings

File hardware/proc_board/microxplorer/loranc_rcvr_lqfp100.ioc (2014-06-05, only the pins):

PA1.Signal=ETH_RMII_REF_CLK
PA10.Signal=USART1_RX
PA11.Signal=USART1_CTS
PA12.Signal=USART1_RTS
PA13.Signal=SYS_JTMS-SWDIO
PA14.Signal=SYS_JTCK-SWCLK
PA2.Signal=ETH_RMII_MDIO
PA4.Signal=DAC_OUT1
PA5.Signal=DAC_OUT2
PA7.Signal=ETH_RMII_CRS_DV
PA9.Signal=USART1_TX
PB10.Signal=GPIO_Output
PB11.Signal=ETH_RMII_TX_EN
PB12.Signal=ETH_RMII_TXD0
PB13.Signal=ETH_RMII_TXD1
PB2.Signal=GPIO_Input
PB3.Signal=SPI1_SCK
PB4.Signal=SPI1_MISO
PB5.Signal=SPI1_MOSI
PB6.Signal=GPIO_Output
PB7.Signal=TIM4_CH2
PB8.Signal=TIM4_CH3
PC0.Signal=ADC1_IN10
PC1.Signal=ETH_RMII_MDC
PC14-OSC32_IN.Signal=SYS_OSC32_IN
PC15-OSC32_OUT.Signal=SYS_OSC32_OUT
PC2.Signal=ADC2_IN12
PC3.Signal=ADC3_IN13
PC4.Signal=ETH_RMII_RXD0
PC5.Signal=ETH_RMII_RXD1
PC8.Signal=TIM3_CH3
PC9.Signal=TIM3_CH4
PD3.Signal=USART2_CTS
PD4.Signal=USART2_RTS
PD5.Signal=USART2_TX
PD6.Signal=USART2_RX
PE10.Signal=GPIO_Output
PE11.Signal=GPIO_Output
PE12.Signal=GPIO_Input
PE13.Signal=GPIO_Input
PH0-OSC_IN.Signal=SYS_OSC_IN

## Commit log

2014-01-18 Initial commit: microcontroller, RS232 and Ethernet PHY are here
    [loran_c_ethernet.sch, loran_c_proc_board.sch, loran_c_rs232.sch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]
2014-01-23 Almost done: SPI, Relay optocouplers, ADC & DAC interface However, bug needs to be fixed: buses are not connected between hierarchical sheets
    [loran_c_analog.sch, loran_c_ethernet.sch, loran_c_interfacing.sch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]
2014-01-23 FIXED: no more buses on hierarchical sheet ports
    [loran_c_analog.sch, loran_c_ethernet.sch, loran_c_interfacing.sch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]
2014-01-23 Added: complete schematic in PDF
2014-01-24 Update: fix, assign modules to components -Fix P302 incorrect connection -Assign footprints to components (not all yet) -Back-import footprints into schematic fields
    [loran_c_analog.sch, loran_c_ethernet.sch, loran_c_interfacing.sch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]
2014-01-24 Fix: broken annotation, sheet numbers, incorrect 74AC14 package
    [loran_c_analog.sch, loran_c_ethernet.sch, loran_c_interfacing.sch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]
2014-01-25 Update: assign footprint to P101, fix mounting hole symbol (pin # missing)
    [loran_c_proc_board.sch]
2014-01-26 Update: minor schematic rework (due to PCB routing), PCB routing in early stage
    [loran_c_analog.sch, loran_c_ethernet.sch, loran_c_interfacing.sch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]
2014-01-30 Intermediate update: PCB routing/schematic tweaking in process..
    [loran_c_analog.sch, loran_c_ethernet.sch, loran_c_interfacing.sch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]
2014-02-03 Intermediate update #2: PCB routing/schematic tweaking in process
    [loran_c_analog.sch, loran_c_ethernet.sch, loran_c_interfacing.sch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]
2014-02-13 Update: lots of refactoring and pin remap ..In chase for easier PCB routing PCB still not completed
    [loran_c_analog.sch, loran_c_ethernet.sch, loran_c_interfacing.sch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]
2014-02-21 Update: PCB routing still in process...
    [loran_c_analog.sch, loran_c_ethernet.sch, loran_c_interfacing.sch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]
2014-02-23 Update: PCB almost finished (3D views also up-to-date)
    [loran_c_analog.sch, loran_c_ethernet.sch, loran_c_interfacing.sch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]
2014-02-24 Update PCB: fix drill diameters (now only 8 required)
    [loran_c_proc_board.kicad_pcb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]
2014-02-26 PCB Update: no more tracks underneath SMD 0805, added text
    [loran_c_proc_board.kicad_pcb]
2014-02-26 Directory tree restructured more logically (for future expansion)
    [loran_c_analog.sch, loran_c_ethernet.sch, loran_c_interfacing.sch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]
2014-02-26 Update: fixed AGND zone on PCB
    [loran_c_analog.sch, loran_c_ethernet.sch, loran_c_interfacing.sch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]
2014-02-27 PCB prototype production version, minor schematic updates PCB files sent to PCB house. PCB revision as of this commit can be treated as a first (and, hopefully, last) prototype version
    [loran_c_analog.sch, loran_c_interfacing.sch, loran_c_proc_board.kicad_pcb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]
2014-02-27 Generate up-to-date 3D renders ..However, with no packages: latest KiCad revision can't handle that properly :-(
2014-03-05 Fix: nice MiniFit connector schematic symbol
    [loran_c_analog.sch, loran_c_ethernet.sch, loran_c_interfacing.sch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]
2014-03-06 Update: +5V regulator schematic
    [power_supply.sch, regulator_5v.sch]
2014-03-14 Update: added frequecy compensation nets in 5V regulator
    [regulator_5v.sch]
2014-03-14 Update: +-15V regulator schematic almost complete
    [power_supply.sch, regulator_5v.sch, regulator_analog.sch]
2014-03-15 Update: almost finished power supply schematic (incl. +24V)
    [power_supply.sch, regulator_5v.sch, regulator_analog.sch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]
2014-03-19 Update: PCB, schematic fixes -Almost completed power supply PCB -Removed discharge resistors from +-15, +24V supplies: no place on PCB for them -Removed ceramic capacitors (stayed in parallel with el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
    [power_supply.kicad_pcb, power_supply.sch, regulator_5v.sch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]
2014-03-20 Update: PCB gerbers, images. Tagged v0.15
    [power_supply.kicad_pcb, regulator_ocxo.sch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]
2014-03-21 Update: fix schematic overlapping with page frame, add schematic in PDF
    [regulator_analog.sch, regulator_ocxo.sch]
2014-06-05 Added loop antenna preamplifier schematic (built on breadboard now)
    [loop_preamp.sch]
2014-06-05 Added RF board (prototype version)
    [rf_prototype.sch]

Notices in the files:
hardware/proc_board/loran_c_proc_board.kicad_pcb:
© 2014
